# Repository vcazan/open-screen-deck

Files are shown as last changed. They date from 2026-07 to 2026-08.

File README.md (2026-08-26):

# Open Screen Deck

Six Waveshare ScreenKey modules (128×128 IPS + switch in each cap) on an
ESP32-S3 carrier you have fabricated, in a case you print. This repo is
the KiCad, Gerbers, OpenSCAD, STLs, firmware, and an optional desktop
companion.

[Build notes](https://vcazan.github.io/open-screen-deck/) ·
[Latest release](https://github.com/vcazan/open-screen-deck/releases/latest)
(macOS/Windows app + firmware `.bin`) ·
[Discord](https://discord.gg/PVCzBBeGQX)

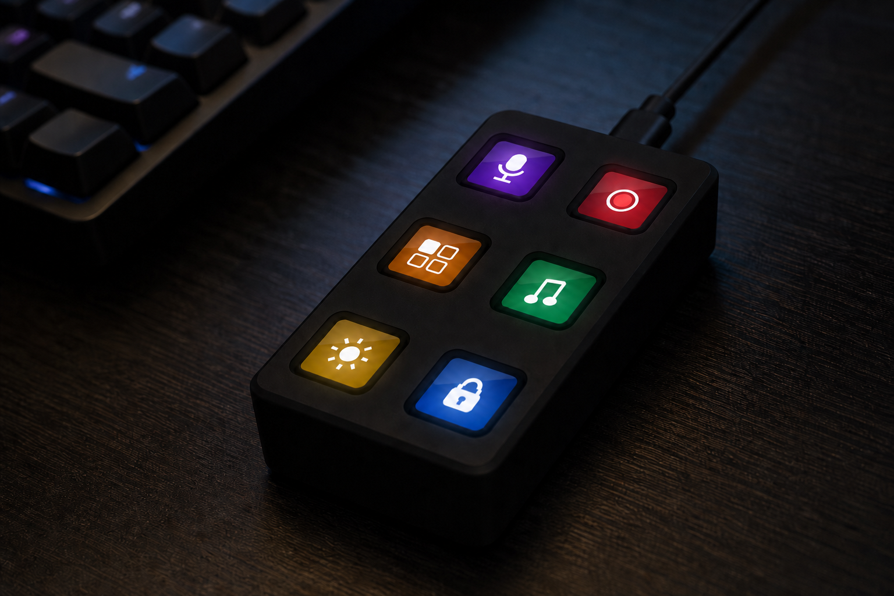
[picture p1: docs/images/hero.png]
Open Screen Deck


## Build one

1. **Order** — 6× [Waveshare 34168](https://www.waveshare.com/0.85inch-screenkey.htm?sku=34168)
   (about $66, longest lead time). Upload
   [`hardware/pcb/data_streamdeck_gerbers.zip`](hardware/pcb/data_streamdeck_gerbers.zip)
   to [JLCPCB](https://jlcpcb.com) (about $15 for five boards). Full list:
   [`hardware/bom_assembly.csv`](hardware/bom_assembly.csv)
2. **Print** while those ship — four STLs in [`hardware/enclosure/stl/`](hardware/enclosure/stl/),
   PETG or PLA+, no supports:
   `deck_bottom_v14.stl`, `deck_top_v14.stl`, `corner_spacers_x4_v14.stl`,
   optional `deck_stand_v14.stl`
3. **Assemble** — [guide](https://vcazan.github.io/open-screen-deck/build/assembly/),
   about 45 minutes
4. **Flash** over USB-C — [companion](https://github.com/vcazan/open-screen-deck/releases/latest)
   (Settings → Firmware) or Arduino /
   [esptool](https://vcazan.github.io/open-screen-deck/firmware/flashing/).
   Same release has `firmware-0.14.5.bin` plus bootloader and partitions.

Parts land around **$100**. The six modules are most of that. v14 STLs
match the **Rev E** board (59.5 × 108.5 mm); don’t mix with older v13 prints.

| | |
|--|--|
| **Keys** | 6× Waveshare 0.85″ ScreenKey (SKU 34168) |
| **Board** | ESP32-S3-WROOM-1-N16R8 on a **59.5 × 108.5 mm** Rev E carrier |
| **On board** | IMU, VEML7700 ALS, DRV2605L haptics, piezo, 8× SK6812, Qwiic |
| **Displays** | Dual SPI (J1–J3 + SD / J4–J6), 40 MHz + DMA |
| **Case** | 64.9 × 113.9 × 28.2 mm printed deck + optional 25° stand |
| **Firmware** | 0.14.5 (protocol 14) — HID keyboard F13–F24 by default |

Pinout lives in [`hardware/pinout.py`](hardware/pinout.py). Generators
refuse to run if `firmware/config.h` disagrees.

## Firmware

Sources in [`firmware/`](firmware/). Out of the box it types F13–F24.
Pages, labels, icons, microSD animations, auto-dim, glow LEDs, and haptics
are configured over USB serial
([protocol](https://vcazan.github.io/open-screen-deck/firmware/protocol/)).

Prebuilt images are on
[Releases](https://github.com/vcazan/open-screen-deck/releases/latest)
(`firmware-0.14.5.bin`, `.bootloader.bin`, `.partitions.bin`). The companion
bundles the same files. To compile locally:

```bash
./scripts/build_firmware.sh          # also copies bins into the app
./scripts/build_firmware.sh --flash  # then upload to a connected deck
```

Arduino: ESP32S3 Dev Module, USB CDC On Boot enabled, USB-OTG, OPI PSRAM,
16 MB flash (`app3M_fat9M_16MB`). Libraries: Adafruit GFX, ST7735, NeoPixel.

## Companion app

Optional. The deck is a USB keyboard without it. Use the app to draw key
faces, bind host actions, flash firmware, and (on Rev E) drive auto-dim /
glow / self-test.

- **Download:** [Releases](https://github.com/vcazan/open-screen-deck/releases/latest)
  — macOS `.dmg` (unsigned: right-click → Open), Windows `.msi`
- **From source:** `cd app && npm install && npx tauri dev`
- **Plugins:** folders in [`plugins/`](plugins/);
  [directory](https://vcazan.github.io/open-screen-deck/plugins/) ·
  [`plugins/registry.json`](plugins/registry.json)

A push to `main` updates this repo and the docs site. A **GitHub Release**
(installers + firmware bins) is created only when a tag `app-v*` is pushed,
e.g. `app-v0.2.0`.

## Repo map

```
hardware/
  pinout.py          Canonical GPIO + Rev E geometry
  pcb/               KiCad, Gerbers, board BOM
  enclosure/         OpenSCAD v14 + printable STLs
  3d/                Fastener / assembly STEP
firmware/            ESP32-S3 Arduino (0.14.5)
app/                 Tauri companion (Rust + React)
plugins/             Bundled plugins + registry.json
profiles/            Shared layouts (.osdprofile.json)
docs/                MkDocs site
scripts/             PCB / schematic / firmware helpers
```

## Contributing

- **Plugins** — folder in `plugins/` + a registry line
  ([how](https://vcazan.github.io/open-screen-deck/plugins/develop/))
- **Profiles** — export from the app, PR into `profiles/`
- **Hardware** — OpenSCAD is parametric; keep the
  [mechanical contract](docs/mechanical_contract.md) if the PCB should still fit
- **App / firmware** — `cd app && npm test && npm run test:e2e`

## Related projects

Same neighbourhood: [FreeTouchDeck](https://github.com/DustinWatts/FreeTouchDeck)
(one touchscreen), [open-deck](https://github.com/joshr120/open-deck) (one TFT
behind keys), [MacroPad](https://github.com/yuvasaro/MacroPad) (per-key OLED).
This one is six discrete ScreenKey modules on a carrier you can order.

## License

- **Firmware, app, scripts, docs:** [MIT](LICENSE)
- **Hardware (PCB + enclosure):** [CERN-OHL-P v2](hardware/LICENSE)

ScreenKey modules are a [Waveshare](https://www.waveshare.com) product; this
project is not affiliated with or endorsed by Waveshare or Elgato.

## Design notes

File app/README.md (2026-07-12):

# Open Screen Deck Configurator

Browser-based companion app for configuring the [Open Screen Deck](https://github.com/vcazan/open-screen-deck) — a 6-key macro pad with per-key 128×128 IPS LCD displays, driven by an ESP32-S3 over USB.

Configure key labels, colors, HID bindings, icons, and SD animations. Test everything in the built-in device simulator before connecting real hardware via Web Serial.

## Quick start

```bash
cd app
npm install
npm run dev      # http://localhost:5173
npm run test     # protocol unit tests
npm run build    # production bundle
```

## Architecture

```
app/src/
├── protocol/       # Serial protocol v0.4 — types, codec, RGB565 helpers
├── transport/      # Transport abstraction (simulator loopback + Web Serial)
├── simulator/      # Virtual firmware mirroring firmware/ behavior
├── ui/             # React components (deck, inspector, console)
├── hooks/          # Device connection state management
└── utils/          # Profile import/export, animation decoding
```

### Protocol layer (`protocol/`)

Implements the newline-delimited JSON protocol defined in `docs/protocol.md` v0.4:

- **Commands**: `PING`, `INFO`, `GET_KEYS`, `DRAW`, `DRAW_ALL`, `SET_KEY`, `SET_IMAGE`, `ANIM`, `SD_INFO`
- **Events**: `info`, `key`, `key_state`, `pong`, `ok`, `error`, `send_data`, `anim`, `sd`
- **Binary framing**: `SET_IMAGE` sends a JSON header, device replies `send_data`, host streams 32 768 bytes RGB565

RGB565 conversion uses big-endian byte order matching Adafruit GFX / ST7735.

### Transport layer (`transport/`)

All device I/O goes through a `Transport` interface so the app can later be wrapped in Tauri without changing UI code:

| Implementation | Purpose |
|---|---|
| `SimulatorTransport` | In-process loopback to `SimulatedDevice` (default) |
| `WebSerialTransport` | Real hardware via `navigator.serial` at 115200 baud |

### Simulator (`simulator/`)

`SimulatedDevice` is a faithful virtual firmware:

- 6 keys with label view renderer matching `drawKey()` in `firmware/display.cpp`
- Handles every protocol command identically to the ESP32 firmware
- Key presses emit `{"event":"key",...}` and simulate HID keystrokes
- NVS persistence via `localStorage` (survives page reload)
- In-memory SD card for icons and animation frame sequences

### UI (`ui/`)

Dark-themed single-page layout:

- **Left**: CSS device rendering with live 128×128 key canvases
- **Right**: Progressive-disclosure inspector for the selected key
- **Bottom**: Collapsible protocol console (TX/RX log)

## Simulator vs real hardware

| Feature | Simulator | Real device |
|---|---|---|
| Key press events | Click on deck | Physical switch |
| HID output | Shown as floating chip | Sent over USB HID |
| NVS config | `localStorage` | ESP32 Preferences |
| SD storage | `localStorage` (base64 frames) | microSD card |
| SET_IMAGE | Draws to canvas + saves icon | ST7735 + SD write |
| ANIM | Plays from in-memory frames | Reads `/osd/keys/n/anim/*.rgb565` |

The same `encodeCommand()` / `Transport.sendLine()` code drives both paths.

## Profiles

Save/load the full 6-key configuration as JSON:

```json
{
  "version": 1,
  "keys": [
    { "label": "MUTE", "sublabel": "Toggle", "hid": 183, "bg": 19049, "fg": 65535 }
  ]
}
```

Use **Save profile** / **Load profile** in the header, or **Reset defaults** to restore firmware factory labels.

## Future: Tauri wrapper

The transport abstraction is designed for a future Tauri shell:

1. Replace `WebSerialTransport` with a Tauri IPC bridge calling `serialport` crate
2. Keep `SimulatorTransport` for offline development
3. No changes needed to protocol, simulator, or UI layers

## License

Same as the parent Open Screen Deck project (MIT firmware, CERN-OHL-P hardware).

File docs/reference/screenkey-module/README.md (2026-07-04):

# Waveshare 0.85″ ScreenKey Module — Reference

Canonical mechanical + electrical reference for **Open Screen Deck**.  
Sources: [Waveshare product page (SKU 34168)](https://www.waveshare.com/0.85inch-screenkey.htm?sku=34168), [Waveshare docs](https://docs.waveshare.com/0.85inch-ScreenKey-Module-W), outline drawing (see `outline-dimensions.png`).

**Our build SKU:** 34168 — **0.85inch ScreenKey Module B** (black keycap + switch + PCB)

---

## Product variants

| SKU | Product |
|-----|---|
| 34086 | ScreenKey LCD W (display + cap only) |
| 34087 | ScreenKey LCD B |
| 34167 | ScreenKey Module W (cap + switch + PCB) |
| **34168** | **ScreenKey Module B** ← use this |

**In the box (34168):**

1. ScreenKey Module B host ×1  
2. **MX1.25 9-pin 200 mm** cable ×1  

Weight: ~0.017 kg per module

---

## Display & logic

| Parameter | Value |
|---|---|
| Panel | 0.85″ IPS |
| Resolution | 128 × 128 |
| Color | 65K (RGB565) |
| Driver IC | **ST7735** |
| Interface | 4-wire SPI |
| Operating voltage | **3.3 V** (5 V tolerant per docs — run at 3.3 V) |
| Visible display area | **15.21 × 15.21 mm** |
| Pixel pitch | 118.8 × 118.8 µm |

---

## Mechanical switch (Module W/B only)

| Parameter | Value |
|---|---|
| Actuation force | 50 ± 10 gf |
| Bottom-out force | 55 ± 10 gf |
| Actuation travel | 1.20 ± 0.30 mm |
| Total travel | 2.80 ± 0.25 mm |
| Spring length | 15.50 mm |
| Lifespan | 50 million cycles |

---

## Outline dimensions (from Waveshare drawing)

See **`outline-dimensions.png`** in this folder.

### Front (face toward user)

| Dimension | mm |
|---|-----|
| Mounting hole centres (horizontal) | **22.00** |
| Mounting hole centres (vertical) | **25.30** |
| Visible LCD (square) | **15.21 × 15.21** |

Four corner mounting holes on this 22.00 × 25.30 mm pattern.

### Back (PCB + connector)

| Dimension | mm |
|---|-----|
| PCB width | **25.94** |
| PCB height | **35.29** |

9-pin header on PCB edge ( mates with included cable ).

### Side (profile)

| Dimension | mm |
|---|-----|
| **Total stack height** (cap tip → standoff bottom) | **24.00** |
| Keycap depth (cap only) | **8.60** |

Module includes rear **brass standoffs** — total height is **not** just the 8.6 mm cap; plan enclosure depth for **~24 mm** or confirm standoffs are removed/shortened for our carrier design.

---

## 9-pin cable — SPI module interface

Connector on module: **9-pin 1.25 mm pitch** (product cable: MX1.25).  
Pin order per Waveshare docs (SPI control interface):

| Pin | Signal | Notes |
|-----|---|---|
| 1 | **KEY** | Button, active level per firmware |
| 2 | **DC** | Data/command (Lo = cmd, Hi = data) |
| 3 | **CS** | Chip select, active low |
| 4 | **SCLK** | SPI clock |
| 5 | **DIN** | SPI MOSI |
| 6 | **GND** | |
| 7 | **VCC** | 3.3 V |
| 8 | **PWM** | Backlight (BL) |
| 9 | **RST** | Reset, active low |

### Open Screen Deck GPIO map (carrier PCB)

| Module | CS | KEY |
|---|-----|-----|
| J1 | GPIO 10 | GPIO 38 |
| J2 | GPIO 1 | GPIO 39 |
| J3 | GPIO 2 | GPIO 40 |
| J4 | GPIO 3 | GPIO 41 |
| J5 | GPIO 4 | GPIO 42 |
| J6 | GPIO 5 | GPIO 47 |

Shared: MOSI=11, SCK=12, DC=14, RST=21, BL(PWM)=13

---

## ⚠️ CAD status

Enclosure v4 + PCB brief aligned to this reference (2026-07-03).

---

## Links

- Product: https://www.waveshare.com/0.85inch-screenkey.htm?sku=34168  
- Wiki: https://docs.waveshare.com/0.85inch-ScreenKey-Module-W  
- Resources: https://docs.waveshare.com/0.85inch-ScreenKey-Module-W/Resources-And-Documents  
- Demo code: Waveshare GitHub / example packages linked from wiki  

---

## Files in this folder

| File | Description |
|---|---|
| `README.md` | This document |
| `outline-dimensions.png` | Official-style outline (front / back / side) |
| `product-spec.json` | Machine-readable spec snapshot |

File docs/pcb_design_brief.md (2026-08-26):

# Open Screen Deck — Carrier PCB Design Brief (Rev E)

Reference: `docs/reference/screenkey-module/` (Waveshare **SKU 34168**)
**Canonical pinout: `hardware/pinout.py`** — both generators consume it and
cross-check `firmware/config.h` at generation time. Regenerate with
`python3 scripts/generate_kicad_pcb.py`, route with Freerouting, then run
`scripts/stitch_gnd.py` and DRC. Fab outputs live in `hardware/pcb/gerbers/`.

---

## Board specification

| Parameter | Value |
|---|---|
| PCB size | **59.5 × 108.5 mm** (Rev E — grew for uniform key spacing) |
| Shape | Rectangular (r=4 corners), 4× Ø2.2 corner case-screw holes on the corner-module standoff axes |
| Mounting | **Flat** in bottom shell (centred under key grid) |
| Layers | 2-layer |
| Min trace | 0.2 mm signal / 0.5 mm power |
| Min via | 0.3 mm drill / 0.6 mm pad |
| Finish | ENIG, matte black solder mask |

---

## Layout

### Key grid (the Rev E spacing fix)

Uniform **11 mm cap-to-cap gaps** both axes: column pitch **33.0 mm**, row
pitch **36.3 mm** (was 28.9 / 38.3 → 6.9 mm H / 13.0 mm V gaps).

| Ref | Col | Row | X | Y |
|-----|-----|-----|---|---|
| J1 | 0 | 0 | 13.25 | 17.95 |
| J2 | 1 | 0 | 46.25 | 17.95 |
| J3 | 0 | 1 | 13.25 | 54.25 |
| J4 | 1 | 1 | 46.25 | 54.25 |
| J5 | 0 | 2 | 13.25 | 90.55 |
| J6 | 1 | 2 | 46.25 | 90.55 |

### Major placements (board origin = back-left)

| Ref | Part | Position | Notes |
|-----|---|---|---|
| U1 | ESP32-S3-WROOM-1-N16R8 | (29.75, 36.1) rot 90 | Centre corridor between rows 0 and 1 |
| J7 | USB-C GCT USB4105 (horizontal) | (29.75, 3.1) rot 180 | Port exits rear edge Y=0 |
| J8 | microSD Hirose DM3D-SF | (52.0, 72.4) rot 90 | Card mouth faces x=59.5 edge (side-wall slot); gated by `check_sd_orientation.py` |
| U2 | AMS1117-3.3 1 A LDO | (11.4, 4.7) rear-left strip | VBUS→3V3; ≥3.0 mm clear of H1 screw hardware |
| U3 | USBLC6-2SC6 ESD | behind J7 | USB D+/D−/VBUS protection |
| U4 | LSM6DS3TR-C IMU | rear strip | I2C, INT1→GPIO9 (pickup/tap) |
| U5 | VEML7700 ambient light | rear strip | I2C, drives BL auto-dim |
| U6 | DRV2605L haptic driver | rear strip | I2C + EN=GPIO44, LRA on J10 |
| U7 | 74AHCT1G125 | near U1 | 3V3→5V level shift for LED data |
| J9 | Qwiic / StemmaQT (JST-SH 4P) | (49.0, 3.1) right rear edge | 3V3 I2C expansion; ≥3.0 mm clear of H2 screw hardware |
| J10 | LRA motor (JST-SH 2P) | rear strip | haptic actuator |
| BZ1 | Piezo buzzer | rear strip | GPIO43 LEDC |
| D1–D6 | SK6812MINI-E | beside each key, outer edge | per-key status color |
| D7–D8 | SK6812MINI-E | rear corners | link / SD status |
| SW1/SW2 | BOOT / RESET | front strip (42.5, 105.2) / (49.0, 105.2) | GPIO0 strap / EN; next to ALS, clear of rear-strip congestion |

---

## Connectors J1–J6

**Molex PicoBlade 53261-0971** — 9-pin 1.25 mm right-angle SMD.
The 200 mm cable included in every Waveshare module box plugs straight in
(pin 1 → pin 1; verify straight-through before buying spares).

### Pin order (Waveshare SPI module — pin 1 = KEY)

| Pin | Signal | Bus A modules (J1–J3) | Bus B modules (J4–J6) |
|-----|---|---|---|
| 1 | KEY | GPIO per table below | GPIO per table below |
| 2 | DC | GPIO 14 (DC_A) | GPIO 8 (DC_B) |
| 3 | CS | GPIO per table below | GPIO per table below |
| 4 | SCLK | GPIO 12 (SCK_A) | GPIO 18 (SCK_B) |
| 5 | DIN | GPIO 11 (MOSI_A) | GPIO 17 (MOSI_B) |
| 6 | GND | GND | GND |
| 7 | VCC | +3V3 | +3V3 |
| 8 | PWM | GPIO 13 (BL, LEDC) | GPIO 13 (BL, LEDC) |
| 9 | RST | GPIO 21 (shared) | GPIO 21 (shared) |

### Per-module GPIO

| Module | Bus | CS | KEY |
|---|-----|-----|-----|
| J1 | A | 10 | 38 |
| J2 | A | 1 | 39 |
| J3 | A | 2 | 40 |
| J4 | B | 3 | 41 |
| J5 | B | 4 | 42 |
| J6 | B | 5 | 47 |

**Dual SPI**: bus A (FSPI) also carries the microSD (CS=16, MISO=15) at
10 MHz; panels run 40 MHz with DMA on both buses simultaneously —
full-deck redraw drops ~60 ms → ~15-18 ms.

### Other subsystem GPIO

| Signal | GPIO | Notes |
|---|---|---|
| SDA / SCL | 6 / 7 | I2C: IMU + ALS + haptics + Qwiic |
| IMU_INT | 9 | LSM6DS3TR-C INT1, wake-on-pickup |
| LED_DATA | 48 | SK6812 chain, 5 V via 74AHCT1G125 |
| PIEZO | 43 | LEDC tone |
| HAPTIC_EN | 44 | DRV2605L EN |

All chosen pins avoid IO35–37 (octal PSRAM) and leave the strap pins clean.

---

## Decoupling

- **C1–C6:** 100 nF 0402 on each Jx pin 7 (VCC), ≤2 mm from connector
- **C7/C8:** 10 µF 0805 bulk at LDO in/out
- **C9/C10:** 100 nF at U1; **C11** 1 µF on EN
- 100 nF at U4, U5, U6, U7 + 10 µF near the LED chain 5 V feed

---

## Mounting holes

All Ø2.2 (M2 free fit):

- **H1–H4 corner case screws** @ **(3.25, 3.32), (56.25, 3.32), (3.25, 105.17), (56.25, 105.17)** —
  on the corner modules' outermost soldered-nut axes (M2×25 case screws,
  see `docs/mechanical_contract.md`)
- **H5–H16 module standoffs** @ the usable positions of the **20.0 × 29.25**
  per-module pattern from the official vendor drawing (positions colliding
  with ESP32 / USB-C / microSD skipped)

**Hardware keepouts** (component courtyards, measured from hole centre):
≥ **3.0 mm** at H1–H4 (M2 spacer/nut seats on the board face) and
≥ **2.0 mm** at H5–H16 (Ø3.5 mm brass standoff foot; ≥2.5 mm preferred).
Violations at H1/H2/H14 (U2, J9, C14) were found and fixed in Rev E.

---

## Never-again gates (CS2/CS3 class defects)

1. `hardware/pinout.py` is the only pin source; generators fail if
   `firmware/config.h` diverges.
2. `check_dangling_nets` — every signal net must land on ≥2 pads
   (single-pad nets are invisible to DRC; this exact defect shipped Rev B–D).
3. Pre-Gerber connectivity gate: schematic netlist vs PCB pad diff for
   every connector pin.
4. Firmware `SELFTEST` draws each panel's index + cycles LEDs at bring-up.

---

## BOM (deltas vs Rev D marked ★)

| Qty | Ref | Part |
|-----|-----|---|
| 6 | J1–J6 | Molex PicoBlade 53261-0971 (MX1.25 9P) |
| 1 | U1 | ESP32-S3-WROOM-1-N16R8 |
| 1 | J7 | GCT USB4105-GF-A USB-C |
| 1 | J8 | Hirose DM3D-SF microSD |
| 1 | U2 | ★ AMS1117-3.3 (1 A) |
| 1 | U3 | USBLC6-2SC6 |
| 1 | U4 | ★ LSM6DS3TR-C IMU |
| 1 | U5 | ★ VEML7700 ambient light |
| 1 | U6 | ★ DRV2605L haptic driver |
| 1 | U7 | ★ 74AHCT1G125 level shifter |
| 8 | D1–D8 | ★ SK6812MINI-E RGB LED |
| 1 | BZ1 | ★ SMT piezo buzzer (CUI CPT-9019S) |
| 1 | J9 | ★ JST-SH 4P (Qwiic) |
| 1 | J10 | ★ JST-SH 2P (LRA motor) |
| 1 | — | ★ LRA coin motor (8 mm) |
| — | C/R | 0402/0805 passives per schematic |
| 4 | — | M2×25 case screws + RX-M2x4 inserts |

Added BOM cost ≈ **$4–6/board**.

---

## Fabrication

- **59.5 × 108.5 mm** 2-layer FR4 1.6 mm, ENIG
- JLCPCB / PCBWay: ~$15 / 5 pcs

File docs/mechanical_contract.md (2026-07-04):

# Mechanical Contract — Enclosure ↔ PCB (v11 / Tier B)

Single source of truth for physical interfaces.  
**Module reference:** `docs/reference/screenkey-module/` (Waveshare SKU **34168**)

---

## Outer envelope (v11 — flat deck + separate stand)

Architecture follows the Elgato Stream Deck Module reference: the deck body is
a **flat slab**; a **separate printed stand** provides the desk angle.

| Parameter | Value |
|---|---|
| Deck width (X) | **59.7 mm** |
| Deck depth (Y) | **116.7 mm** |
| Deck height | **28.2 mm** (+3.4 mm keycap protrusion) |
| Parting plane | **Z = 12 mm** (bottom tray / top shell) |
| Stand angle | **25°** (separate print, cradle style) |
| Stack | floor 3.0 → posts 3.0 → PCB 1.6 → standoff/spacer 9.7 → module body 5.7 → gap 0.2 → face plate 5.0 |

---

## Carrier PCB (Tier B — fab-ready)

| Parameter | Value |
|---|---|
| Board outline | **55 × 112 mm** |
| Orientation | Flat in bottom shell, centred under key grid |
| MCU | **ESP32-S3-WROOM-1-N16R8** soldered on board |
| USB | **USB-C receptacle** on PCB @ **X=27.5 mm, Y=0** (rear edge) |
| Storage | **microSD** @ **X=47.5 mm, Y=75 mm** (right-wall access slot, between J4/J6) |
| ScreenKey | 6× JST GH 9P @ J1–J6 (see below) |

### Corner case-screw holes H1–H4 (Ø2.2, board origin = back-left)

These sit on the **corner modules' outermost standoff axes** — the case
screws thread through the modules' soldered nuts (see Fasteners below).

| Hole | X | Y |
|---|---|---|
| H1 | 2.0 | 4.95 |
| H2 | 52.9 | 4.95 |
| H3 | 2.0 | 106.85 |
| H4 | 52.9 | 106.85 |

Plus 12× Ø2.2 module-standoff holes (H5–H16) at the remaining usable
standoff positions.

### J1–J6 connector centres

| Ref | X | Y |
|-----|---|---|
| J1 | 13.0 | 17.6 |
| J2 | 41.9 | 17.6 |
| J3 | 13.0 | 55.9 |
| J4 | 41.9 | 55.9 |
| J5 | 13.0 | 94.2 |
| J6 | 41.9 | 94.2 |

**Pin order (Waveshare):** 1=KEY, 2=DC, 3=CS, 4=SCLK, 5=DIN, 6=GND, 7=VCC, 8=PWM, 9=RST  
**Receptacle:** Molex **PicoBlade 53261-0971** (= "MX1.25") — the in-box Waveshare cable mates directly.

---

## USB-C (PCB-mounted)

| Parameter | Value |
|---|---|
| Connector | GCT USB4115-03-C class (rear-facing) |
| PCB position | Centre **X = 27.5 mm**, flush **Y = 0** rear edge |
| Enclosure slot | 10.5 × 4.8 mm @ rear wall (unchanged) |
| Power | USB 5 V → on-board 3.3 V LDO |

**No DevKit pocket.** One USB-C cable plugs directly into the deck.

---

## microSD (media storage)

| Parameter | Value |
|---|---|
| Connector | Hirose DM3D-SF class push-push |
| PCB position | **X = 47.5 mm, Y = 75 mm** (card ejects through right wall) |
| Enclosure | Right-wall slot in bottom shell @ PCB Y=75 |
| Filesystem | FAT32, `/osd/` tree (see `docs/product_architecture.md`) |

---

## Fasteners (v11 — one-screw corner stack)

The ScreenKey module is a **dual-PCB sandwich**: front PCB (switch/LCD) and
rear PCB (9P connector) joined by **soldered M2 nuts** at the 22.0 × 25.3
pattern. The factory brass standoffs **unscrew from those nuts** — the nuts
are the mounting threads, and they are **through-threads**: a long screw can
pass through and keep going. The module is off-the-shelf and is never
modified — only its removable standoffs are swapped where needed.

**The 4 case screws ARE the corner-module screws.** At each deck corner one
long M2 runs the entire stack:

```
M2×25 countersunk head (DIN 965, flush in the rubber-foot recess)
  → tray floor (3.0)
  → PCB perch post (3.0)
  → carrier corner hole H1–H4 (Ø2.2 @ kicad 2/52.9, 4.95/106.85)
  → printed spacer sleeve Ø4×9.7 (replaces the factory standoff,
    open Ø2.4 bore)
  → corner module's soldered M2 nut (threads through)
  → RX-M2x4 insert in the top-shell face plate (4 mm engagement)
```

One screw per corner marries **bottom tray + carrier + module + top shell**.

**Assembly order:**

```
1. Modules → carrier:  M2×5 from the carrier underside into the factory
                       standoff tips (12 non-corner positions). At the
                       4 deck corners swap the factory standoff for the
                       printed spacer sleeve.
2. Cables:             6× in-box PicoBlade cables, module → carrier.
3. Carrier → tray:     drop onto the 4 corner posts.
4. Close:              snap top shell on (tongue + snaps), then 4× M2×25
                       from below, straight through the corner modules'
                       nuts into the top-plate inserts.
```

| Joint | Hardware | Receives |
|---|---|---|
| Whole stack (tray + carrier + module + top) | 4× **M2×25 countersunk flat head** (DIN 965) from below, hidden under the rubber feet | Corner module's **soldered M2 nut** (pass-through), then **Ruthex RX-M2x4** insert in the top-shell plate |
| Module → carrier | 12× **M2×5 hex socket cap** (ISO 4762) from carrier underside | Module's **factory brass standoffs** (female M2 tips) |
| Corner spacing | 4× **printed spacer sleeve** Ø4 × 9.7, Ø2.4 bore (`stl/corner_spacers_x4_v11.stl`) | sits between carrier and corner-module nut |
| Feet | 8× Ø10 self-adhesive rubber (deck + stand); the 4 deck feet cover the corner screw heads | — |

The factory standoffs (and corner sleeves) are 9.7 mm — exactly clearing the
mated PicoBlade cable under each module. Standoffs at the 8 skipped positions
(over ESP32 / USB-C / microSD) are simply unscrewed.

Real CAD models (in the Fusion assembly + `hardware/3d/fasteners/`):
official **Ruthex** STEP files and **ISO-standard screws** from step.parts.

Install the 4 RX-M2x4 inserts in the top-plate holes with a soldering iron
@ ~220 °C before assembly.
Full parts list: `hardware/bom_assembly.csv` (PCB-only: `hardware/pcb/bom.csv`).

---

## Assembly stack

```
Top shell → 6× ScreenKey modules (24 mm bays)
         → MX1.25/JST cables
Bottom   → Carrier PCB (ESP32 + USB-C + SD + J1–J6)
         → M3 standoffs → enclosure bosses
```

---

## Verification

- [ ] Gerbers ordered from `hardware/pcb/gerbers/`
- [ ] USB-C aligns with rear slot when PCB on standoffs
- [ ] microSD accessible without opening top shell
- [x] **Corner nut is a through-thread** — confirmed from module photos
  (open corner holes on the front face); M2×25 passes through and exits
  toward the top-plate insert
- [ ] Real 34168 module fits top bays
- [ ] **Keycap aperture:** `CAP_W = 19.4` in the SCAD is an estimate — measure a
  real cap and adjust before final print
- [ ] Deck seats in stand cradle; USB cable clears stand rear

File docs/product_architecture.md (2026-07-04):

# Product Architecture — Fab-Ready Open Screen Deck

**Revision:** 2.0 (Tier B)  
**Status:** Target production design — no socketed dev kit, no “works on breadboard” shortcuts.

---

## What changed from Tier A

| Tier A (prototype) | Tier B (this design) |
|---|---|
| ESP32-S3 **DevKitC-1** in a side pocket | **ESP32-S3-WROOM-1-N16R8** soldered on carrier |
| USB via dev board pigtail | **USB-C receptacle on PCB** → rear enclosure slot |
| Static labels in firmware only | **microSD + USB streaming + NVS profiles** |
| Schematic-only carrier | **Routed 2-layer PCB**, Gerbers, JLCPCB BOM |
| “Companion app later” | **Storage model defined now** |

Tier A was for proving fit and HID. Tier B is what you fabricate.

---

## Where display content lives (your video question)

You asked where videos are saved and why we were cutting corners. Here is the honest answer.

### Three storage tiers (all supported in v2 firmware roadmap)

```
┌─────────────────────────────────────────────────────────────┐
│  Tier 1 — On-device flash (16 MB, inside ESP32 module)      │
│  • Factory bootloader, firmware, WiFi cal                   │
│  • NVS: key maps, brightness, last profile name           │
│  • Optional small built-in icon pack (~200 KB)              │
│  ✗ NOT for video — too small, wear-sensitive               │
└─────────────────────────────────────────────────────────────┘
┌─────────────────────────────────────────────────────────────┐
│  Tier 2 — microSD on carrier PCB (primary local media)      │
│  /osd/                                                      │
│    profiles/streaming.json                                  │
│    keys/0/icon.png                                          │
│    keys/0/anim/0001.rgb565   ← animation frames           │
│    keys/0/anim/meta.json     ← fps, loop, frame count      │
│  • FAT32, hot-swappable before power-on                     │
│  • Ship a 1–32 GB card with starter pack                    │
└─────────────────────────────────────────────────────────────┘
┌─────────────────────────────────────────────────────────────┐
│  Tier 3 — Host via USB CDC (live / heavy content)           │
│  • Companion app pushes RGB565 frames or GIF decode on PC   │
│  • No SD write needed for one-off icons                     │
│  • Best for long GIFs or frequent updates while plugged in  │
└─────────────────────────────────────────────────────────────┘
```

**Videos on 6× 128×128 keys:** there is no magic internal RAM for six simultaneous 30 fps streams.

| Fact | Number |
|---|---|
| One frame (RGB565) | 32 768 bytes |
| One key @ 15 fps | ~480 KB/s on SPI |
| Six keys @ 15 fps (parallel) | ~2.9 MB/s — **impossible** on one shared SPI bus |

**Product behavior (not a corner cut — physics):**

- **Static icons** — from SD or USB, all keys updated independently.
- **Short animations** — SD folder per key; firmware plays frames on **one key at a time** or low fps on **one active key**.
- **“Live video” look** — companion app streams frames over USB while plugged in (Tier 3).
- **Stream Deck parity** — Elgato also renders on the host; keys show bitmaps pushed over USB. We do the same, plus SD for standalone mode.

We were wrong to imply DevKit + hardcoded text was the end state. That was **Phase 1 bring-up only**.

---

## Hardware block diagram

```
USB-C (5 V) ──► Fuses/ESD ──► 3.3 V LDO ──► +3V3 rail
                    │              │
                    │              ├── ESP32-S3-WROOM-1 (16 MB flash, 8 MB PSRAM)
                    │              ├── 6× ScreenKey via JST GH / MX1.25
                    │              └── microSD (SPI, shared bus)
                    └── USB D+/D- ──► ESP32 native USB (HID + CDC)
```

### GPIO map (canonical)

| Function | GPIO | Notes |
|---|---|---|
| MOSI | 11 | Shared: displays + SD |
| MISO | 15 | SD read |
| SCK | 12 | Shared |
| DC | 14 | Displays |
| RST | 21 | Displays |
| BL (PWM) | 13 | All backlights tied |
| CS1–CS6 | 10,1,2,3,4,5 | Per ScreenKey |
| KEY1–KEY6 | 38,39,40,41,42,47 | Pull-ups on PCB |
| SD_CS | 16 | microSD |
| USB D- | 19 | Native USB |
| USB D+ | 20 | Native USB |
| BOOT | 0 | Boot strap button |

---

## PCB (fab package)

| Item | Value |
|---|---|
| Outline | **55 × 112 mm** |
| Layers | 2 (F.Cu / B.Cu) |
| Mounting | **4× M3** @ (4,4), (51,4), (4,108), (51,108) |
| Connectors | 6× JST GH 9P 1.25 mm horizontal |
| USB | **USB-C receptacle** @ board rear center (X=27.5, Y=0 edge) |
| SD | microSD push-push @ bottom edge (service slot in enclosure) |
| Finish | ENIG, **1.6 mm**, matte black mask |

Generate layout:

```bash
./scripts/build_hardware.sh
```

Outputs: `hardware/pcb/data_streamdeck.kicad_pcb`, `hardware/pcb/gerbers/`, `hardware/pcb/bom.csv`

---

## Enclosure alignment

- USB slot in bottom shell aligns with **PCB-mounted USB-C**, not a dev kit.
- DevKit pocket **removed** — single flat carrier + modules in top shell.
- Optional **microSD access cutout** in bottom shell (left-rear).

---

## Firmware roadmap (storage-aware)

| Version | Capability |
|---|---|
| v0.2 (now) | HID + CDC + static labels |
| v0.3 | `SET_KEY`, RGB565 `SET_IMAGE` over USB |
| v0.4 | SD mount, `/osd/` profile load, animation player |
| v0.5 | Companion sync: USB pushes profile → optional SD write |

See `docs/protocol.md` for wire format extensions.

---

## BOM class

Full line-item BOM: `hardware/pcb/bom.csv`  
Assembly notes: `docs/fab_checklist.md`

**Estimated board cost (JLCPCB, qty 5, ENIG):** ~$18–25 PCB + ~$12 SMT (ESP32 module + passives) if you use assembly.

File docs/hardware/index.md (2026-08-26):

# Hardware Overview

A 2×3 of Waveshare ScreenKey modules (128×128 LCD + switch each) on an
ESP32-S3 carrier, in a printed case. You fabricate the board, print the
shells, and screw the modules on — sources are in `hardware/`.

**Rev E** is the current layout: dual SPI to the panels, IMU, ambient
light, haptics, eight edge-glow LEDs, and a Qwiic port.

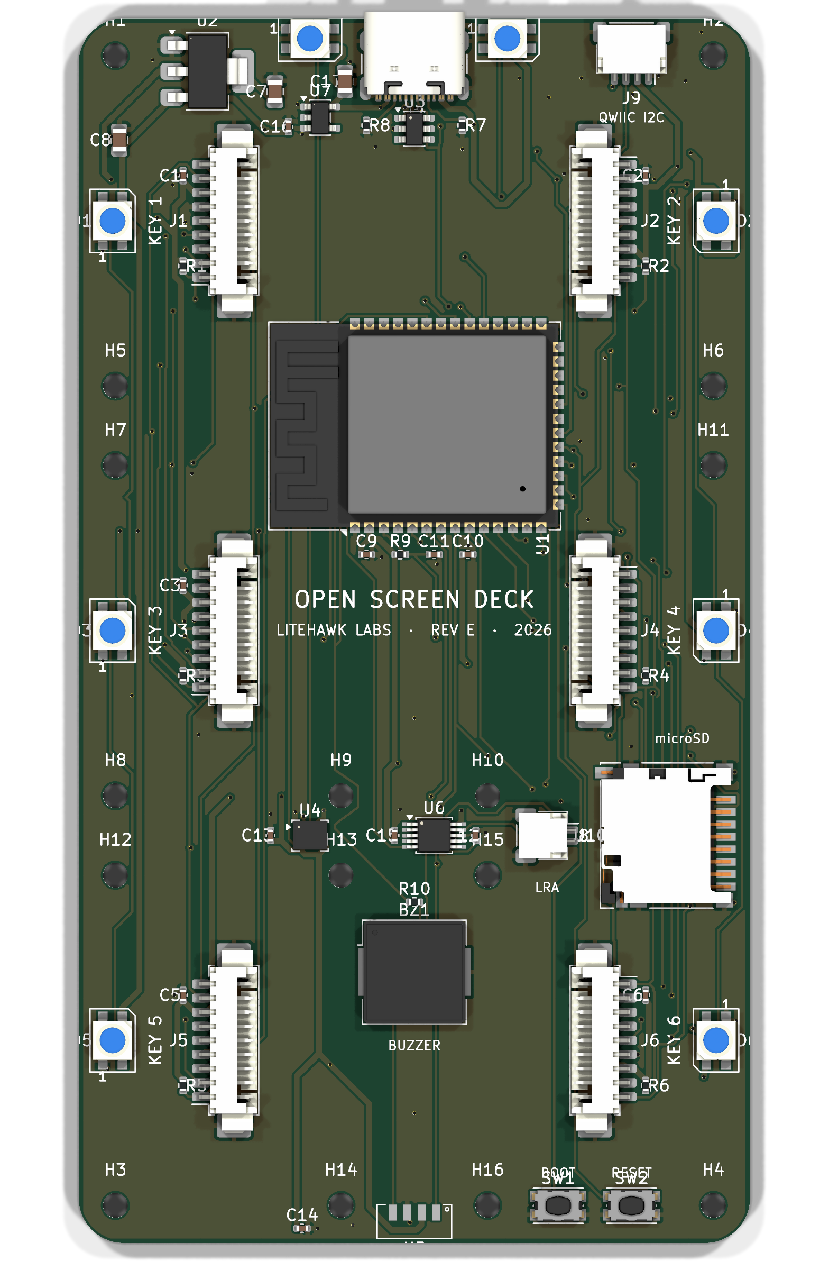
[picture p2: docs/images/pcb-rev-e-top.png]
Rev E carrier


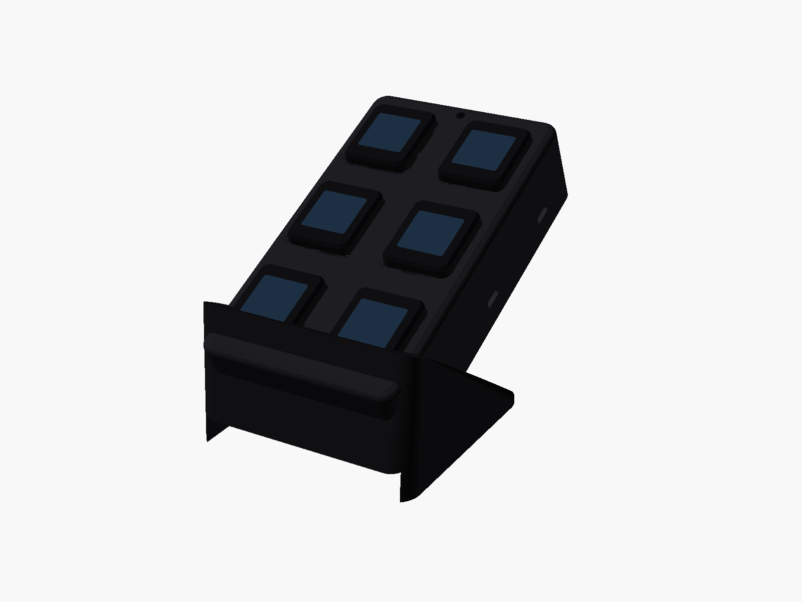
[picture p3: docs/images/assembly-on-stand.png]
Assembled deck on the 25° stand


## Specifications

| | |
|--|--|
| **Keys** | 6× Waveshare 0.85″ ScreenKey (SKU 34168) — LCD + mechanical switch in one module |
| **Screens** | 128×128 IPS per key, ST7735, **dual SPI** (J1–J3 + SD on bus A, J4–J6 on bus B) |
| **MCU** | ESP32-S3-WROOM-1-N16R8 (16 MB flash, 8 MB PSRAM) soldered on carrier |
| **Carrier PCB** | **59.5 × 108.5 mm**, 2-layer, ENIG, matte black |
| **Sensors** | LSM6DS3TR-C IMU (pickup/tap), VEML7700 ambient light (auto-dim) |
| **Feedback** | DRV2605L haptic driver + LRA jack, piezo, 8× SK6812MINI-E edge glow |
| **Expansion** | Qwiic / StemmaQT on the shared I2C bus |
| **Host link** | USB-C → HID keyboard (F13–F24) + CDC serial at 115200 baud |
| **Media** | microSD for on-device icons/animations, or stream frames over USB |
| **Enclosure** | v14: **64.9 × 113.9 × 28.2 mm** flat deck + optional 25° stand; LED wall windows + ALS light-pipe |
| **Fasteners** | 4× M2×25 corner screws through module nuts; 12× M2×5 module screws |

## Source files

All hardware sources live in the GitHub repo:

| Component | Location |
|---|---|
| Canonical pinout | [`hardware/pinout.py`](https://github.com/vcazan/open-screen-deck/blob/main/hardware/pinout.py) |
| KiCad schematic + PCB | [`hardware/pcb/`](https://github.com/vcazan/open-screen-deck/tree/main/hardware/pcb/) |
| OpenSCAD enclosure | [`hardware/enclosure/`](https://github.com/vcazan/open-screen-deck/tree/main/hardware/enclosure/) |
| Printable STLs | [`hardware/enclosure/stl/`](https://github.com/vcazan/open-screen-deck/tree/main/hardware/enclosure/stl/) |
| Fastener / assembly STEP | [`hardware/3d/`](https://github.com/vcazan/open-screen-deck/tree/main/hardware/3d/) |
| Assembly BOM | [`hardware/bom_assembly.csv`](https://github.com/vcazan/open-screen-deck/blob/main/hardware/bom_assembly.csv) |

## Order a PCB

1. Generate fab outputs: `./scripts/build_hardware.sh`
2. Upload `hardware/pcb/data_streamdeck_gerbers.zip` to
   [JLCPCB](https://jlcpcb.com) (~$15 for five boards)
3. SMT assembly is recommended on Rev E — IMU, ALS, haptic driver, and
   eight 3535 LEDs are fiddly by hand. Component list in `hardware/pcb/bom.csv`

See the [Fab Checklist](../build/fab-checklist.md) for pre-order verification
and bring-up tests.

## Deep dives

- [Mechanical contract](mechanical.md) — enclosure ↔ PCB interfaces, fasteners
- [PCB design brief](pcb.md) — layout, pinout, sensors, connectors
- [ScreenKey module reference](screenkey-module.md) — Waveshare SKU 34168 specs
- [Product architecture](architecture.md) — media storage, dual SPI, I2C

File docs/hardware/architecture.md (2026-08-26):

# System Architecture

How the electronics, storage, and data paths fit together. Canonical
pinout: [`hardware/pinout.py`](https://github.com/vcazan/open-screen-deck/blob/main/hardware/pinout.py).

## Block diagram

```
USB-C (5 V) ──► Fuses/ESD ──► 3.3 V LDO ──► +3V3 rail
                    │              │
                    │              ├── ESP32-S3-WROOM-1 (16 MB flash, 8 MB PSRAM)
                    │              ├── 6× ScreenKey via PicoBlade (MX1.25) 9-pin
                    │              ├── microSD (SPI bus A)
                    │              ├── I2C: IMU + VEML7700 + DRV2605L + Qwiic
                    │              ├── 8× SK6812MINI-E (5 V, level-shifted)
                    │              └── piezo + LRA jack
                    └── USB D+/D- ──► ESP32 native USB (HID keyboard + CDC serial)
```

One USB-C cable does everything: power, the HID keyboard the OS sees, and
the CDC serial channel the companion app configures the deck through.

## GPIO map (canonical)

Displays use **two SPI buses** so a full-deck redraw does not serialize
six panels on one clock.

| Function | GPIO | Notes |
|---|---|---|
| MOSI_A / SCK_A / DC_A | 11 / 12 / 14 | SPI bus A: J1–J3 + microSD |
| MISO | 15 | SD read (displays are write-only) |
| SD_CS | 16 | microSD |
| MOSI_B / SCK_B / DC_B | 17 / 18 / 8 | SPI bus B: J4–J6 |
| RST | 21 | All six panels, both buses |
| BL (PWM) | 13 | All backlights; ALS auto-dim |
| CS1–CS6 | 10, 1, 2, 3, 4, 5 | Per ScreenKey |
| KEY1–KEY6 | 38, 39, 40, 41, 42, 47 | Pull-ups on PCB |
| SDA / SCL | 6 / 7 | I2C: IMU + ALS + haptic + Qwiic |
| IMU_INT | 9 | LSM6DS3TR-C INT1 (pickup / tap) |
| LED_DATA | 48 | SK6812 chain via 74AHCT1G125 |
| PIEZO | 43 | LEDC tone |
| HAPTIC_EN | 44 | DRV2605L enable |
| USB D− / D+ | 19 / 20 | Native USB |
| BOOT | 0 | Boot strap button |

This table is the single pinout truth — firmware, schematic, and PCB all
match `hardware/pinout.py`. The generators refuse to run if they disagree.

## On-board sensors & feedback (Rev E)

| Device | Bus | Job |
|---|-----|-----|
| **LSM6DS3TR-C** | I2C + INT on GPIO9 | Pickup / tap — haptic tick when the deck is lifted |
| **VEML7700** | I2C | Lux → backlight PWM through a Ø3 light-pipe in the face plate |
| **DRV2605L** | I2C, EN=GPIO44 | LRA effect library; key-press click |
| **Piezo** | GPIO43 | Optional beep (`CLICKBEEP`) |
| **8× SK6812MINI-E** | GPIO48 @ 5 V | Logical 0–5 = keys J1–J6, 6 = USB link, 7 = SD |
| **Qwiic** | same I2C | Extra sensors out the rear wall next to USB-C |

The companion's **Settings → Deck hardware** card (protocol 14+) exposes
auto-dim, brightness, glow colour, click-beep, and a `SELFTEST` that
walks panels, LEDs, haptic, and piezo.

## Where key media lives

Icons and animations have three homes, each with a job:

| Tier | Holds | Why |
|---|---|-----|
| **ESP32 flash (NVS)** | key configs: labels, colors, HID codes, page count, orientation | tiny, survives reboot, no SD needed |
| **microSD** | icons (`/osd/keys/n/icon.rgb565`) and animation frames (`/osd/keys/n/anim/0001.rgb565` …) | big, persistent — the deck plays media standalone |
| **USB stream** | live frames (`SET_FACE`) | tiles, plugin faces, previews — draw-only, zero flash/SD wear |

The companion app writes persistent media to SD over USB (`SET_IMAGE` /
`SET_ANIM`) and streams everything live-only via `SET_FACE`. Full wire
format: [serial protocol](../firmware/protocol.md).

## Bandwidth budget

Two display buses plus DMA mean a full-deck static redraw is ~15–18 ms.
Animation and USB streaming still have to share those buses with the
microSD card on bus A:

| Fact | Number |
|---|---|
| One frame (128×128 RGB565) | 32 768 bytes |
| One key @ 15 fps | ~480 KB/s on SPI |
| USB CDC (ESP32-S3 full-speed) | ~1 MB/s real-world |

So the design rules are:

- **Static icons** — any number, updated independently
- **Animations** — one key animates at a time from SD, 1–30 fps
- **Live tiles / plugin faces** — streamed over USB at 0.3–2 fps per key,
  which fits comfortably alongside everything else

## PCB summary

| Item | Value |
|---|---|
| Outline | **59.5 × 108.5 mm**, 2-layer, ENIG, 1.6 mm, matte black |
| MCU | ESP32-S3-WROOM-1-N16R8, soldered |
| Connectors | 6× PicoBlade (MX1.25) 9-pin — the modules' in-box cables plug straight in |
| USB | USB-C receptacle at the rear edge (X=29.75, Y=0) |
| SD | microSD push-push, service slot in the enclosure side wall |
| Expansion | Qwiic on the rear wall; LRA on J10 |

Generate the fab package with `./scripts/build_hardware.sh` → Gerbers in
`hardware/pcb/gerbers/`, BOM in `hardware/pcb/bom.csv`. Details:
[PCB design](pcb.md) · [mechanical](mechanical.md) ·
[fab checklist](../build/fab-checklist.md).

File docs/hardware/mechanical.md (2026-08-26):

# Mechanical Contract — Enclosure ↔ PCB (v14 / Rev E)

Single source of truth for physical interfaces.  
**Module reference:** [ScreenKey Module](screenkey-module.md) (Waveshare SKU **34168**)  
**Pinout / grid:** [`hardware/pinout.py`](https://github.com/vcazan/open-screen-deck/blob/main/hardware/pinout.py)

---

## Outer envelope (v14 — Rev E pitch + glow)

The deck body is a flat slab; a separate printed stand provides the desk angle.
v14 follows the Rev E key pitch (uniform 11 mm cap-to-cap) and adds LED
wall windows, an ALS light-pipe, and a Qwiic opening next to USB-C.

| Parameter | Value |
|---|---|
| Deck width (X) | **64.9 mm** |
| Deck depth (Y) | **113.9 mm** |
| Deck height | **28.2 mm** body (+ keycap protrusion) |
| Parting plane | **Z = 12 mm** (bottom tray / top shell) |
| Stand angle | **25°** (separate print, cradle style) |
| Glow | 8 wall windows (3 left, 3 right, 2 rear) for SK6812MINI-E |
| ALS | Ø3 mm light-pipe through the face plate to the VEML7700 |
| Qwiic | JST-SH opening in the rear wall next to USB-C |
| Stack | floor 3.0 → posts 3.0 → PCB 1.6 → standoff/spacer 8.0 → module body 7.4 → gap 0.2 → face plate 5.0 |

---

## Carrier PCB (Rev E)

| Parameter | Value |
|---|---|
| Board outline | **59.5 × 108.5 mm** |
| Key grid | Col pitch **33.0 mm**, row pitch **36.3 mm** |
| Orientation | Flat in bottom shell, centred under key grid |
| MCU | **ESP32-S3-WROOM-1-N16R8** soldered on board |
| USB | **USB-C receptacle** on PCB @ **X=29.75 mm, Y=0** (rear edge) |
| Storage | **microSD** @ **X=52.0 mm, Y=72.4 mm** (side access slot) |
| ScreenKey | 6× PicoBlade 9P @ J1–J6 |

### Corner case-screw holes H1–H4 (Ø2.2, board origin = back-left)

These sit on the **corner modules' outermost standoff axes** — the case
screws thread through the modules' soldered nuts (see Fasteners below).

| Hole | X | Y |
|---|---|---|
| H1 | 3.25 | 3.32 |
| H2 | 56.25 | 3.32 |
| H3 | 3.25 | 105.17 |
| H4 | 56.25 | 105.17 |

Plus 12× Ø2.2 module-standoff holes (H5–H16) at the remaining usable
standoff positions.

### J1–J6 connector centres

| Ref | X | Y |
|-----|---|---|
| J1 | 13.25 | 17.95 |
| J2 | 46.25 | 17.95 |
| J3 | 13.25 | 54.25 |
| J4 | 46.25 | 54.25 |
| J5 | 13.25 | 90.55 |
| J6 | 46.25 | 90.55 |

**Pin order (Waveshare):** 1=KEY, 2=DC, 3=CS, 4=SCLK, 5=DIN, 6=GND, 7=VCC, 8=PWM, 9=RST  
**Receptacle:** Molex **PicoBlade 53261-0971** (= "MX1.25") — the in-box Waveshare cable mates directly.  
**SPI:** J1–J3 on bus A (shared with microSD), J4–J6 on bus B.

---

## USB-C (PCB-mounted)

| Parameter | Value |
|---|---|
| Connector | GCT USB4105 class (rear-facing) |
| PCB position | Centre **X = 29.75 mm**, flush **Y = 0** rear edge |
| Enclosure slot | Rear wall, next to the Qwiic opening |
| Power | USB 5 V → on-board 3.3 V LDO |

One USB-C cable plugs directly into the deck — power, HID, and config.

---

## microSD (media storage)

| Parameter | Value |
|---|---|
| Connector | Hirose DM3D-SF class push-push |
| PCB position | **X = 52.0 mm, Y = 72.4 mm**, card mouth toward the x=59.5 edge |
| Enclosure | Side-wall slot in the bottom shell |
| Filesystem | FAT32, `/osd/` tree (see [Architecture](architecture.md)) |

---

## Fasteners (one-screw corner stack)

The ScreenKey module is a **dual-PCB sandwich**: front PCB (switch/LCD) and
rear PCB (9P connector) joined by **soldered M2 nuts** at the 20.0 × 29.25
pattern. The factory brass standoffs **unscrew from those nuts** — the nuts
are the mounting threads, and they are **through-threads**: a long screw can
pass through and keep going. The module is off-the-shelf and is never
modified — only its removable standoffs are swapped where needed.

**The 4 case screws ARE the corner-module screws.** At each deck corner one
long M2 runs the entire stack:

```
M2×25 countersunk head (DIN 965, flush in the rubber-foot recess)
  → tray floor (3.0)
  → PCB perch post (3.0)
  → carrier corner hole H1–H4 (Ø2.2)
  → printed spacer sleeve Ø4×8.0 (replaces the factory standoff,
    open Ø2.4 bore)
  → corner module's soldered M2 nut (threads through)
  → RX-M2x4 insert in the top-shell face plate (4 mm engagement)
```

One screw per corner marries **bottom tray + carrier + module + top shell**.

**Assembly order:**

```
1. Modules → carrier:  M2×5 from the carrier underside into the factory
                       standoff tips (12 non-corner positions). At the
                       4 deck corners swap the factory standoff for the
                       printed spacer sleeve.
2. Cables:             6× in-box PicoBlade cables, module → carrier.
3. Carrier → tray:     drop onto the 4 corner posts.
4. Close:              snap top shell on (tongue + snaps), then 4× M2×25
                       from below, straight through the corner modules'
                       nuts into the top-plate inserts.
```

| Joint | Hardware | Receives |
|---|---|---|
| Whole stack (tray + carrier + module + top) | 4× **M2×25 countersunk flat head** (DIN 965) from below, hidden under the rubber feet | Corner module's **soldered M2 nut** (pass-through), then **Ruthex RX-M2x4** insert in the top-shell plate |
| Module → carrier | 12× **M2×5 hex socket cap** (ISO 4762) from carrier underside | Module's **factory brass standoffs** (female M2 tips) |
| Corner spacing | 4× **printed spacer sleeve** Ø4 × 8.0, Ø2.4 bore (`stl/corner_spacers_x4_v14.stl`) | sits between carrier and corner-module nut |
| Feet | 8× Ø10 self-adhesive rubber (deck + stand); the 4 deck feet cover the corner screw heads | — |

The factory standoffs (and corner sleeves) are 8.0 mm — exactly clearing the
mated PicoBlade cable under each module. Standoffs at the skipped positions
(over ESP32 / USB-C / microSD) are simply unscrewed.

Real CAD models (in the Fusion assembly + `hardware/3d/fasteners/`):
official **Ruthex** STEP files and **ISO-standard screws** from step.parts.

Install the 4 RX-M2x4 inserts in the top-plate holes with a soldering iron
@ ~220 °C before assembly.
Full parts list: `hardware/bom_assembly.csv` (PCB-only: `hardware/pcb/bom.csv`).

---

## Assembly stack

```
Top shell → 6× ScreenKey modules (24 mm bays)
         → MX1.25/JST cables
Bottom   → Carrier PCB (ESP32 + USB-C + SD + sensors + J1–J6)
         → enclosure posts
```

---

## Verification

- [ ] Gerbers ordered from `hardware/pcb/gerbers/` (Rev E, 59.5 × 108.5 mm)
- [ ] USB-C aligns with rear slot when PCB on posts
- [ ] Qwiic opening lines up with J9
- [ ] microSD accessible without opening top shell
- [ ] LED wall windows sit over D1–D8
- [ ] ALS light-pipe hole sits over the VEML7700
- [x] **Corner nut is a through-thread** — confirmed from module photos
- [x] **Keycap aperture:** official vendor drawing — cap is 21.89 × 25.13 mm, apertures at +0.6 mm clearance
- [ ] Deck seats in stand cradle; USB cable clears stand rear

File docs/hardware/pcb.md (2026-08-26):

# Carrier PCB Design Brief (Rev E)

Reference: [ScreenKey Module](screenkey-module.md) (Waveshare **SKU 34168**)  
**Canonical pinout: [`hardware/pinout.py`](https://github.com/vcazan/open-screen-deck/blob/main/hardware/pinout.py)** — schematic and PCB generators consume it and hard-fail if `firmware/config.h` disagrees.

**Status: routed + DRC-clean.** Fab outputs live in `hardware/pcb/gerbers/`.

Rev E carrier, top

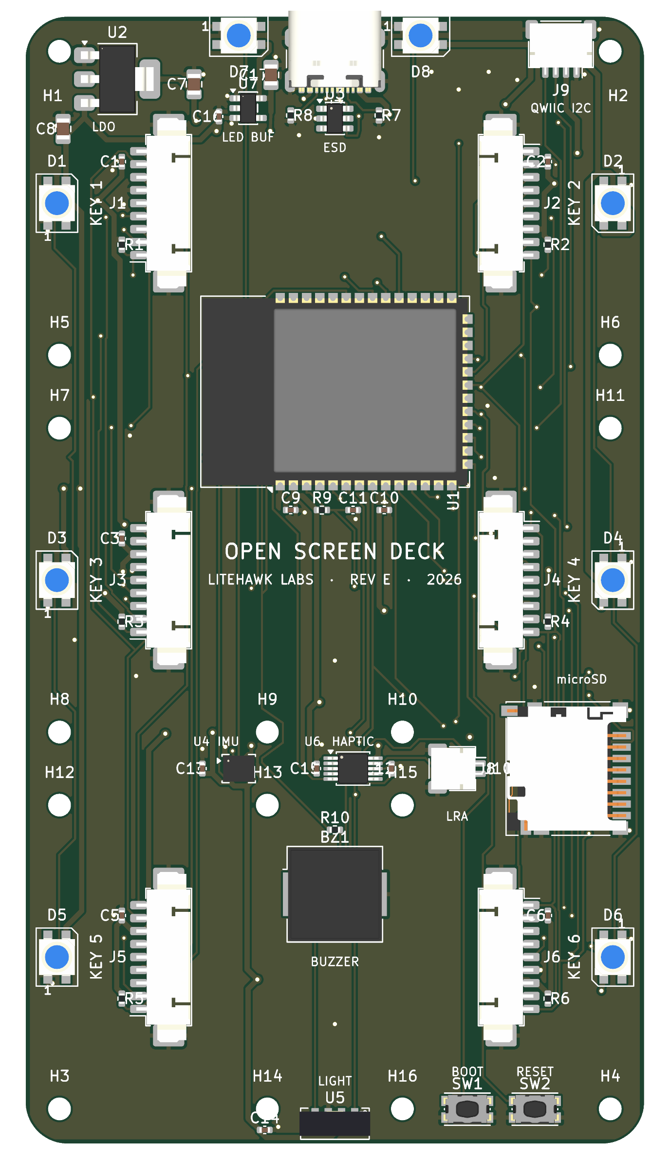
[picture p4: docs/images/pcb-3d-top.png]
Rev E 3D top


---

## What's new in Rev E

Rev D was a working 6-key carrier. Rev E keeps that layout and adds the
on-board sensing and feedback the enclosure was designed around:

| Subsystem | Part | What it does |
|---|---|---|
| **IMU** | LSM6DS3TR-C | Pickup / tap detect — the deck ticks when you lift it |
| **Ambient light** | VEML7700 | Auto-dims the six backlights through a face-plate light pipe |
| **Haptics** | DRV2605L + LRA jack | Click feedback on key press; optional coin motor on J10 |
| **Piezo** | CUI CPT-9019S | Optional beep alongside (or instead of) the LRA |
| **Edge glow** | 8× SK6812MINI-E | Per-key status (6) + rear link/SD indicators (2), 5 V via a level shifter |
| **Qwiic** | JST-SH 4P | Extra I2C sensors on the same bus, out the rear wall |

Also in this rev: **uniform 11 mm cap-to-cap gaps** (the board grew to
**59.5 × 108.5 mm**), **dual SPI** so a full-deck redraw is ~15 ms instead
of ~60 ms, and a single pinout source so firmware and copper cannot drift.

Added board cost is about **$4–6**.

---

## Board specification

| Parameter | Value |
|---|---|
| PCB size | **59.5 × 108.5 mm** |
| Shape | Rectangular (r=4 corners), 4× Ø2.2 corner case-screw holes on the corner-module standoff axes |
| Mounting | **Flat** in bottom shell (centred under key grid) |
| Layers | 2-layer |
| Min trace | 0.2 mm signal / 0.5 mm power |
| Min via | 0.3 mm drill / 0.6 mm pad |
| Finish | ENIG, matte black solder mask |

---

## Layout

Uniform **11 mm cap-to-cap gaps** both axes: column pitch **33.0 mm**, row
pitch **36.3 mm**.

### J1–J6 centres (board origin 0,0 = back-left)

| Ref | Col | Row | X | Y |
|-----|-----|-----|---|---|
| J1 | 0 | 0 | 13.25 | 17.95 |
| J2 | 1 | 0 | 46.25 | 17.95 |
| J3 | 0 | 1 | 13.25 | 54.25 |
| J4 | 1 | 1 | 46.25 | 54.25 |
| J5 | 0 | 2 | 13.25 | 90.55 |
| J6 | 1 | 2 | 46.25 | 90.55 |

### Major placements

| Ref | Part | Notes |
|-----|---|---|
| U1 | ESP32-S3-WROOM-1-N16R8 | Centre corridor between rows 0 and 1 |
| J7 | USB-C GCT USB4105 | Port exits rear edge, centred at X=29.75 |
| J8 | microSD Hirose DM3D-SF | Card mouth faces the x=59.5 edge (side-wall slot) |
| U2 | AMS1117-3.3 1 A LDO | Rear-left strip, VBUS → 3V3 |
| U3 | USBLC6-2SC6 ESD | USB D+/D−/VBUS |
| U4 | LSM6DS3TR-C IMU | I2C, INT1 → GPIO9 |
| U5 | VEML7700 ALS | I2C, drives backlight auto-dim |
| U6 | DRV2605L haptic | I2C + EN=GPIO44, LRA on J10 |
| U7 | 74AHCT1G125 | 3.3 V → 5 V LED data |
| J9 | Qwiic / StemmaQT | Rear edge next to USB |
| J10 | LRA motor (JST-SH 2P) | Optional haptic actuator |
| BZ1 | Piezo | GPIO43 LEDC |
| D1–D6 | SK6812MINI-E | Beside each key, outer edge |
| D7–D8 | SK6812MINI-E | Rear corners — link / SD |
| SW1 / SW2 | BOOT / RESET | Front strip, clear of the rear sensors |

---

## Connectors J1–J6

**Molex PicoBlade 53261-0971** — 9-pin 1.25 mm right-angle SMD.

The 200 mm cable included in every Waveshare module box plugs straight in
(pin 1 → pin 1; verify straight-through before buying spares).

### Pin order (Waveshare SPI module — pin 1 = KEY)

| Pin | Signal | Bus A (J1–J3) | Bus B (J4–J6) |
|-----|---|---|---|
| 1 | KEY | GPIO per table below | GPIO per table below |
| 2 | DC | GPIO 14 (DC_A) | GPIO 8 (DC_B) |
| 3 | CS | GPIO per table below | GPIO per table below |
| 4 | SCLK | GPIO 12 (SCK_A) | GPIO 18 (SCK_B) |
| 5 | DIN | GPIO 11 (MOSI_A) | GPIO 17 (MOSI_B) |
| 6 | GND | GND | GND |
| 7 | VCC | +3V3 | +3V3 |
| 8 | PWM | GPIO 13 (BL, LEDC) | GPIO 13 (shared) |
| 9 | RST | GPIO 21 (shared) | GPIO 21 (shared) |

### Per-module GPIO

| Module | Bus | CS | KEY |
|---|-----|-----|-----|
| J1 | A | 10 | 38 |
| J2 | A | 1 | 39 |
| J3 | A | 2 | 40 |
| J4 | B | 3 | 41 |
| J5 | B | 4 | 42 |
| J6 | B | 5 | 47 |

**Dual SPI:** bus A (FSPI) also carries the microSD (CS=16, MISO=15).
Panels run 40 MHz with DMA on both buses at once.

### Other subsystem GPIO

| Signal | GPIO | Notes |
|---|---|---|
| SDA / SCL | 6 / 7 | I2C: IMU + ALS + haptics + Qwiic |
| IMU_INT | 9 | LSM6DS3TR-C INT1, wake-on-pickup |
| LED_DATA | 48 | SK6812 chain, 5 V via 74AHCT1G125 |
| PIEZO | 43 | LEDC tone |
| HAPTIC_EN | 44 | DRV2605L EN |

Pins avoid IO35–37 (octal PSRAM) and leave the boot-strap pins clean.

---

## Decoupling

- **C1–C6:** 100 nF 0402 on each Jx pin 7 (VCC), ≤2 mm from connector
- **C7/C8:** 10 µF 0805 bulk at LDO in/out
- **C9/C10:** 100 nF at U1; **C11** 1 µF on EN
- 100 nF at U4, U5, U6, U7 + 10 µF near the LED chain 5 V feed

---

## Mounting holes

All Ø2.2 (M2 free fit):

- **H1–H4 corner case screws** @ **(3.25, 3.32), (56.25, 3.32), (3.25, 105.17), (56.25, 105.17)** —
  on the corner modules' outermost soldered-nut axes (M2×25 case screws,
  see [Mechanical](mechanical.md))
- **H5–H16 module standoffs** @ the usable positions of the **20.0 × 29.25**
  per-module pattern from the official vendor drawing

---

## BOM

| Qty | Ref | Part |
|-----|-----|---|
| 1 | U1 | ESP32-S3-WROOM-1-N16R8 (soldered) |
| 6 | J1–J6 | Molex PicoBlade 53261-0971 — 9-pin 1.25 mm right-angle |
| 1 | J7 | USB-C receptacle, GCT USB4105 |
| 1 | J8 | microSD, Hirose DM3D-SF push-push |
| 1 | U2 | AMS1117-3.3 1 A LDO |
| 1 | U3 | USBLC6-2SC6 USB ESD protection |
| 1 | U4 | LSM6DS3TR-C 6-axis IMU |
| 1 | U5 | VEML7700 ambient light |
| 1 | U6 | DRV2605L haptic driver |
| 1 | U7 | 74AHCT1G125 LED data level shifter |
| 8 | D1–D8 | SK6812MINI-E RGB LED |
| 1 | BZ1 | SMT piezo (CUI CPT-9019S) |
| 1 | J9 | JST-SH 4P Qwiic / StemmaQT |
| 1 | J10 | JST-SH 2P LRA motor |
| 2 | SW1, SW2 | BOOT / RESET tactile switches |
| 6 | — | Waveshare MX1.25 9P cable (included with each module) |

Full line-item board BOM: `hardware/pcb/bom.csv`. Case fasteners and feet
are in the [parts list](../getting-started/parts.md).

---

## Fabrication

- **59.5 × 108.5 mm** 2-layer FR4 1.6 mm, ENIG
- JLCPCB / PCBWay: ~$15 / 5 pcs

See the [Fab Checklist](../build/fab-checklist.md) for ordering and bring-up.

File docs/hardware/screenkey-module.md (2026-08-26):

# Waveshare 0.85″ ScreenKey Module — Reference

Canonical mechanical + electrical reference for **Open Screen Deck**.  
Sources: [Waveshare product page (SKU 34168)](https://www.waveshare.com/0.85inch-screenkey.htm?sku=34168), [Waveshare docs](https://docs.waveshare.com/0.85inch-ScreenKey-Module-W), outline drawing (see below).

**Our build SKU:** 34168 — **0.85inch ScreenKey Module B** (black keycap + switch + PCB)

---

## Product variants

| SKU | Product |
|-----|---|
| 34086 | ScreenKey LCD W (display + cap only) |
| 34087 | ScreenKey LCD B |
| 34167 | ScreenKey Module W (cap + switch + PCB) |
| **34168** | **ScreenKey Module B** ← use this |

**In the box (34168):**

1. ScreenKey Module B host ×1  
2. **MX1.25 9-pin 200 mm** cable ×1  

Weight: ~0.017 kg per module

---

## Display & logic

| Parameter | Value |
|---|---|
| Panel | 0.85″ IPS |
| Resolution | 128 × 128 |
| Color | 65K (RGB565) |
| Driver IC | **ST7735** |
| Interface | 4-wire SPI |
| Operating voltage | **3.3 V** (5 V tolerant per docs — run at 3.3 V) |
| Visible display area | **15.21 × 15.21 mm** |
| Pixel pitch | 118.8 × 118.8 µm |

---

## Mechanical switch (Module W/B only)

| Parameter | Value |
|---|---|
| Actuation force | 50 ± 10 gf |
| Bottom-out force | 55 ± 10 gf |
| Actuation travel | 1.20 ± 0.30 mm |
| Total travel | 2.80 ± 0.25 mm |
| Spring length | 15.50 mm |
| Lifespan | 50 million cycles |

---

## Outline dimensions (from Waveshare drawing)

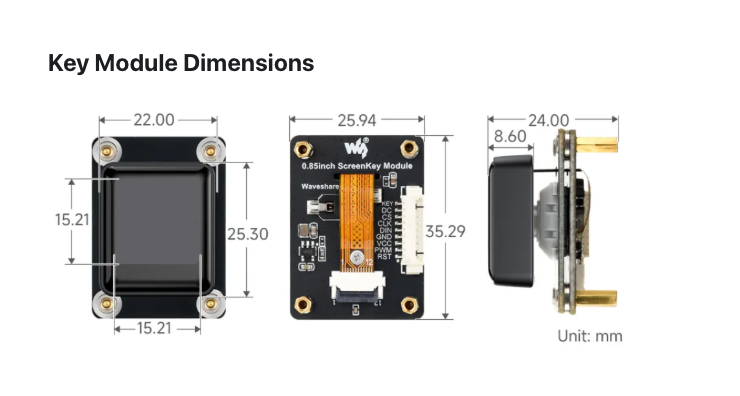
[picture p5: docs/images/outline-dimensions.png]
Outline dimensions


### Front (face toward user)

| Dimension | mm |
|---|-----|
| Mounting hole centres (horizontal) | **22.00** |
| Mounting hole centres (vertical) | **25.30** |
| Visible LCD (square) | **15.21 × 15.21** |

Four corner mounting holes on this 22.00 × 25.30 mm pattern.

### Back (PCB + connector)

| Dimension | mm |
|---|-----|
| PCB width | **25.94** |
| PCB height | **35.29** |

9-pin header on PCB edge ( mates with included cable ).

### Side (profile)

| Dimension | mm |
|---|-----|
| **Total stack height** (cap tip → standoff bottom) | **24.00** |
| Keycap depth (cap only) | **8.60** |

Module includes rear **brass standoffs** — total height is **not** just the 8.6 mm cap; plan enclosure depth for **~24 mm** or confirm standoffs are removed/shortened for our carrier design.

---

## 9-pin cable — SPI module interface

Connector on module: **9-pin 1.25 mm pitch** (product cable: MX1.25).  
Pin order per Waveshare docs (SPI control interface):

| Pin | Signal | Notes |
|-----|---|---|
| 1 | **KEY** | Button, active level per firmware |
| 2 | **DC** | Data/command (Lo = cmd, Hi = data) |
| 3 | **CS** | Chip select, active low |
| 4 | **SCLK** | SPI clock |
| 5 | **DIN** | SPI MOSI |
| 6 | **GND** | |
| 7 | **VCC** | 3.3 V |
| 8 | **PWM** | Backlight (BL) |
| 9 | **RST** | Reset, active low |

### Open Screen Deck GPIO map (carrier PCB)

| Module | CS | KEY |
|---|-----|-----|
| J1 | GPIO 10 | GPIO 38 |
| J2 | GPIO 1 | GPIO 39 |
| J3 | GPIO 2 | GPIO 40 |
| J4 | GPIO 3 | GPIO 41 |
| J5 | GPIO 4 | GPIO 42 |
| J6 | GPIO 5 | GPIO 47 |

Shared: dual SPI — J1–J3 use MOSI=11, SCK=12, DC=14; J4–J6 use MOSI=17, SCK=18, DC=8. Shared RST=21, BL(PWM)=13. microSD sits on bus A (CS=16, MISO=15). Canonical table: [`hardware/pinout.py`](https://github.com/vcazan/open-screen-deck/blob/main/hardware/pinout.py).

---

## CAD status

Rev E PCB + enclosure v14 aligned to the official vendor drawing
(20.0 × 29.25 standoff pattern; dual SPI on the carrier).

---

## Links

- Product: https://www.waveshare.com/0.85inch-screenkey.htm?sku=34168  
- Wiki: https://docs.waveshare.com/0.85inch-ScreenKey-Module-W  
- Resources: https://docs.waveshare.com/0.85inch-ScreenKey-Module-W/Resources-And-Documents  
- Demo code: Waveshare GitHub / example packages linked from wiki

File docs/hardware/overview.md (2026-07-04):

# Hardware Overview

Open Screen Deck is a 6-key macro pad where every key is a self-contained
128×128 LCD module on a custom ESP32-S3 carrier PCB, in a 3D-printed case.

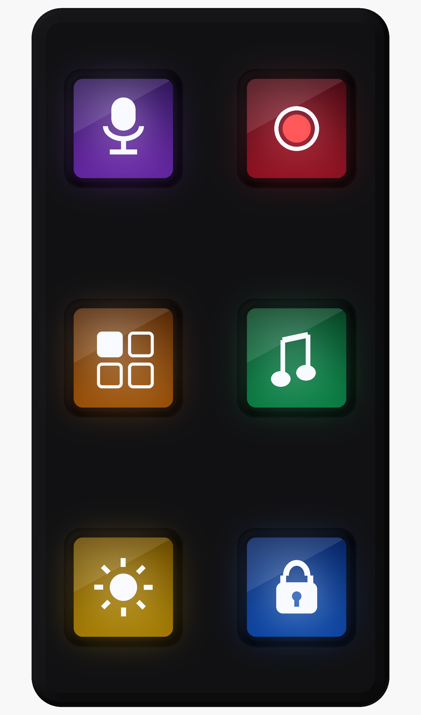
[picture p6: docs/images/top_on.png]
Top view render


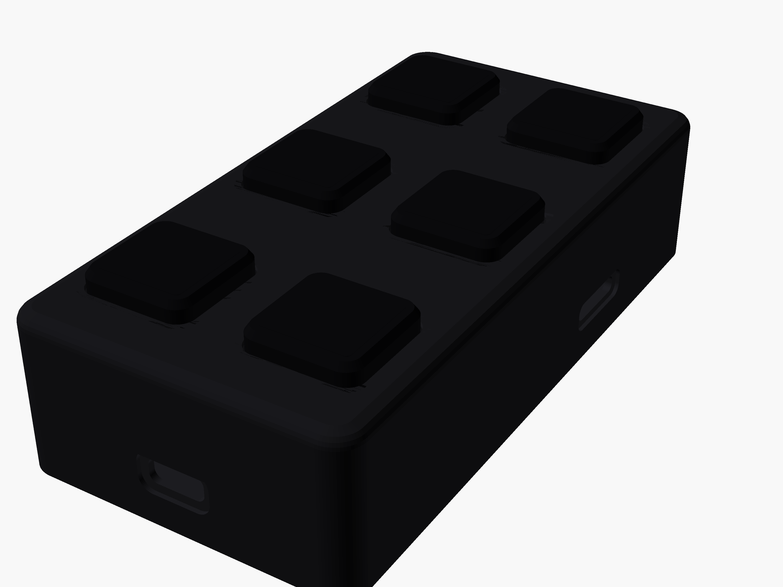
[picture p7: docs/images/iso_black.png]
Isometric render


## Specifications

| | |
|--|--|
| **Keys** | 6× Waveshare 0.85″ ScreenKey (SKU 34168) — LCD + mechanical switch in one module |
| **Screens** | 128×128 IPS per key, ST7735, shared SPI |
| **MCU** | ESP32-S3-WROOM-1-N16R8 (16 MB flash, 8 MB PSRAM) soldered on carrier |
| **Carrier PCB** | 55 × 112 mm, 2-layer, ENIG, matte black |
| **Host link** | USB-C → HID keyboard (F13–F18) + CDC serial at 115200 baud |
| **Media** | microSD for on-device icons/animations, or stream frames over USB |
| **Enclosure** | 59.7 × 116.7 × 28.2 mm flat deck + optional 25° stand |
| **Fasteners** | 4× M2×25 corner screws through module nuts; 12× M2×5 module screws |

## Source files

All hardware sources live in the GitHub repo:

| Component | Location |
|---|---|
| KiCad schematic + PCB | [`hardware/pcb/`](https://github.com/vcazan/open-screen-deck/tree/main/hardware/pcb/) |
| OpenSCAD enclosure | [`hardware/enclosure/`](https://github.com/vcazan/open-screen-deck/tree/main/hardware/enclosure/) |
| Printable STLs | [`hardware/enclosure/stl/`](https://github.com/vcazan/open-screen-deck/tree/main/hardware/enclosure/stl/) |
| Fastener STEP models | [`hardware/3d/`](https://github.com/vcazan/open-screen-deck/tree/main/hardware/3d/) |
| Assembly BOM | [`hardware/bom_assembly.csv`](https://github.com/vcazan/open-screen-deck/blob/main/hardware/bom_assembly.csv) |

## Order a PCB

1. Generate fab outputs: `./scripts/build_hardware.sh`
2. Upload `hardware/pcb/data_streamdeck_gerbers.zip` to
   [JLCPCB](https://jlcpcb.com) (~$15 for five boards)
3. SMT assembly is optional — component list in `hardware/pcb/bom.csv`

See the [Fab Checklist](../build/fab-checklist.md) for pre-order verification
and bring-up tests.

## Deep dives

- [Mechanical contract](mechanical.md) — enclosure ↔ PCB interfaces, fasteners
- [PCB design brief](pcb.md) — layout, pinout, connectors
- [ScreenKey module reference](screenkey-module.md) — Waveshare SKU 34168 specs
- [Product architecture](architecture.md) — media storage and SPI bandwidth

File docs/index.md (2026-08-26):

# Open Screen Deck

<p class="hero-tagline">
Six mechanical keys, each with its own 128×128 screen, on an ESP32-S3
carrier you order and a case you print. KiCad, Gerbers, OpenSCAD, STLs,
firmware, and a desktop companion all live in the
<a href="https://github.com/vcazan/open-screen-deck">GitHub repo</a>.
Nothing here is sold as a kit — you build it.
</p>

<p class="hero-actions">
  <a class="md-button md-button--primary" href="getting-started/parts/">
    Start a build
  </a>
  <a id="dl-mac" class="md-button"
     href="https://github.com/vcazan/open-screen-deck/releases/latest">
    macOS app
  </a>
  <a id="dl-win" class="md-button"
     href="https://github.com/vcazan/open-screen-deck/releases/latest">
    Windows app
  </a>
</p>

Open Screen Deck

## How a build goes

Order the six ScreenKey modules first — they take the longest. While they
ship, send the Gerbers to a board house and print the case. Assembly is
four corner screws and the in-box cables. Then flash over USB-C.

1. **[Order parts](getting-started/parts.md)** — six Waveshare 34168
   modules (about $66), a Rev E PCB from JLCPCB, M2 screws, inserts, feet.
   Whole bill is about $100.
2. **[Print the case](getting-started/printing.md)** — four STLs, PETG or
   PLA+, no supports. Do this while the PCB is in transit.
3. **[Assemble](build/assembly.md)** — heat-set four inserts, screw the
   modules to the carrier, plug the cables, close the shell. About 45
   minutes if you've soldered once.
4. **[Flash firmware](firmware/flashing.md)** — Arduino IDE or the
   companion app. After that it enumerates as a USB keyboard.

The [build overview](build/index.md) is the same four steps with links.

## What's in the repo

<div class="grid cards" markdown>

-   :material-chip:{ .lg .middle } __Hardware__

    ---

    KiCad project and Gerbers for the Rev E carrier (59.5 × 108.5 mm),
    OpenSCAD + printable STLs, pinout in `hardware/pinout.py`. Order five
    boards, keep one, remix the rest.

    [:octicons-arrow-right-24: Parts](getting-started/parts.md) ·
    [PCB](hardware/pcb.md) ·
    [Enclosure](hardware/mechanical.md)

-   :material-flash:{ .lg .middle } __Firmware__

    ---

    Arduino sketch for the ESP32-S3. Out of the box it types F13–F24.
    Pages, icons, animations, and the Rev E sensors (IMU, ambient light,
    haptics, glow LEDs) are configured over serial.

    [:octicons-arrow-right-24: Flashing](firmware/flashing.md) ·
    [Protocol](firmware/protocol.md)

-   :material-puzzle:{ .lg .middle } __Companion app__

    ---

    Optional. The deck works as a HID keyboard without it. Use the app
    when you want to draw key faces, assign host actions, or flash a
    newer firmware. Plugins are ordinary folders; scaffold one in-app.

    [:octicons-arrow-right-24: Using the app](app/index.md) ·
    [Write a plugin](plugins/develop.md)

</div>

## Once it's together

Plug it in — keys send F13–F24 until you change them. The companion (macOS
or Windows, or [build it from `app/`](app/development.md)) talks over the
same USB-C cable:

- Click a key to set label, colour, icon, GIF, or a host action (launch,
  hotkey, URL, shell, mic, OBS, …)
- Up to 8 pages on the device; layouts save as profiles you can share
- Plugins draw their own faces (clocks, tickers, progress) — list is in
  the [plugin directory](plugins/index.md)
- Settings can flash firmware and, on Rev E, drive auto-dim, glow, and a
  hardware self-test

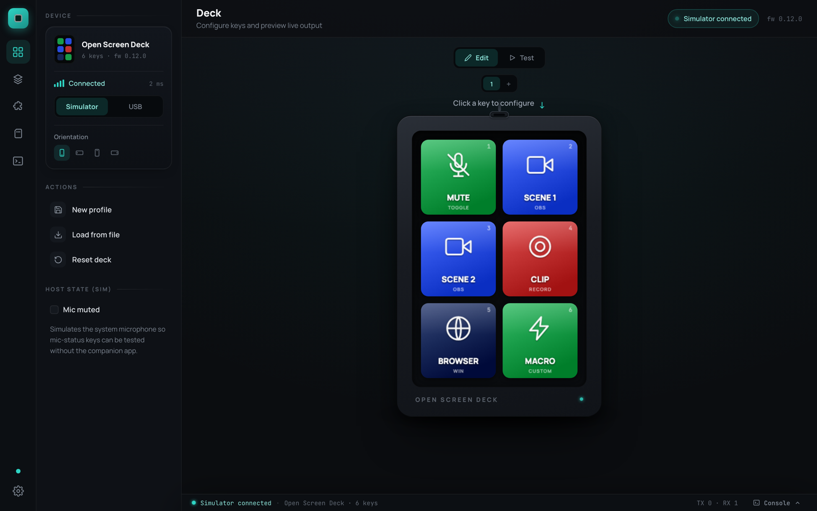
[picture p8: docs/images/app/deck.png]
Companion app


## Specs (Rev E)

| | |
|--|--|
| **Keys** | 6× Waveshare 0.85″ ScreenKey — 128×128 IPS + switch per key |
| **Pages** | up to 8 × 6 = 48 slots, switched on the device |
| **MCU** | ESP32-S3-WROOM-1 (16 MB flash, 8 MB PSRAM) |
| **Carrier** | 59.5 × 108.5 mm, 2-layer, dual SPI to the panels |
| **On board** | IMU, VEML7700 ALS, haptic driver, piezo, 8× SK6812, Qwiic |
| **Host** | USB-C → HID keyboard + CDC serial |
| **Case** | 64.9 × 113.9 × 28.2 mm printed deck + optional 25° stand |
| **Parts** | ~$100 ($66 is the six modules) |

!!! note "Photos"
    Hardware pictures are CAD or board renders until more assembled units
    are documented. App screenshots are from the real UI.

<script>
(function () {
  fetch('https://api.github.com/repos/vcazan/open-screen-deck/releases/latest')
    .then(function (r) { return r.ok ? r.json() : null; })
    .then(function (rel) {
      if (!rel || !rel.assets) return;
      function wire(id, test) {
        var asset = rel.assets.find(test);
        var a = document.getElementById(id);
        if (asset && a) a.href = asset.browser_download_url;
      }
      wire('dl-mac', function (a) { return /\.dmg$/i.test(a.name); });
      wire('dl-win', function (a) { return /\.(msi|exe)$/i.test(a.name); });
      var v = document.getElementById('dl-version');
      if (v && rel.tag_name) {
        v.textContent = 'Companion ' + rel.tag_name + ' — optional; the deck runs as a keyboard without it';
      }
    })
    .catch(function () {});
})();
</script>

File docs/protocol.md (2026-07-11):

# Serial Protocol (v0.9)

USB **CDC serial** at **115200 baud**, newline-terminated lines.  
No custom kernel driver — companion app opens the CDC port (Web Serial or Tauri).

## Device → Host (unsolicited)

Boot:

```json
{"event":"info","name":"Open Screen Deck","fw":"0.9.0","proto":9,"keys":6,"mode":"hid"}
```

Key press / release:

```json
{"event":"key","index":0,"action":"press"}
{"event":"key","index":0,"action":"release"}
```

## Host → Device

| Command | Response |
|---|---|
| `PING` | `{"event":"pong"}` (doubles as companion heartbeat) |
| `MODE COMPANION` | suppress on-device HID; companion routes key events (v0.7+) |
| `MODE HID` | restore on-device HID typing (v0.7+) |
| `INFO` | info object (includes `sd` + `psram`) |
| `GET_KEYS` | one `key_state` line per key |
| `DRAW 0` | redraw key 0 |
| `DRAW_ALL` | stop animation, redraw all keys |
| `SET_KEY {...}` | update label/sublabel/hid/bg/ov; persists to NVS. `ov:1` draws text over SD media at render time (v0.8+) |
| `SET_IMAGE {...}` + raw bytes | push 128×128 RGB565 frame to a key |
| `SET_ANIM {...}` + raw bytes | write one animation frame to SD (v0.5+) |
| `ANIM 0 10` | play SD animation on key 0 at 10 fps |
| `ANIM STOP` | stop animation, restore icon |
| `ANIM_CLEAR 0` | delete all animation frames for key 0 (v0.5+) |
| `SD_INFO` | SD card size/usage |
| `SET_ORIENT 0..3` | deck orientation: 0 portrait, 1 landscape CW, 2 flipped, 3 landscape CCW (v0.9+). Rotates all displays, remaps key positions row-major, persists to NVS |
| `SD_LS /osd/keys` | list a directory (v0.6+) |
| `SD_RM /osd/keys/0/icon.rgb565` | delete a file or empty dir (v0.6+) |

### Companion mode (v0.7+)

While the desktop companion app is connected it sends `MODE COMPANION`
followed by `PING` every 2 s. In this mode the firmware **does not type
HID keys** — it only emits `key` events, and the companion executes the
configured action (launch app, hotkey, mic mute, …). If no heartbeat
arrives for 6 s (app quit, cable pulled), the firmware falls back to
plain HID F13–F24 automatically. The deck always works standalone.

### `SET_KEY`

```json
SET_KEY {"index":0,"label":"MUTE","sublabel":"Mic","hid":104,"bg":19049}
```

`hid` = Arduino HID code (KEY_F13 = 240 on the ESP32 core; use value from `GET_KEYS`).
`bg` = RGB565 as decimal. Persisted to NVS — survives reboot.

String fields are optional: omit `label`/`sublabel` to keep the current value,
send an explicit empty string (`"label":""`) to clear it.

### `SET_IMAGE`

```json
SET_IMAGE {"index":0,"len":32768}
```

Device replies `{"event":"send_data"}`; host then sends exactly 32 768 raw
RGB565 bytes (big-endian per Adafruit GFX). Frame is drawn immediately and
saved to SD as `/osd/keys/0/icon.rgb565` when a card is mounted.

**Transparency (v0.9.1+):** icon pixels with the sentinel value `0x0821`
(bytes `08 21`) are replaced by the key's current `bg` color at draw time —
recoloring a key never requires re-uploading its image. The companion app
writes this sentinel for transparent regions of logos and PNGs.

### `SET_ANIM` (v0.5+)

```json
SET_ANIM {"index":0,"frame":1,"len":32768}
```

Same handshake as `SET_IMAGE`: device replies `{"event":"send_data"}`, host
sends 32 768 raw RGB565 bytes. The frame is written to
`/osd/keys/0/anim/0001.rgb565` (frame numbers are **1-based**, max 999).
Requires a mounted SD card — errors with `bad_anim_header` otherwise.

Typical upload sequence from the companion app:

```
ANIM_CLEAR 0                              → ok
SET_ANIM {"index":0,"frame":1,...} + data → ok
SET_ANIM {"index":0,"frame":2,...} + data → ok
…
ANIM 0 10                                 → anim event, playback starts
```

USB CDC on the ESP32-S3 is full-speed (~1 MB/s real-world), so a typical
20-frame clip (640 KB) uploads in about a second.

### `ANIM_CLEAR` (v0.5+)

```
ANIM_CLEAR 0
```

Stops playback if key 0 is animating and deletes
`/osd/keys/0/anim/*.rgb565`. Responds
`{"event":"ok","cmd":"ANIM_CLEAR","index":0,"removed":20}`.

### `SD_LS` (v0.6+)

```
SD_LS /osd/keys/0/anim
```

One `sd_entry` line per item, then a terminator:

```json
{"event":"sd_entry","name":"0001.rgb565","dir":false,"size":32768}
{"event":"sd_ls_done","path":"/osd/keys/0/anim","count":1}
```

`SD_LS` with no path lists the card root. Retries the SD mount if a card was
inserted after boot.

### `SD_RM` (v0.6+)

```
SD_RM /osd/keys/0/anim/0001.rgb565
```

Removes a file (or an empty directory). Responds
`{"event":"ok","cmd":"SD_RM","path":"..."}` or `rm_failed`.

### `GET_KEYS` response lines

```json
{"event":"key_state","index":0,"label":"MUTE","sublabel":"Toggle","hid":240}
```

(`hid` is Arduino `KEY_F13` etc.)

## Storage & media

On-board **microSD** holds offline icons and animation frames:

```
/osd/keys/0/icon.rgb565
/osd/keys/0/anim/0001.rgb565
/osd/profiles/streaming.json
```

Animations survive reboot — replay with `ANIM n fps` any time.

See `docs/product_architecture.md` for video limits on shared SPI.

## Animation rules (physics of a shared SPI bus)

- **One key animates at a time** (`ANIM n fps`); 1–30 fps
- Frames stream from SD: `/osd/keys/n/anim/0001.rgb565`, `0002` …
- All six keys **cannot** run video simultaneously — see
  `docs/product_architecture.md` for the bandwidth math

## Quick test (Chrome console via Web Serial)

1. Connect device with USB CDC enabled  
2. Open serial monitor or Web Serial  
3. Send `PING` → expect `pong`  
4. Press a key → expect `key` event JSON

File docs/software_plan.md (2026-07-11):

# Companion App — Project Plan

The desktop configurator for Open Screen Deck: a downloadable Windows/macOS
app to set up keys, push icons and animations, and manage the device — plus
a built-in simulator so all of it can be developed and demoed without
hardware.

**Repo home:** `app/` (web-first core, wrapped in Tauri for distribution)

---

## Architecture

One codebase, three run targets:

```
┌────────────────────────────────────────────────┐
│  UI (React + TypeScript)                       │
│  deck view · key inspector · media pipeline    │
├────────────────────────────────────────────────┤
│  Protocol layer (serial protocol v0.4+)        │
│  typed commands/events · RGB565 · framing      │
├────────────────────────────────────────────────┤
│  Transport interface                           │
│  ├─ SimulatorTransport  (virtual device)       │
│  ├─ WebSerialTransport  (browser dev)          │
│  └─ TauriSerialTransport (shipped app)         │
└────────────────────────────────────────────────┘
```

Rules that keep this sane:

1. **The protocol is the only contract.** The UI never talks to a device
   object directly — everything goes through protocol lines over a
   Transport. The simulator earns its keep by speaking the identical
   protocol; if it drifts from firmware, that is a bug.
2. **The simulator is a firmware twin, not a mock.** It implements the
   command set the way `firmware/main.cpp` does, including config
   persistence (localStorage standing in for NVS) and key-press events.
3. **Web-first, Tauri-wrapped.** Everything runs in a plain browser today
   (fast iteration, Web Serial for early hardware tests). Tauri packaging
   is a milestone, not a prerequisite.

---

## Feature list (full scope)

### Device setup
- Per-key label, sublabel, background color, HID keycode (F13–F24 or
  custom) with live preview
- Per-key static icons: drop any image → auto-resize → RGB565 → device
- Profiles: named sets of all six keys; export/import as JSON; later
  auto-switching hooks (active app detection — stretch)
- Device info panel: firmware version, SD card size/usage, connection state

### Media pipeline (the differentiator)
- Animations per key: drop a GIF or video → decoded in-app → downsampled
  to 128×128 at 5/10/15 fps → size estimate → streamed to the device SD
  card → loop playback via `ANIM`
- Frame budget guardrails (SD write speed and space) surfaced in UI
  before upload, not after failure
- Later: live streaming mode (host pushes frames continuously over USB
  for now-playing art, meters, timers)

### Development & debugging
- **Simulator**: pixel-accurate virtual deck; click keys to fire the same
  events hardware sends; shows which HID keystroke would fire; persists
  its "NVS" across reloads
- Protocol console: raw TX/RX lines, timestamped — doubles as the field
  debugging tool for user bug reports
- Fault injection (later): simulated disconnects, slow SD, full SD

### Distribution
- Tauri app for macOS (universal) and Windows x64; auto-update feed off
  GitHub Releases
- The same build deployed as a web app on the docs site (simulator-only
  mode) as a try-before-you-build demo

---

## Firmware alignment (v0.4 → v0.5)

The existing firmware + protocol already cover: `SET_KEY` with NVS
persistence (survives unplug — requirement met), `SET_IMAGE` full-frame
push, `ANIM` playback from SD, key events, `INFO`/`SD_INFO`.

v0.5 additions needed for the full app experience — to implement when
hardware is in hand:

| Gap | Addition |
|-----|---|
| No way to write SD files over USB | `SD_WRITE {name,len}` + chunked transfer with per-chunk ack + CRC |
| Image push is all-or-nothing 32 KB | chunked `SET_IMAGE` (4 KB chunks + ack) so slow hosts don't overrun |
| App can't read full config back | `GET_CONFIG` → one JSON blob (labels, colors, hid, icon/anim refs) |
| No protocol versioning | `INFO` gains `"proto":5`; app negotiates features |
| `GET_KEYS` omits `bg`/`fg` colors | include full key state in each `key_state` line |
| No key release events | emit `"action":"release"` so the app can show hold state |
| Icons lost on reboot (RAM only) | persist pushed icons to SD (`/osd/icons/keyN.raw`), reload at boot |

---

## Milestones

| # | Deliverable | Definition of done |
|---|---|---|
| **M0** | App shell + simulator | Virtual deck renders 6 live keys; click-to-press fires protocol events; config edits persist across reload. **Being built now.** |
| **M1** | Full key configuration UX | Labels, colors, HID picker, static icons, profiles import/export — all against the simulator |
| **M2** | Media pipeline | GIF/video → frames → simulated SD; playback in simulator; size guardrails |
| **M3** | Real device over Web Serial | Same UI drives hardware; bring-up tested against Rev B board; protocol console used for debugging |
| **M4** | Firmware v0.5 | Chunked transfers, GET_CONFIG, SD writes, icon persistence; app negotiates v4/v5 |
| **M5** | Tauri packaging | Signed .dmg + .msi, serial permissions, auto-update, CI release workflow |
| **M6** | Polish + docs | First-run experience, docs-site "web demo" deployment, user guide pages |

Sequencing notes:
- M0–M2 need zero hardware — that's the point of the simulator.
- M3 starts the day the Rev B boards arrive and work.
- M4 is the only firmware work; everything before it runs on v0.4.
- Tauri (M5) is deliberately late: packaging early buys nothing.

---

## Stack

| Piece | Choice | Why |
|---|---|-----|
| UI | React 18 + TypeScript + Vite | fast dev loop; huge ecosystem; team familiarity |
| Styling | hand-rolled CSS, product palette | no framework bloat; matches device aesthetic |
| Tests | Vitest | protocol codec + RGB565 conversions are unit-testable |
| Serial (dev) | Web Serial API | zero install; Chrome/Edge cover dev needs |
| Serial (ship) | tauri-plugin-serialplugin | native, cross-platform, no driver on modern OSes |
| Shell | Tauri v2 | ~5 MB installers vs Electron's ~100 MB |
| Video decode | HTMLVideoElement + canvas / WebCodecs | in-browser, no ffmpeg dependency for v1 |

---

## Risks

- **Web Serial is Chromium-only** — fine for dev; the shipped Tauri app
  does not depend on it.
- **SD write throughput** over CDC will limit animation length; guardrails
  in the UI + honest progress bars. Measure on real hardware in M3 and
  set the budget from data.
- **WebCodecs coverage** varies; canvas-sampling fallback is slower but
  universal.
- **Signing** (Apple notarization, Windows cert) costs money and setup
  time — schedule it inside M5, not at the end.

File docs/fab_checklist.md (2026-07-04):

# Fab Checklist — Open Screen Deck Carrier PCB

Use before ordering from JLCPCB / PCBWay.

## Generate outputs

```bash
chmod +x scripts/build_hardware.sh
./scripts/build_hardware.sh
```

## Pre-order (KiCad GUI)

1. Open `hardware/pcb/data_streamdeck.kicad_pro`
2. **Schematic** — run ERC; confirm ESP32 ↔ ScreenKey nets
3. **PCB** — finish routing from ESP32 module to global labels (generator places footprints + SPI trunk)
4. **DRC** — target zero errors (current generator may show courtyard/clearance warnings until routing complete)
5. **3D view** — USB-C aligns with enclosure rear slot; microSD reachable via bottom cutout
6. Assign **LCSC/JLC** parts in BOM tool if using SMT assembly

## Upload to fab

| File | Location |
|---|---|
| Gerbers | `hardware/pcb/gerbers/*.gbr` |
| Drill | `hardware/pcb/gerbers/*-NPTH.drl` and `*-PTH.drl` |
| BOM | `hardware/pcb/bom.csv` |

**Suggested spec:** 2-layer, 1.6 mm, FR4, **ENIG**, matte black mask, 1 oz copper.

## Assembly order

1. Solder **U1** (ESP32-S3 module) — reflow or hot plate  
2. Solder **J7** USB-C — verify orientation (rear-facing)  
3. Solder **J1–J6** — pin 1 toward KEY net (see schematic title block)  
4. Solder **J8** microSD  
5. Passives **0402/0805**  
6. Mount modules per `docs/assembly.md` (M2×5 into factory standoffs; corner
   spacers at H1–H4 for the M2×25 case screws)  
7. Plug **6× ScreenKey** cables (in-box 200 mm; fold slack flat)  
8. Flash firmware (`firmware/main.cpp`) — USB-C on board, not dev kit  

## Bring-up tests

- [ ] USB-C powers board; 3.3 V at module connectors  
- [ ] All six displays init (SPI)  
- [ ] All six keys debounce  
- [ ] HID F13–F18 on Mac/Win/Linux  
- [ ] CDC serial: `PING` → `pong`  
- [ ] microSD mounts (firmware v0.4+)  

## Enclosure fit

- [ ] M2×25 corner screws pass H1–H4 → module nuts → top-plate inserts  
- [ ] USB-C flush with rear slot  
- [ ] microSD access slot (optional cutout)  
- [ ] Top shell closes; keys travel OK

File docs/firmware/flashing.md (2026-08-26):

# Flash the Firmware

The carrier PCB does not come with firmware pre-loaded. Flash once after
assembly over the on-board USB-C port.

GitHub Releases include `firmware-<version>.bin` plus bootloader and
partition images — same files the companion bundles. The companion is
usually easier: Settings → Firmware.

!!! tip "Companion app"
    After the first flash, [the app](../app/index.md) can put the board in
    bootloader mode and write the bundled firmware (Settings → Firmware).
    Arduino / `esptool` below are for a blank board, a machine without
    the app, or if you're changing the sketch.

## Requirements

- **Arduino IDE** (or `arduino-cli`) with the [ESP32 board package](https://docs.espressif.com/projects/arduino-esp32/en/latest/)
- Libraries: **Adafruit ST7735 and ST7789**, **Adafruit GFX**, **Adafruit NeoPixel**
- USB-C data cable

## Board settings

In Arduino IDE, select:

| Setting | Value |
|---|---|
| Board | **ESP32S3 Dev Module** |
| USB CDC On Boot | **Enabled** |
| USB Mode | **USB-OTG (TinyUSB)** |
| PSRAM | **OPI PSRAM** (WROOM-1-N16R8) |
| Flash Size | **16MB** (partition `app3M_fat9M_16MB`) |

## Upload

1. Open `firmware/firmware.ino` in the Arduino IDE (the sketch pulls in
   the rest of the `firmware/` modules automatically) — or skip the IDE
   entirely with `./scripts/build_firmware.sh --flash`.
2. Hold **BOOT**, tap **RESET**, release **BOOT** — the board enters download mode.
3. Upload the sketch.

## Verify

After upload, the deck enumerates as:

- A **USB keyboard** — keys send F13–F24 by default (F13–F18 on page 1)
- A **CDC serial port** — for runtime config over the [Serial Protocol](protocol.md)

Key labels, colors, and HID codes are configurable at runtime over the
serial protocol — no reflash needed. On a Rev E board, `INFO` also reports
IMU / ALS / haptic presence, lux, and LED count. Settings → Deck hardware
in the companion drives auto-dim, glow, and a `SELFTEST`.

!!! tip "First test"
    Open a serial monitor at 115200 baud and send `PING`. You should receive
    `{"event":"pong"}`. Press a key and watch for `{"event":"key",...}` JSON.

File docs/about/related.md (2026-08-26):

# Related Projects

Other DIY macro pads and deck-like builds worth knowing about.

## FreeTouchDeck

**[github.com/DustinWatts/FreeTouchDeck](https://github.com/DustinWatts/FreeTouchDeck)**

ESP32 macro deck with web config and printable cases. Uses a single
touchscreen rather than per-key LCD modules.

## open-deck

**[github.com/joshr120/open-deck](https://github.com/joshr120/open-deck)**

Open macro keyboard with custom PCB and images per key. One TFT behind
mechanical keys on an ESP8266.

## MacroPad

**[github.com/yuvasaro/MacroPad](https://github.com/yuvasaro/MacroPad)**

Per-key 64×64 OLED macro pad with custom PCB and desktop profiles. Nine
keys, not ScreenKey modules.

## How this project differs

| | Open Screen Deck | Projects above |
|--|---|---|
| Display | 6× 128×128 IPS (one per key) | Single touchscreen, one TFT, or small OLED |
| Keys | Waveshare ScreenKey (LCD + switch module) | Separate switch + display, or touch-only |
| PCB / case | 59.5 × 108.5 mm carrier + OpenSCAD enclosure | Varies |
| Host link | USB HID + CDC serial | Varies (web UI, BLE, etc.) |

This repo is a 2×3 ScreenKey deck: carrier, case, and firmware in one
place. Waveshare's own apps target a single module and aren't used here.

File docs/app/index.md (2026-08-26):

# Companion App

Optional desktop tool for drawing key faces, assigning host actions, and
flashing firmware. Without it the deck is still a USB keyboard (F13–F24
by default, plus whatever you last saved on the device).

Deck view

Binaries are on [GitHub Releases](https://github.com/vcazan/open-screen-deck/releases).
To run from source: [app development](development.md) (`app/`, Tauri 2).

## How it works

```
key press ──USB CDC──▶ companion (Tauri/Rust) ──▶ action engine ──▶ macOS/Windows
key faces ◀──SET_KEY / SET_FACE / SET_IMAGE── state engine + plugins ◀── OS
```

On connect the companion sends `MODE COMPANION`; the firmware stops typing
F13–F24 itself and just reports key events. A `PING` every 2 s is the
heartbeat — if the app quits or the cable is pulled, the firmware falls
back to plain HID within 6 s.

## Configuring keys

Click any key and the inspector opens: label, color, icon, animation, and
what the key does.

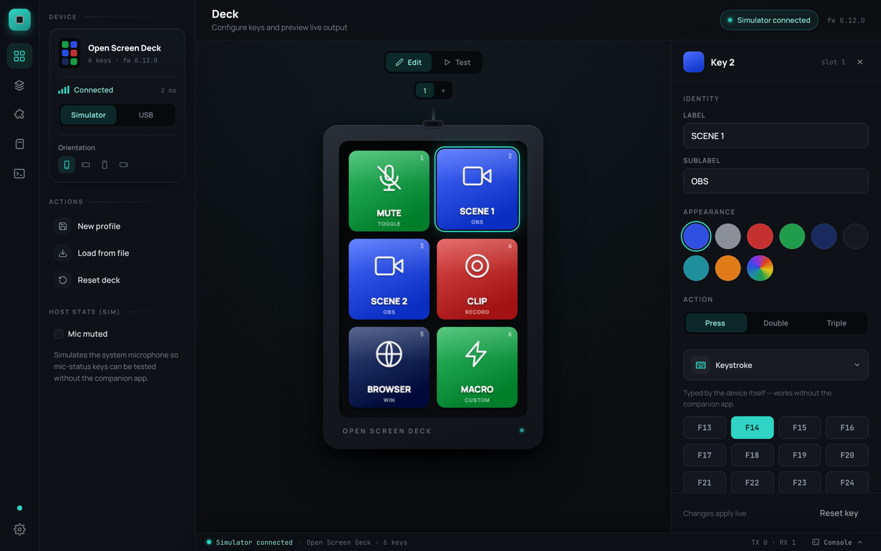
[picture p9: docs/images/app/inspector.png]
Key inspector


Choosing an action is a gallery of cards grouped by where they run
(device vs host). Type to filter.

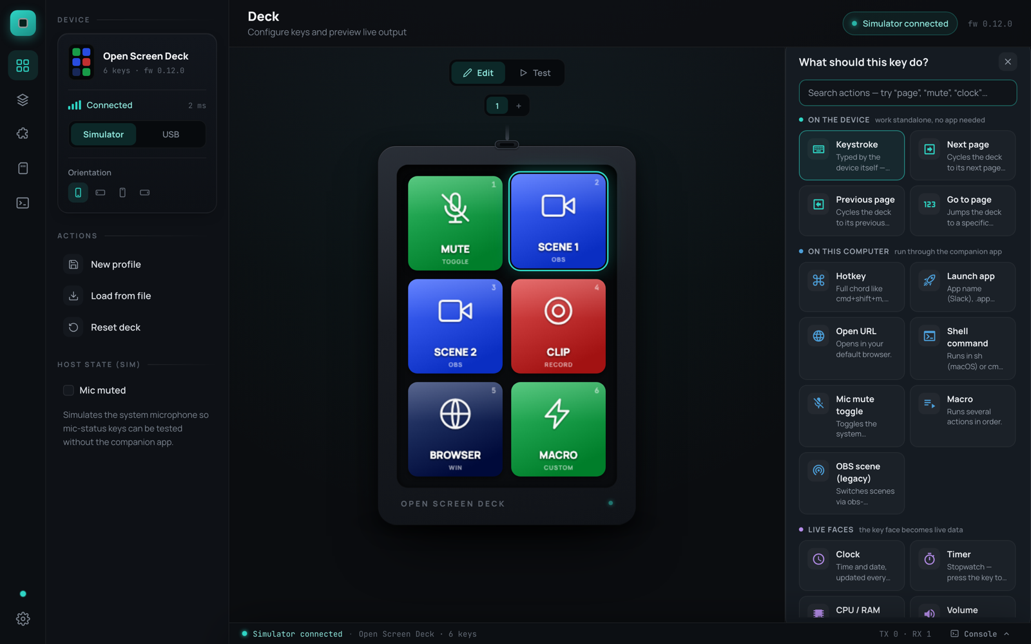
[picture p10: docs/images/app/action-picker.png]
Action picker


| Action | Runs on | Notes |
|---|---|---|
| Keystroke (F13–F24) | device | works without the companion |
| Next / Previous / Go to page | device | firmware-owned, works standalone |
| Hotkey (`cmd+shift+m`) | host | needs macOS Accessibility permission |
| Launch app | host | picking an app also puts its logo on the key |
| Open URL | host | default browser |
| Shell command | host | `sh -lc` / `cmd /C` |
| Mic mute toggle | host | live two-state face (configurable colors/labels) |
| Live tiles | host | clock, timer, CPU/RAM, volume, now playing, OBS scene |
| Macro | host | steps with per-step delay |
| Plugin actions | host | from [installed plugins](../plugins/index.md) |

### Multi-tap

Every key can hold **single, double, and triple press** actions. The
firmware is smart about latency: keys with only a single action fire
instantly; keys with multi-tap bindings use a short tap window. Works on
the device and on-screen.

### Pages

Decks start with one page and grow to **8 pages × 6 keys = 48 slots**.
The page count lives on the device (NVS-persisted) and inside each
profile, so applying a 3-page profile resizes the deck. Page-switch keys
ride reserved HID codes, so they work standalone.

## Key faces & media

- **Images** — drop a PNG/JPG on a key; crop interactively to 128×128.
  Transparent pixels adopt the key's background color and follow recolors.
- **Icons** — a searchable library of ~7,400 Material Design Icons.
- **Animations** — drop a GIF or video; frames upload to the deck's
  microSD and play on-device, even standalone.
- **Live tiles and plugin faces** stream as draw-only frames — no SD wear.

Plugins draw fully custom faces (tickers, clocks, progress rings) and own
their keys' look:

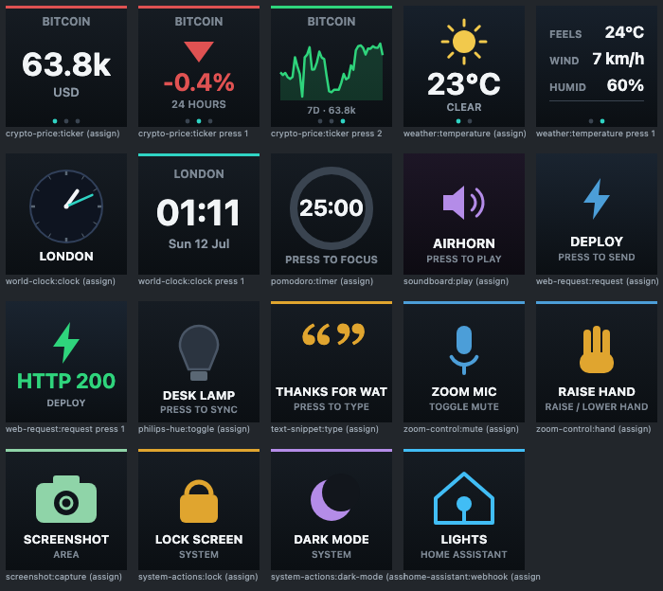
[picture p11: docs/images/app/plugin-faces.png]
Plugin faces


## Profiles

A profile is a saved deck layout — configs, actions, page count, and
media. The **active** profile auto-saves as you edit. Profiles export as
self-contained `.osdprofile.json` files (**Share** on any card); community
layouts live in the repo's
[`profiles/`](https://github.com/vcazan/open-screen-deck/tree/main/profiles)
folder. Starter templates (including a plugin showcase) are in the app:

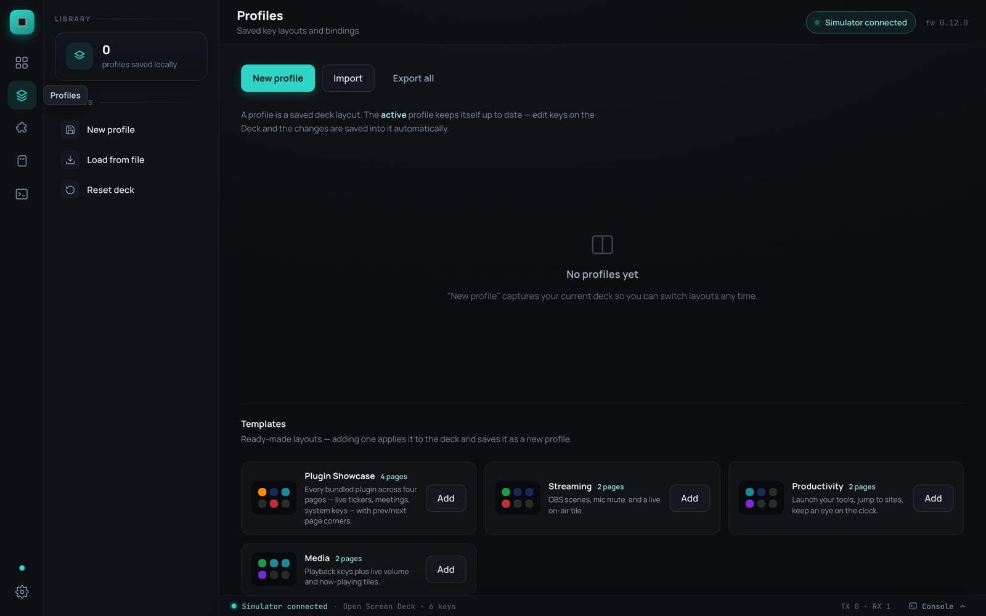
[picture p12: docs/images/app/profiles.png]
Profiles view


A profile can load when a given app comes to the front (e.g. OBS).

## Editing niceties

- **Drag & drop** — drag one key onto another to swap them
- **Copy/paste** — ++cmd+c++ / ++cmd+v++ on a selected key
- **Undo/redo** — ++cmd+z++ / ++shift+cmd+z++, up to 50 steps
- **Test mode** — click keys in the UI to fire the real actions

## Plugins

**Plugins** lists what's in `plugins/registry.json`. Install from there,
open a plugin for its settings and changelog, and you'll be asked before
an update applies.

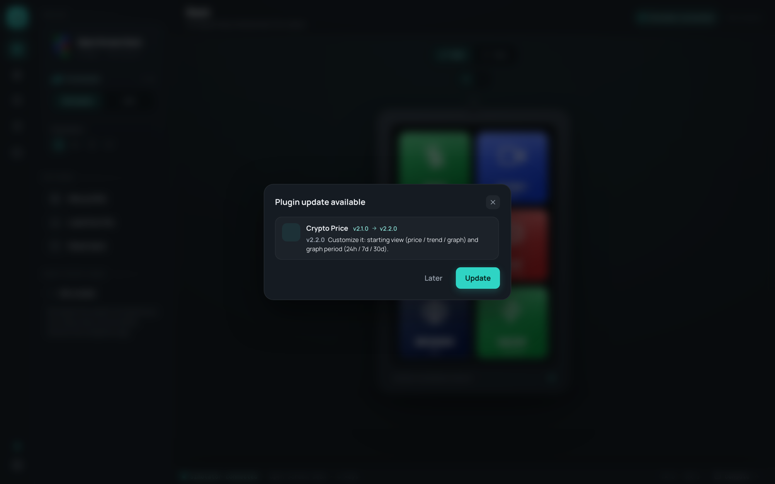
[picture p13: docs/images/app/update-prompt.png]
Update prompt


To write one, [developer center](../plugins/develop.md) — **Plugins →
Developer → Create** drops a working folder on disk.

## Firmware updates

Settings → Firmware compares the deck to the binary bundled with the app
and can reboot into the ROM bootloader, flash over USB (~30 s), and come
back. Recovery un-sticks a board left in download mode. You can still
flash from Arduino; this is just the same image from the app.

## Deck hardware (Rev E)

When a connected deck reports protocol 14+, Settings grows a **Deck
hardware** card: IMU / ALS / haptic presence, lux, auto-dim, backlight,
glow colour for the eight SK6812s, click-beep, and a `SELFTEST` that walks
the panels and sensors. Older boards hide the card.

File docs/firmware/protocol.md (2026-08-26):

# Serial Protocol (v14)

USB **CDC serial** at **115200 baud**, newline-terminated lines.  
No custom kernel driver — companion app opens the CDC port (Web Serial or Tauri).

Firmware **0.14.x** speaks protocol **14** (Rev E sensors, LEDs, haptics).
Older decks still speak the v0.12 command set below; unknown commands are
ignored.

## Pages (v0.10+, dynamic since v0.11)

A deck has **1–8 pages of 6 keys**, resized at runtime with `SET_PAGES`
(persisted in NVS; profiles carry their own page count). A slot index is
`page*6 + position`; every indexed command (`SET_KEY`, `SET_IMAGE`,
`SET_ANIM`, `ANIM`, `DRAW`, …) takes a slot (0–47). The six screens show
the current page; commands addressing slots on other pages update config
and SD media without drawing. Shrinking the page list resets the dropped
slots to defaults.

Reserved HID codes make keys switch pages **on-device** (standalone and
under the companion alike):

| HID code | Behavior |
|---|---|
| `230` | previous page (wraps) |
| `231` | next page (wraps) |
| `232`–`239` | go to page 1–8 (no-op past the current page count) |

## Device → Host (unsolicited)

Boot:

```json
{"event":"info","name":"Open Screen Deck","fw":"0.14.5","proto":14,"keys":6,"pages":2,"page":0,"orient":0,"mode":"hid","sd":true,"psram":8388608,"leds":8,"imu":true,"als":true,"haptic":true,"lux":120.0,"autodim":true,"bright":255,"clickbeep":false}
```

Key press / release (`index` is the global slot; `taps` from v0.12):

```json
{"event":"key","index":0,"action":"press","taps":1}
{"event":"key","index":0,"action":"release"}
```

## Multi-tap (v0.12+)

Each key has three HID bindings: `hid` (single), `h2` (double), `h3`
(triple) — set via `SET_KEY`, 0 = unbound. **Latency rule:** a key with no
`h2`/`h3` resolves on the first press instantly. A key with multi-tap
bindings waits up to **300 ms** between taps, and resolves early the moment
the highest bound level is reached. Press events report the resolved
`taps` count.

HID codes **224–229** are silent sentinels: the firmware never types them.
The companion sets `h2`/`h3` to 229 (`TAP_ARM`) when a double/triple slot
holds a host-only action (launch, hotkey, …) so the firmware still counts
taps for it. Page codes (230–239) work at any tap level, standalone.

Page changed (SET_PAGE or an on-device page key):

```json
{"event":"page","page":1}
```

## Host → Device

| Command | Response |
|---|---|
| `PING` | `{"event":"pong"}` (doubles as companion heartbeat) |
| `MODE COMPANION` | suppress on-device HID; companion routes key events (v0.7+) |
| `MODE HID` | restore on-device HID typing (v0.7+) |
| `INFO` | info object (includes `sd` + `psram`) |
| `GET_KEYS` | one `key_state` line per key |
| `DRAW 0` | redraw key 0 |
| `DRAW_ALL` | stop animation, redraw all keys |
| `SET_KEY {...}` | update label/sublabel/hid/h2/h3/bg/ov; persists to NVS. `ov:1` draws text over SD media at render time (v0.8+); `h2`/`h3` bind double/triple press (v0.12+) |
| `SET_IMAGE {...}` + raw bytes | push 128×128 RGB565 frame to a key (persists to SD) |
| `SET_FACE {...}` + raw bytes | draw-only frame — live tiles; never touches SD (v0.10+) |
| `SET_ANIM {...}` + raw bytes | write one animation frame to SD (v0.5+) |
| `ANIM 0 10` | play SD animation on key 0 at 10 fps |
| `ANIM STOP` | stop animation, restore icon |
| `ANIM_CLEAR 0` | delete all animation frames for key 0 (v0.5+) |
| `SD_INFO` | SD card size/usage |
| `SET_PAGE n` | show page n on the six screens; persists to NVS (v0.10+) |
| `SET_PAGES 1..8` | resize the page list; emits `{"event":"pages","pages":n}` (v0.11+) |
| `SET_ORIENT 0..3` | deck orientation: 0 portrait, 1 landscape CW, 2 flipped, 3 landscape CCW (v0.9+). Rotates all displays, remaps key positions row-major, persists to NVS |
| `SET_LED {"index":0,"r":255,"g":64,"b":0}` | host-own one logical LED (0–5 keys, 6 link, 7 SD; `-1` = all). Until `LED_CLEAR` (v14) |
| `LED_CLEAR` | drop host LED overrides; reactive status resumes (v14) |
| `AUTODIM 1\|0` | VEML7700 drives backlight PWM (v14) |
| `SET_BRIGHT 0..255` | manual backlight; implies auto-dim off (v14) |
| `CLICK_BEEP 1\|0` | piezo alongside haptic click (v14) |
| `HAPTIC` | play a click on the DRV2605L / piezo (v14) |
| `BEEP [freq] [ms]` | piezo tone (v14) |
| `SELFTEST` | walk panels, LEDs, haptic, piezo; reports sensor presence (v14) |
| `SD_LS /osd/keys` | list a directory (v0.6+) |
| `SD_RM /osd/keys/0/icon.rgb565` | delete a file or empty dir (v0.6+) |

### Companion mode (v0.7+)

While the desktop companion app is connected it sends `MODE COMPANION`
followed by `PING` every 2 s. In this mode the firmware **does not type
HID keys** — it only emits `key` events, and the companion executes the
configured action (launch app, hotkey, mic mute, …). If no heartbeat
arrives for 6 s (app quit, cable pulled), the firmware falls back to
plain HID F13–F24 automatically. The deck always works standalone.

### `SET_KEY`

```json
SET_KEY {"index":0,"label":"MUTE","sublabel":"Mic","hid":104,"bg":19049}
```

`hid` = Arduino HID code (KEY_F13 = 240 on the ESP32 core; use value from `GET_KEYS`).
`bg` = RGB565 as decimal. Persisted to NVS — survives reboot.

String fields are optional: omit `label`/`sublabel` to keep the current value,
send an explicit empty string (`"label":""`) to clear it.

### `SET_IMAGE`

```json
SET_IMAGE {"index":0,"len":32768}
```

Device replies `{"event":"send_data"}`; host then sends exactly 32 768 raw
RGB565 bytes (big-endian per Adafruit GFX). Frame is drawn immediately and
saved to SD as `/osd/keys/0/icon.rgb565` when a card is mounted.

**Transparency (v0.9.1+):** icon pixels with the sentinel value `0x0821`
(bytes `08 21`) are replaced by the key's current `bg` color at draw time —
recoloring a key never requires re-uploading its image. The companion app
writes this sentinel for transparent regions of logos and PNGs.

### `SET_FACE` (v0.10+)

```json
SET_FACE {"index":0,"len":32768}
```

Identical handshake to `SET_IMAGE`, but the frame is **only drawn** — nothing
is written to SD and the stored icon is untouched. The companion streams live
tiles (clock, timer, CPU meter, volume, now playing, OBS scene) through this
at 0.3–2 fps per tile. Slots on a hidden page ack without drawing.

### `SET_ANIM` (v0.5+)

```json
SET_ANIM {"index":0,"frame":1,"len":32768}
```

Same handshake as `SET_IMAGE`: device replies `{"event":"send_data"}`, host
sends 32 768 raw RGB565 bytes. The frame is written to
`/osd/keys/0/anim/0001.rgb565` (frame numbers are **1-based**, max 999).
Requires a mounted SD card — errors with `bad_anim_header` otherwise.

Typical upload sequence from the companion app:

```
ANIM_CLEAR 0                              → ok
SET_ANIM {"index":0,"frame":1,...} + data → ok
SET_ANIM {"index":0,"frame":2,...} + data → ok
…
ANIM 0 10                                 → anim event, playback starts
```

USB CDC on the ESP32-S3 is full-speed (~1 MB/s real-world), so a typical
20-frame clip (640 KB) uploads in about a second.

### `ANIM_CLEAR` (v0.5+)

```
ANIM_CLEAR 0
```

Stops playback if key 0 is animating and deletes
`/osd/keys/0/anim/*.rgb565`. Responds
`{"event":"ok","cmd":"ANIM_CLEAR","index":0,"removed":20}`.

### `SD_LS` (v0.6+)

```
SD_LS /osd/keys/0/anim
```

One `sd_entry` line per item, then a terminator:

```json
{"event":"sd_entry","name":"0001.rgb565","dir":false,"size":32768}
{"event":"sd_ls_done","path":"/osd/keys/0/anim","count":1}
```

`SD_LS` with no path lists the card root. Retries the SD mount if a card was
inserted after boot.

### `SD_RM` (v0.6+)

```
SD_RM /osd/keys/0/anim/0001.rgb565
```

Removes a file (or an empty directory). Responds
`{"event":"ok","cmd":"SD_RM","path":"..."}` or `rm_failed`.

### `GET_KEYS` response lines

One line per global slot (6 × current page count):

```json
{"event":"key_state","index":0,"page":0,"label":"MUTE","sublabel":"Toggle","hid":240,"bg":19049,"ov":0}
```

(`hid` is Arduino `KEY_F13` etc.)

## Storage & media

On-board **microSD** holds offline icons and animation frames:

```
/osd/keys/0/icon.rgb565
/osd/keys/0/anim/0001.rgb565
/osd/profiles/streaming.json
```

Animations survive reboot — replay with `ANIM n fps` any time.

See [Architecture](../hardware/architecture.md) for video limits on dual SPI.

## Animation rules

- **One key animates at a time** (`ANIM n fps`); 1–30 fps
- Frames stream from SD: `/osd/keys/n/anim/0001.rgb565`, `0002` …
- All six keys **cannot** run video simultaneously — see
  [Architecture](../hardware/architecture.md) for the bandwidth math

## Rev E hardware (protocol 14+)

`INFO` includes `leds`, `imu`, `als`, `haptic`, `lux`, `autodim`, `bright`,
and `clickbeep`. The companion's Settings → Deck hardware card uses these
commands. Logical LED index 0–5 follows keys J1–J6; 6 is the rear USB-link
indicator; 7 is SD status. Physical SK6812 wiring order is in
`hardware/pinout.py` (`LED_CHAIN_REFS`).

## Quick test (Chrome console via Web Serial)

1. Connect device with USB CDC enabled  
2. Open serial monitor or Web Serial  
3. Send `PING` → expect `pong`  
4. Press a key → expect `key` event JSON

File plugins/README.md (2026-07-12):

# Companion Plugins

Plugins add new **action types** to the companion app. Each plugin is a
folder with a `manifest.json` and an ES module:

```
plugins/
└── my-plugin/
    ├── manifest.json   {"id":"my-plugin","name":"My Plugin","version":"1.0.0","main":"main.js","icon":"icon.svg"}
    ├── icon.svg        shown in the store, installed list, and action editor
    └── main.js         export function activate(api) { … }
```

The icon should say what the plugin *does* at a glance — a bitcoin glyph
for a ticker, a bulb for lights. Any square SVG works; the bundled
plugins use [Material Design Icons](https://pictogrammers.com/library/mdi/)
paths on a rounded dark tile (see any `icon.svg` here for the template).

## Install — the store

**Settings → Plugins** in the companion app browses this repo's
[`registry.json`](registry.json) and installs plugins with one click.
Updates show up automatically when a registry entry's version is newer
than what's installed.

Manual install also works: copy a plugin folder into the plugin directory
(Settings → Plugins → Developer shows the path, with an *Open plugin
folder* button) and hit **Reload plugins**:

| OS | Path |
|----|---|
| macOS | `~/Library/Application Support/com.openscreendeck.companion/plugins/` |
| Windows | `%APPDATA%\com.openscreendeck.companion\plugins\` |

Installed actions appear in the key inspector's action picker under
**Plugins**.

## Develop

Settings → Plugins → **Developer → Create** scaffolds a working plugin
(manifest + a live Hello action) and opens its folder. Edit `main.js`,
hit **Reload plugins**, press your key — that's the whole loop.

## Publish

1. PR your plugin folder into `plugins/`
2. Add an entry to [`registry.json`](registry.json) (id, name, version,
   description, `base` raw URL, `files` list — include `icon.svg` in
   `files` and set `"icon": "icon.svg"` so the store shows your icon)
3. Once merged, every user's store lists it on refresh

### Shipping updates

Bump `version` in both `manifest.json` and the registry entry, and add a
line to the registry entry's `changelog`:

```json
"changelog": {
  "2.1.0": "New store icon so you can spot the plugin at a glance.",
  "2.0.0": "Fully drawn ticker faces: press to cycle Price, Trend, Graph."
}
```

Users with an older version get an in-app prompt showing your release
notes — nothing installs until they say yes. Write the note for the
person deciding whether to update: what changed, in one line per version.

Community registries are supported too — the registry URL is configurable
in the Developer section, so you can host your own index anywhere.

## API

```js
export function activate(api) {
  api.registerAction({
    type: 'my-action',            // unique within the plugin
    label: 'My action',           // shown in the picker
    hint: 'One-line description',
    fields: [                     // settings + customization UI, stored per key
      { key: 'url', label: 'URL', placeholder: 'https://…' },        // text (default)
      { key: 'view', label: 'Starting view', type: 'select',          // dropdown
        default: 'price',
        options: [
          { value: 'price', label: 'Price' },
          { value: 'graph', label: 'Graph' },
        ] },
      { key: 'accent', label: 'Accent color', type: 'color',          // swatch, "#rrggbb"
        default: '#2fd4c4' },
      { key: 'loud', label: 'Play loud', type: 'toggle', default: '' }, // "yes" / ""
    ],
    // Runs when the action is assigned to a key (and when its settings
    // change). Plugin keys OWN their look — paint a branded face here.
    async onAssign(settings, ctx) {
      const canvas = drawMyFace(settings);       // any 128×128 canvas
      await ctx.setKeyImage(canvas);             // persistent (survives reboot,
    },                                           //   shows standalone)
    async execute(settings, ctx) {
      ctx.log('pressed!');                       // protocol console
      await ctx.paintFace(drawLiveFace());       // stream a live frame
                                                 //   (fast, no SD wear)
      const res = await ctx.fetch(settings.url); // HTTP via Rust — reaches
                                                 //   plain-http/LAN targets
      await ctx.shell('say hello');              // run a shell command
      await ctx.hotkey('cmd+shift+4');           // press a hotkey chord
      ctx.setKeyFace(ctx.slot, {                 // simple text face (legacy)
        label: 'HI', sublabel: 'from plugin', bg: 0x1c73,
      });
    },
  });

  // Plugin-level settings (connections, API keys) — global, not per-key.
  // They appear on the plugin's detail page; `apply` runs with stored
  // values on load and whenever the user saves.
  api.registerSettings(
    [{ key: 'host', label: 'Server address', placeholder: '127.0.0.1' }],
    (values) => reconnect(values.host),
  );

  // Live plugins (clocks, tickers, audio) must clean up on hot reload:
  api.onDispose(() => clearInterval(myTimer));
}
```

OBS plugins get `ctx.obs(requestType, requestData?)` — a bridge to the
app's shared obs-websocket v5 connection (see `obs-control`, which also
manages that connection through its settings).

`ctx.slot` is the global key slot (page × 6 + position) that fired.
A plugin can call `registerAction` several times to contribute a family
of actions (see `zoom-control` and `system-actions`).

### Custom faces

Plugins draw their keys with regular canvas 2D, 128×128:

- **`ctx.setKeyImage(canvas)`** — persists the face to the device
  (`SET_IMAGE`). Use it in `onAssign` for your branded resting face; it
  survives reboots and shows even without the app running. When the key's
  action is later changed away from your plugin, the app removes it.
- **`ctx.paintFace(canvas)`** — streams a draw-only frame (`SET_FACE`).
  Use it for live data: prices, clocks, progress rings, status feedback.
  Never touches flash/SD, so it's safe at a few fps.
- Transparent pixels in either take on the key's background color.

While a plugin action is assigned, the inspector's appearance / icon /
animation editors step aside — the plugin owns the face. Press-cycled
views are a nice pattern: keep a per-slot view index and redraw on
`execute` (see `crypto-price` — price → trend → graph).

### Customization fields

Because your plugin owns the key's look, expose the choices users would
reach for: starting view, colors, units, capture modes. Declare them as
typed `fields` (`select` / `color` / `toggle` — see the API example) and
they render as native controls in the key inspector and on your plugin's
detail page. `onAssign` re-runs whenever settings change, so repaint from
`settings` and the face follows the user's choices live. Values are
always strings; `default` prefills new keys.

> **Trust model:** plugins run inside the app's webview with the same
> capabilities as the app itself — including shell access. Install only
> code you trust.

## Bundled plugins

| Plugin | Face | Press |
|---|---|---|
| [`obs-control/`](obs-control/) | OBS ring; scene keys track the live program scene | switch scene / toggle stream / record |
| [`crypto-price/`](crypto-price/) | drawn ticker: price / 24h trend / 7-day graph | cycles the three views |
| [`weather/`](weather/) | condition glyphs (sun/cloud/rain/snow/storm) + temp | flips Now ↔ Details |
| [`world-clock/`](world-clock/) | live analog dial or digital + date | flips analog ↔ digital |
| [`pomodoro/`](pomodoro/) | progress ring, teal focus → red break | start / cancel |
| [`soundboard/`](soundboard/) | speaker brand, animated equalizer while playing | play / stop |
| [`web-request/`](web-request/) | bolt brand → SENDING… → HTTP status (green/red) | fires the request |
| [`philips-hue/`](philips-hue/) | a bulb that glows when the light is on | toggles light/room |
| [`text-snippet/`](text-snippet/) | quote face with a snippet preview | types the text |
| [`zoom-control/`](zoom-control/) | mic / camera / raised-hand glyphs | Zoom global shortcuts |
| [`screenshot/`](screenshot/) | camera face, shutter flash on capture | takes the shot |
| [`system-actions/`](system-actions/) | lock / sleep / trash / moon glyphs | runs the action |
| [`home-assistant/`](home-assistant/) | HA house glyph, flashes with the result | fires the webhook |

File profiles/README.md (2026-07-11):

# Profile Gallery

Community-shared deck layouts. Every `.osdprofile.json` here can be
imported straight into the companion app: **Profiles → Import**.

Profiles are self-contained — key configs, host actions, and (optionally)
key images/animations travel in one file. Export your own with the
**Share** button on any profile card.

## Contribute

1. Design your deck, then **Profiles → Share** to export the file
2. Rename it something descriptive (`obs-podcast-setup.osdprofile.json`)
3. Open a PR adding it here with a one-line description below

| Profile | Author | Description |
|---|---|---|
| _your profile here_ | | |

> Keep exported files under ~5 MB (drop unused animations before sharing).
> The three built-in starter profiles (Streaming, Productivity, Media) ship
> inside the app itself.

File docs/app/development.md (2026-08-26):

# App Development

The companion is a Tauri 2 app: Rust backend (serial, actions, OS state,
flashing, plugin services), React front end (deck editor, simulator).
Source lives in [`app/`](https://github.com/vcazan/open-screen-deck/tree/main/app).

## Run it

```bash
cd app
npm install
npm run dev          # browser build — full simulator, Web Serial
npx tauri dev        # desktop shell against the dev server
npx tauri build      # release bundles (.app / .dmg / .msi)
```

The browser build runs the complete UI against an in-browser simulated
deck — most development never needs hardware. Native-only features
(hotkey synthesis, mic control, plugin execution) dry-run to the console.

## Tests

```bash
cd app
npm test             # unit (vitest)
npm run test:e2e     # UI + protocol against the simulator (Playwright)
```

## Architecture notes

- **Protocol** — one JSON-over-CDC serial protocol for everything
  (`SET_KEY`, `SET_IMAGE`, `SET_FACE`, `SET_ANIM`, pages, mode/heartbeat).
  Reference: [Serial protocol](../firmware/protocol.md).
- **Simulator mirror** — in USB mode a local simulated deck mirrors every
  command sent to hardware, so the UI always reflects device state.
- **Actions** — host-side actions execute in Rust (launch, hotkey via
  `enigo`, shell, mic via CoreAudio/WASAPI); device-side actions (HID
  keystrokes, page switching) run in firmware.
- **Plugins** — ES modules evaluated in the webview with a narrow API;
  installs/HTTP proxied through Rust. See the
  [developer center](../plugins/develop.md).

## Permissions (macOS)

- **Hotkey synthesis** requires Accessibility approval (System Settings →
  Privacy & Security → Accessibility). Launch/URL/shell/mic actions do not.
- The **screenshot plugin** needs Screen Recording permission.
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

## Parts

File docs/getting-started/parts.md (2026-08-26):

# Parts List

What to buy and print for one deck. Same data as
[`hardware/bom_assembly.csv`](https://github.com/vcazan/open-screen-deck/blob/main/hardware/bom_assembly.csv).
Order the six modules first; print and fab while they ship.

## Bill of materials

| Item | Qty | Exact spec | Where to buy | Est. cost (USD) | Notes |
|---|-----|---|---|---|---|
| ScreenKey module | 6 | Waveshare 0.85inch ScreenKey Module B (SKU 34168) | [waveshare.com](https://www.waveshare.com/0.85inch-screenkey.htm?sku=34168) | ~$66 ($11 ea) | Includes the cable and brass standoffs. Buy Module B (black cap + switch + PCB) |
| Carrier PCB | 1 | **59.5 × 108.5 mm** Rev E 2-layer; files in `hardware/pcb/gerbers` | [JLCPCB](https://jlcpcb.com) / PCBWay | ~$15 for 5 boards | Upload `data_streamdeck_gerbers.zip`. SMT assembly recommended (IMU, ALS, LEDs). Parts in `hardware/pcb/bom.csv` |
| Printed: bottom tray | 1 | `hardware/enclosure/stl/deck_bottom_v14.stl` | Your 3D printer | ~$1 filament | PETG or PLA+; flat on bed; no supports. LED wall windows + SD + USB + Qwiic |
| Printed: top shell | 1 | `hardware/enclosure/stl/deck_top_v14.stl` | Your 3D printer | ~$1 filament | Face-down; no supports. ALS light-pipe hole in the face plate |
| Printed: corner spacers | 4 | `hardware/enclosure/stl/corner_spacers_x4_v14.stl` | Your 3D printer | pennies | 100% infill; replaces the factory standoff at the 4 deck corners |
| Printed: desk stand | 1 | `hardware/enclosure/stl/deck_stand_v14.stl` | Your 3D printer | ~$1 filament | Optional 25° stand |
| LRA coin motor | 1 | 8 mm LRA (e.g. Vybronics VG0832013D) | Digi-Key / LCSC | ~$2 | Optional — plugs into J10 for haptic click. Piezo on the PCB still beeps without it |
| Heat-set insert M2 | 4 | Ruthex RX-M2x4 brass (3.2 mm install hole) | Amazon "ruthex M2" | ~$8 per 50-pack | Goes into the top shell face plate |
| Screw M2×25 countersunk | 4 | M2 × 25 mm flat head countersunk DIN 965 (Phillips) or ISO 14581 (Torx) A2 | Amazon / AliExpress "M2×25 DIN 965" | ~$6 assorted box | The 4 case screws. Heads sink into the foot recesses and are hidden by the rubber feet |
| Screw M2×5 | 12 | M2 × 5 mm hex socket cap ISO 4762 / DIN 912 A2 | Same assorted box as above | included | Fixes modules to the carrier from below |
| Rubber feet | 8 | 10 mm dia × 2 mm self-adhesive | Amazon | ~$5 per sheet | 4 on the deck + 4 on the stand |
| microSD card | 1 | 8–32 GB; FAT32 | Anywhere | ~$5 | Optional — on-device icons and animations |
| USB-C cable | 1 | USB 2.0 data cable | You own one | — | Deck to computer |

!!! info "Estimated total"
    About **$100 in parts** — $66 of which is the six key modules. PCB fab runs
    ~$15 for five boards; Rev E sensors and glow add about $4–6 on the SMT
    line. Fasteners and printed parts add the rest. You likely already own a
    USB-C cable.

## What to order first

- [ ] **6× Waveshare 34168** — longest lead time; order these first from
      [Waveshare](https://www.waveshare.com/0.85inch-screenkey.htm?sku=34168)
- [ ] **Carrier PCB** — upload `hardware/pcb/data_streamdeck_gerbers.zip` to
      [JLCPCB](https://jlcpcb.com) (~$15 for five boards). Prefer SMT
      assembly on Rev E (IMU, ALS, eight SK6812s, haptic driver)
- [ ] **M2 fasteners** — one assorted box covers M2×5 module screws and M2×25
      case screws
- [ ] **4× Ruthex RX-M2x4** heat-set inserts for the top shell
- [ ] **8× rubber feet** (10 mm dia × 2 mm)
- [ ] **Print the four STLs** while waiting on PCB and modules — see
      [3D Printing](printing.md) (`*_v14.stl`, sized for the Rev E carrier)
- [ ] **microSD card** (optional) — 8–32 GB FAT32 for on-device icons
- [ ] **LRA coin motor** (optional) — plugs into J10; the on-board piezo
      still beeps without it

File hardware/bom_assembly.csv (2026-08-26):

Item | Qty | Exact spec | Where to buy | Est. cost (USD) | Notes
ScreenKey module | 6 | Waveshare 0.85inch ScreenKey Module B (SKU 34168) | waveshare.com | ~$66 ($11 ea) | Includes the cable and brass standoffs. Buy Module B (black cap + switch + PCB)
Carrier PCB | 1 | 59.5 x 108.5 mm Rev E 2-layer; files in hardware/pcb/gerbers | JLCPCB / PCBWay | ~$15 for 5 boards | Upload data_streamdeck_gerbers.zip. SMT assembly recommended (IMU ALS LEDs haptic). Parts in hardware/pcb/bom.csv
Printed: bottom tray | 1 | hardware/enclosure/stl/deck_bottom_v14.stl | Your 3D printer | ~$1 filament | PETG or PLA+; flat on bed; no supports. LED windows + SD + USB + Qwiic
Printed: top shell | 1 | hardware/enclosure/stl/deck_top_v14.stl | Your 3D printer | ~$1 filament | Face-down; no supports. ALS light-pipe hole
Printed: corner spacers | 4 | hardware/enclosure/stl/corner_spacers_x4_v14.stl | Your 3D printer | pennies | 100% infill; replaces the factory standoff at the 4 deck corners
Printed: desk stand | 1 | hardware/enclosure/stl/deck_stand_v14.stl | Your 3D printer | ~$1 filament | Optional 25 degree stand
Heat-set insert M2 | 4 | Ruthex RX-M2x4 brass (3.2 mm install hole) | Amazon "ruthex M2" | ~$8 per 50-pack | Goes into the top shell face plate
Screw M2x25 countersunk | 4 | M2 x 25 mm flat head countersunk DIN 965 (Phillips) or ISO 14581 (Torx) A2 | Amazon / AliExpress "M2x25 DIN 965" | ~$6 assorted box | The 4 case screws. Heads sink into the foot recesses and are hidden by the rubber feet
Screw M2x5 | 12 | M2 x 5 mm hex socket cap ISO 4762 / DIN 912 A2 | Same assorted box as above | included | Fixes modules to the carrier from below
Rubber feet | 8 | 10 mm dia x 2 mm self-adhesive | Amazon | ~$5 per sheet | 4 on the deck + 4 on the stand
LRA coin motor | 1 | 8 mm LRA (e.g. Vybronics VG0832013D) | Digi-Key / LCSC | ~$2 | Optional — plugs into J10. On-board piezo still beeps without it
microSD card | 1 | 8-32 GB; FAT32 | Anywhere | ~$5 | Optional - on-device icons and animations
USB-C cable | 1 | USB 2.0 data cable | You own one | - | Deck to computer

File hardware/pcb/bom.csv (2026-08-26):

Reference | Value | Footprint | Qty | MPN | Supplier | Notes
H1-H4 | MountingHole 2.2mm | MountingHole:MountingHole_2.2mm_M2 | 4 |  |  | M2x25 corner case screws pass through into the corner-module nuts
H5-H16 | MountingHole 2.2mm | MountingHole:MountingHole_2.2mm_M2 | 12 |  |  | Module standoff clearance holes (M2x5 into ScreenKey factory standoffs)
J1-J6 | Molex PicoBlade 9P right-angle | Connector_Molex:Molex_PicoBlade_53261-0971_1x09-1MP_P1.25mm_Horizontal | 6 | 53261-0971 | Molex | Same MX1.25/PicoBlade family as the module connector; in-box cable plugs in; pin1=KEY. Verified alternate: HDGC HDGC1251WR-S-9P (SMT PicoBlade clone; JLC-stocked)
J7 | USB-C receptacle | Connector_USB:USB_C_Receptacle_GCT_USB4105-xx-A_16P_TopMnt_Horizontal | 1 | USB4105-GF-A | GCT | Horizontal top-mount; port exits rear board edge @ X=29.75mm
J8 | microSD push-push | Connector_Card:microSD_HC_Hirose_DM3D-SF | 1 | DM3D-SF | Hirose | Card ejects right board edge; SPI mode on bus A
J9 | Qwiic / StemmaQT 4P | Connector_JST:JST_SH_SM04B-SRSS-TB_1x04-1MP_P1.00mm_Horizontal | 1 | SM04B-SRSS-TB | JST | I2C expansion; exits rear wall next to USB
J10 | LRA motor 2P | Connector_JST:JST_SH_SM02B-SRSS-TB_1x02-1MP_P1.00mm_Horizontal | 1 | SM02B-SRSS-TB | JST | Haptic LRA (e.g. Vybronics VG0832013D) plugs in
U1 | ESP32-S3-WROOM-1-N16R8 | RF_Module:ESP32-S3-WROOM-1 | 1 | ESP32-S3-WROOM-1-N16R8 | Espressif | 16MB flash 8MB PSRAM native USB; dual SPI display driver
U2 | AMS1117-3.3 | Package_TO_SOT_SMD:SOT-223-3_TabPin2 | 1 | AMS1117-3.3 | AMS | 1A 3.3V LDO from USB 5V — headroom for 6 backlights + SD + sensors
U3 | USBLC6-2SC6 | Package_TO_SOT_SMD:SOT-23-6 | 1 | USBLC6-2SC6 | ST | USB ESD protection on D+/D-/VBUS
U4 | LSM6DS3TR-C IMU | Package_LGA:LGA-14_3x2.5mm_P0.5mm_LayoutBorder3x4y | 1 | LSM6DS3TR-C | ST | 6-axis accel+gyro; INT1 on IO9 for wake-on-pickup / tap
U5 | VEML7700 ambient light | OpenScreenDeck:VEML7700-TT | 1 | VEML7700-TT | Vishay | I2C ALS for auto backlight dimming; needs light window in enclosure front
U6 | DRV2605L haptic driver | Package_SO:MSOP-10_3x3mm_P0.5mm | 1 | DRV2605LDGSR | TI | LRA driver with effect library; EN on IO44
U7 | 74AHCT1G125 level shifter | Package_TO_SOT_SMD:SOT-23-5 | 1 | SN74AHCT1G125DBVR | TI | 3.3V -> 5V LED data buffer for SK6812 chain
D1-D8 | SK6812MINI-E RGB LED | LED_SK6812MINI:LED_SK6812MINI_PLCC4_3.5x3.5mm_P1.75mm | 8 | SK6812MINI-E | OPSCO | Edge-glow chain: 2 rear + 6 side; 5V VBUS powered; data from U7
BZ1 | Piezo buzzer | Buzzer_Beeper:Buzzer_CUI_CPT-9019S-SMT | 1 | CPT-9019S-SMT-TR | CUI | 4kHz passive piezo; LEDC tone on IO43 via R10
SW1 | BOOT tactile C&K KMR2 | Button_Switch_SMD:SW_Push_1P1T_NO_CK_KMR2 | 1 | KMR221GLFS | C&K | GPIO0 strap — hold for USB download mode
SW2 | RESET tactile C&K KMR2 | Button_Switch_SMD:SW_Push_1P1T_NO_CK_KMR2 | 1 | KMR221GLFS | C&K | EN to GND — tap while holding BOOT to enter bootloader
C1-C6 | 100nF 0402 | Capacitor_SMD:C_0402_1005Metric | 6 |  |  | Per ScreenKey VCC
C7 | 10uF 0805 | Capacitor_SMD:C_0805_2012Metric | 1 |  |  | LDO output bulk
C8 | 10uF 0805 | Capacitor_SMD:C_0805_2012Metric | 1 |  |  | LDO input
C9-C11 | 100nF/1uF 0402 | Capacitor_SMD:C_0402_1005Metric | 3 |  |  | ESP32 decoupling + EN RC
C12 | 1uF 0402 | Capacitor_SMD:C_0402_1005Metric | 1 |  |  | DRV2605L VREG
C13-C15 | 100nF 0402 | Capacitor_SMD:C_0402_1005Metric | 3 |  |  | IMU / ALS / haptic decoupling
C16 | 100nF 0402 | Capacitor_SMD:C_0402_1005Metric | 1 |  |  | Level shifter 5V decoupling
C17 | 10uF 0805 | Capacitor_SMD:C_0805_2012Metric | 1 |  |  | LED 5V rail bulk
R1-R6 | 10k 0402 | Resistor_SMD:R_0402_1005Metric | 6 |  |  | KEY line pull-ups
R7-R8 | 5.1k 0402 | Resistor_SMD:R_0402_1005Metric | 2 |  |  | USB-C CC1/CC2 pulldowns
R9 | 10k 0402 | Resistor_SMD:R_0402_1005Metric | 1 |  |  | EN pull-up
R10 | 100R 0402 | Resistor_SMD:R_0402_1005Metric | 1 |  |  | Piezo series resistor

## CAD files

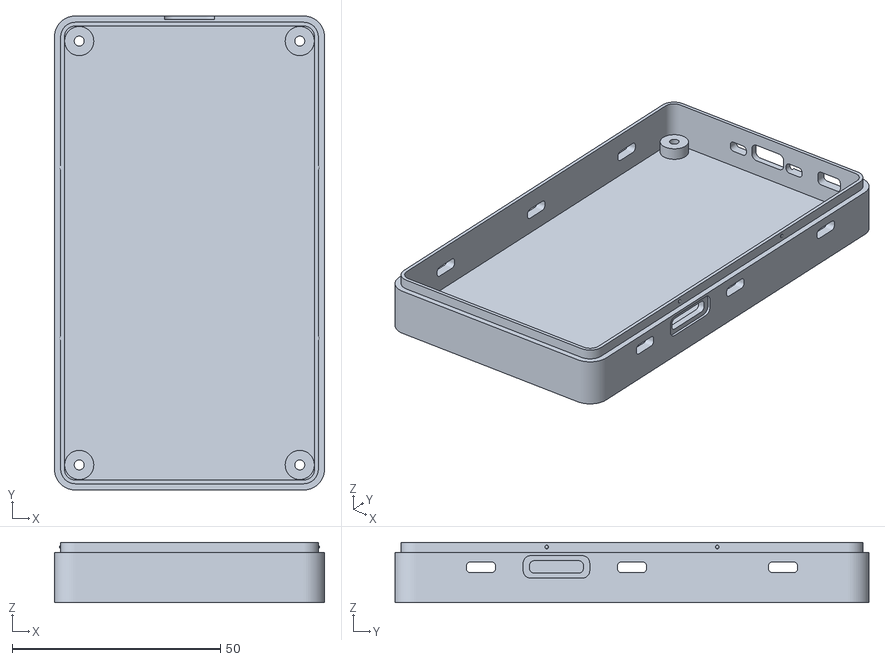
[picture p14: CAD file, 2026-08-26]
hardware/3d/assembly/enclosure_bottom_pcbframe.stl
64.9 x 113.9 x 14.5

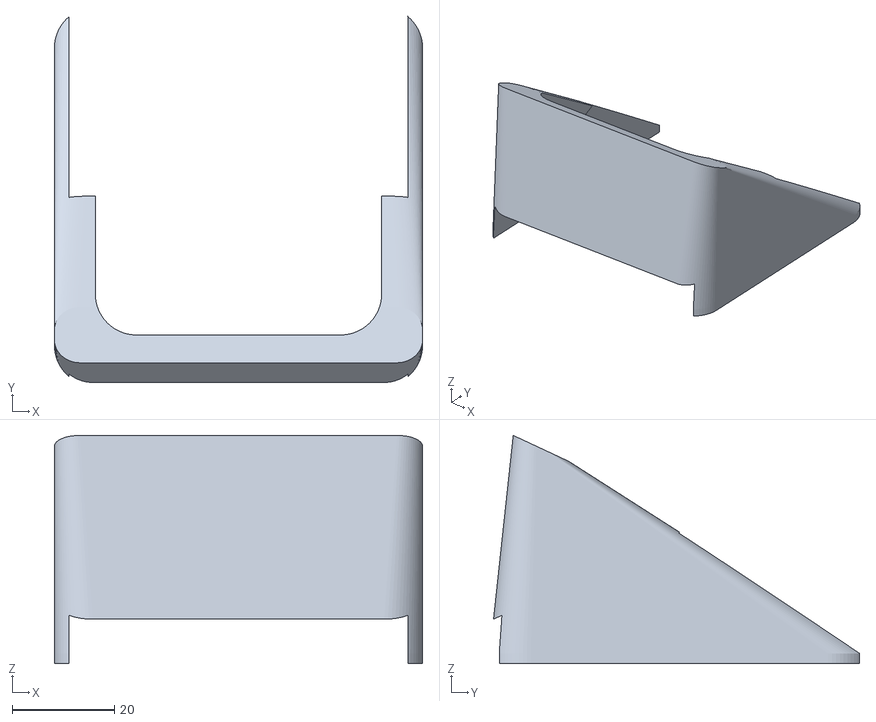
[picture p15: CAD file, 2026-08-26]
hardware/enclosure/stl/deck_stand_v14.stl
71.9 x 71.4 x 44.5

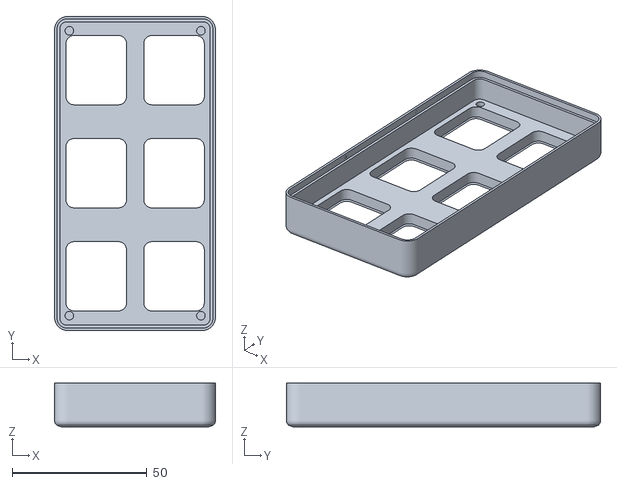
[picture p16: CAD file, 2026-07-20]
previews/enclosure-top-shell.stl
59.8 x 116.7 x 16.2

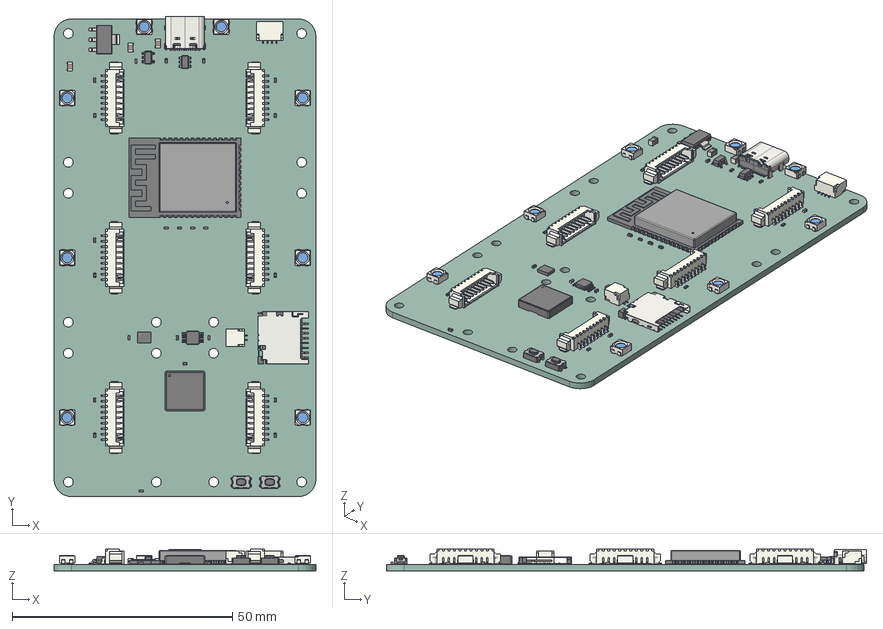
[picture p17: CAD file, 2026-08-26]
hardware/3d/assembly/rev_e_board.step
59.5 x 109.1 x 5.00 mm
SOT-23-5
R_0402_1005Metric x 10
C_0805_2012Metric x 3
C_0402_1005Metric x 14
Buzzer_Murata_PKMCS0909E4000_R1
SOT-223
LED_WS2812B-Mini_PLCC4_3.5x3.5mm_P1.8mm x 8
Molex_53261_0971 x 6
JST_SH_SM04B-SRSS-TB_1x04-1MP_P1.00mm_Horizontal
SW_Push_1P1T_NO_CK_KMR2 x 2
JST_SH_SM02B-SRSS-TB_1x02-1MP_P1.00mm_Horizontal
ESP32-S3-WROOM-1
microSD_HC_Hirose_DM3D-SF
MSOP-10_3x3mm_P0.5mm
USB_C_Receptacle_16P_TopMnt_Horizontal_GCT_USB4105-xx-A
LGA_14_3x25mm_P05mm_LayoutBorder3x4y
SOT-23-6
data_streamdeck_PCB

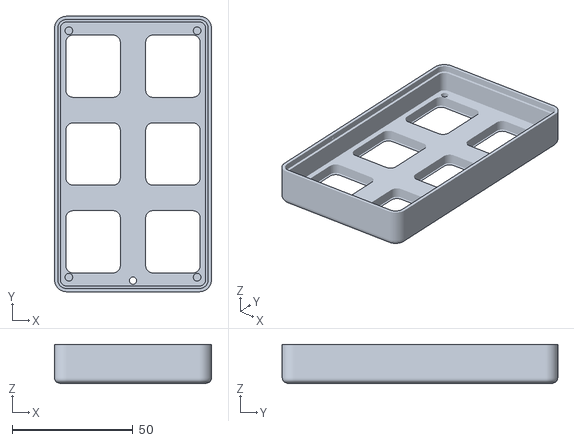
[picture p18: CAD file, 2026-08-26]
hardware/enclosure/stl/deck_top_v14.stl
64.9 x 113.9 x 16.2

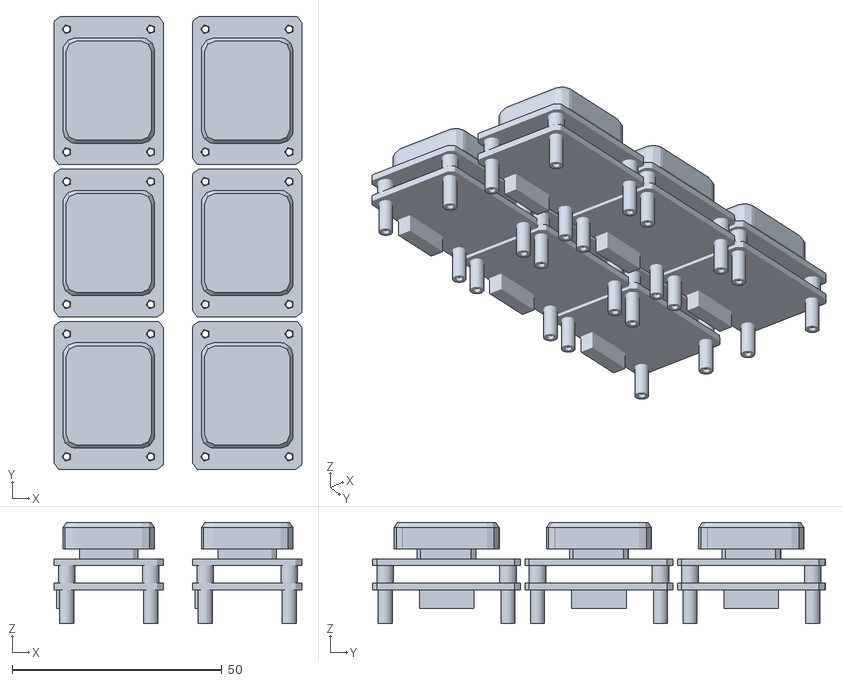
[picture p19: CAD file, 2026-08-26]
hardware/3d/assembly/modules_pcbframe.stl
59.0 x 107.9 x 24.1

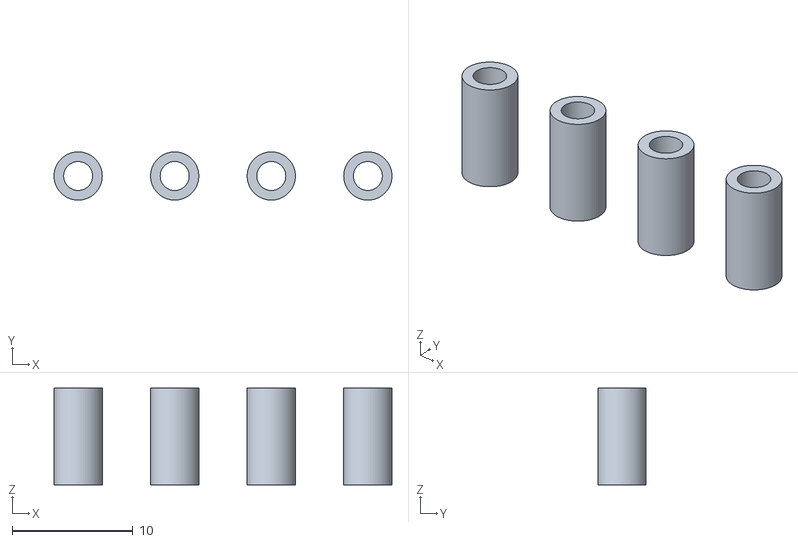
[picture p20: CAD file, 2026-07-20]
hardware/enclosure/stl/corner_spacers_x4_v14.stl
28.0 x 4.00 x 8.00

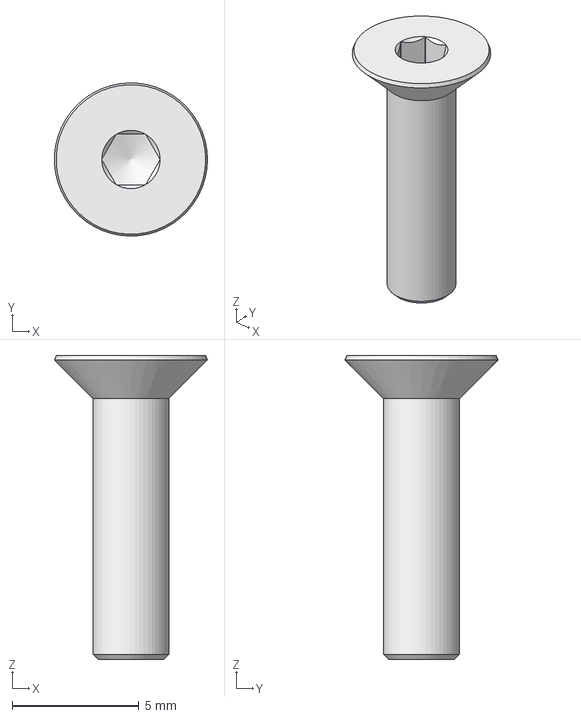
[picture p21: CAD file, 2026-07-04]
hardware/3d/fasteners/m3x12_countersunk_iso10642.step
6.04 x 6.04 x 12.0 mm

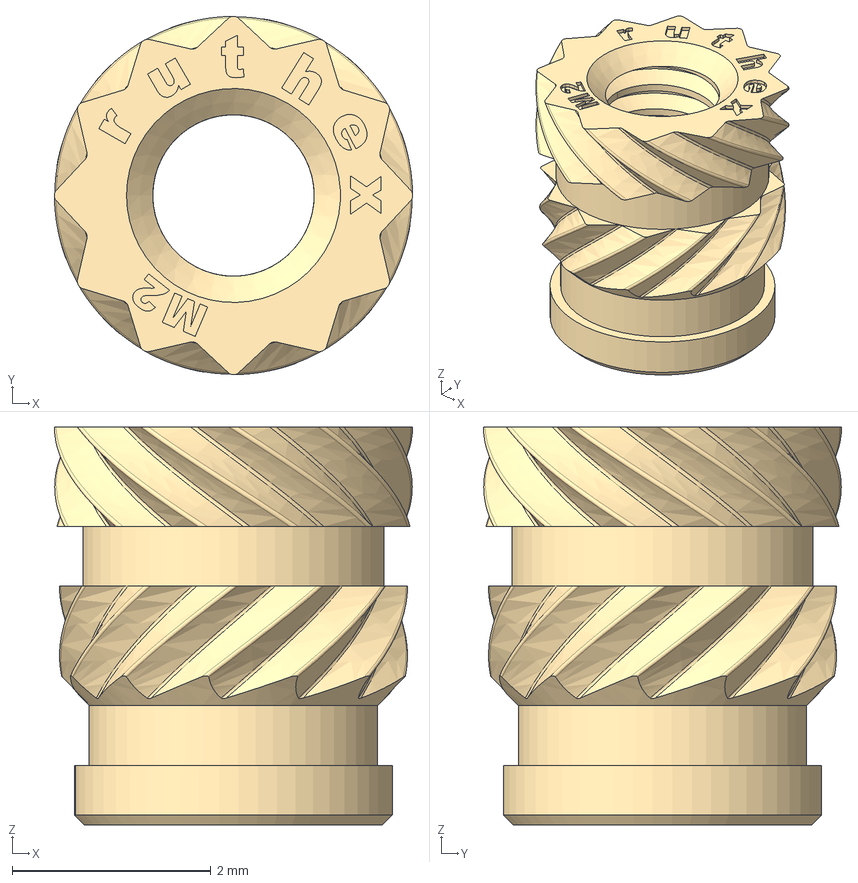
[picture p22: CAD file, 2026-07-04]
hardware/3d/fasteners/ruthex_RX-M2x4.step
3.60 x 3.60 x 4.00 mm

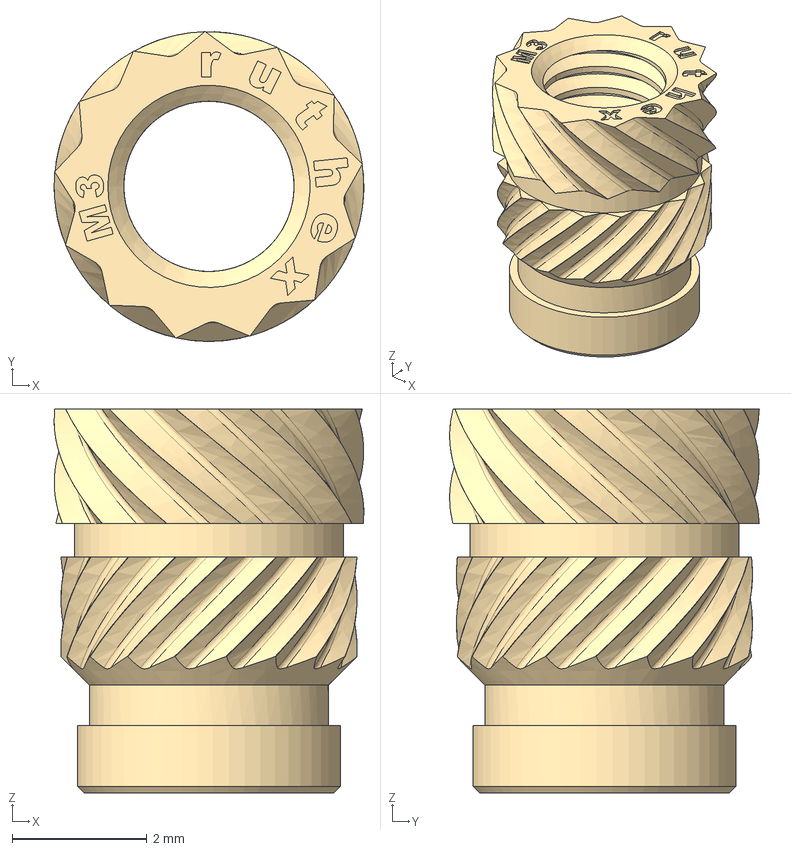
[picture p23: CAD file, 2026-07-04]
hardware/3d/fasteners/ruthex_RX-M3x5.7.stp
4.60 x 4.60 x 5.70 mm

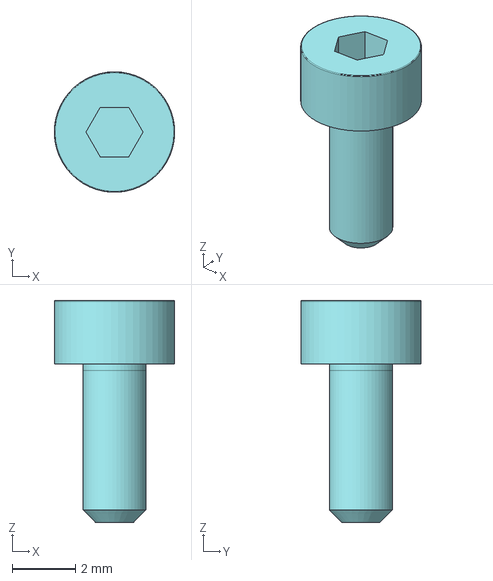
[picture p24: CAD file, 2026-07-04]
hardware/3d/fasteners/m2x5_socket_cap_iso4762.step
3.80 x 3.80 x 7.00 mm

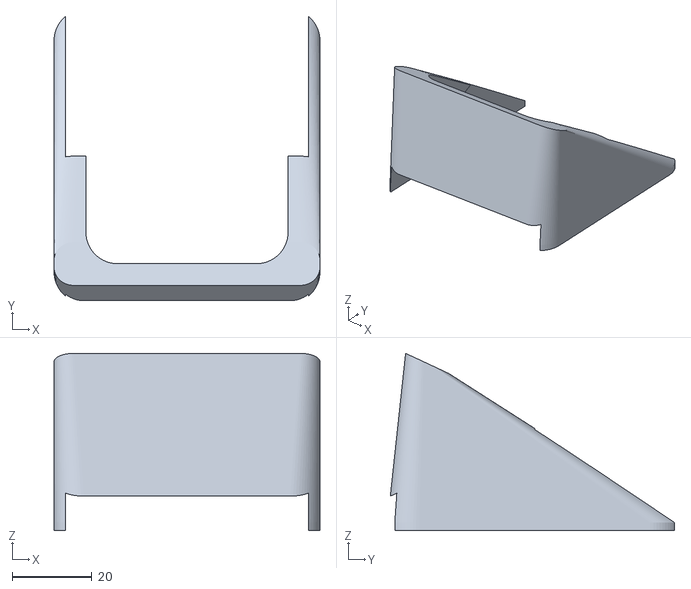
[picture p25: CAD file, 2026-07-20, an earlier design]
hardware/enclosure/stl/deck_stand_v13.stl
66.8 x 71.4 x 44.5

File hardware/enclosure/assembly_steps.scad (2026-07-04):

// ============================================================
//  Open Screen Deck — assembly step illustrations (v11)
//  Renders the docs/assembly.md step images with a consistent
//  product palette. Not a fit-check model — presentation only.
//
//  STEP = "inserts" | "prep" | "modules" | "cables" | "tray"
//         | "shell" | "screws"
// ============================================================

STEP = "modules";
NO_STANDALONE = true;
use <data_streamdeck_enclosure.scad>
use <screenkey_module.scad>

$fn = 64;

// palette
C_CASE   = "#26262b";
C_PLATE  = "#1e1e23";
C_PCB    = "#175235";
C_CONN   = "#e8e4da";
C_BRASS  = "#c9a24b";
C_STEEL  = "#8d9096";
C_ACCENT = "#d8d8dc";   // printed spacer sleeves (visually distinct from brass)
C_MODULE = "#111114";
C_CABLE  = "#d8d8dc";

// geometry constants (mirror the enclosure file)
PCB_OX = 2.34;  PCB_OY = 2.335;  PCB_W = 55;  PCB_D = 112;  PCB_T = 1.6;
FLOOR = 3.0;  LIFT = 3.0;  SPLIT = 12.0;  TOTAL_H = 28.2;  PLATE_T = 5.0;
STANDOFF = 9.7;
INNER_W = 59.68;  INNER_D = 116.67;

CORNERS = [[2.0, 4.95], [52.9, 4.95], [2.0, 106.85], [52.9, 106.85]];
function keyc(c, r) = [13.0 + c * 28.9, 17.6 + r * 38.3];

module rsq(w, h, r) { offset(r = r) square([w - 2*r, h - 2*r], center = true); }

// ── stylized carrier PCB (kicad coords local, origin board corner) ──
module carrier_pcb() {
    color(C_PCB) linear_extrude(PCB_T) difference() {
        translate([PCB_W/2, PCB_D/2]) rsq(PCB_W, PCB_D, 4);
        for (p = CORNERS) translate(p) circle(d = 2.2);
    }
    // ESP32-S3 module
    color("#3c3c40") translate([27.5 - 12.75, 36.7 - 9, PCB_T]) cube([25.5, 18, 3.1]);
    color("#2a2a2e") translate([27.5 - 12.75, 36.7 - 9, PCB_T + 3.1]) cube([25.5, 18, 0.01]);
    // USB-C at rear edge
    color(C_STEEL) translate([27.5 - 4.5, 0, PCB_T]) cube([9, 7.3, 3.2]);
    // microSD right edge
    color(C_STEEL) translate([55 - 14, 75 - 7.5, PCB_T]) cube([14, 15, 1.9]);
    // PicoBlade receptacles at J1-J6 (mouths face board centre)
    for (r = [0:2], c = [0:1]) {
        k = keyc(c, r);
        color(C_CONN)
            translate([k[0] + (c == 0 ? 1.0 : -1.0 - 4.4), k[1] - 6.5, PCB_T])
                cube([4.4, 13, 4.2]);
    }
    // BOOT/RESET
    color("#222226") translate([44, 2.2, PCB_T]) cube([4.2, 2.8, 1.4]);
    color("#222226") translate([49.5, 2.2, PCB_T]) cube([4.2, 2.8, 1.4]);
}

// ── module stack helpers (world = enclosure coords) ─────────
module module_at(c, r, spacer_corner = false, z = FLOOR + LIFT + PCB_T + STANDOFF + 5.7) {
    k = keyc(c, r);
    translate([PCB_OX + k[0], PCB_OY + k[1], z]) {
        color(C_MODULE) screenkey_module(with_cap = true, with_standoffs = false);
        // kept brass standoffs + corner spacer
        for (i = [0:3]) {
            mx = (i % 2 == 0 ? 11 : -11);
            my = (i < 2 ? 12.65 : -12.65);
            px = k[0] + mx;  py = k[1] + my;
            is_corner = (norm([px - 2, py - 4.95]) < 1 || norm([px - 52.9, py - 4.95]) < 1 ||
                         norm([px - 2, py - 106.85]) < 1 || norm([px - 52.9, py - 106.85]) < 1);
            skip = (px > 14 && px < 41 && py > 25 && py < 49) ||   // ESP32 zone
                   (px > 14 && px < 41 && py < 10) ||              // USB zone
                   (px > 50 && py > 60 && py < 90);                // SD zone
            if (is_corner)
                color(C_ACCENT) translate([mx, my, -5.7 - STANDOFF]) cylinder(d = 4, h = STANDOFF);
            else if (!skip)
                color(C_BRASS) translate([mx, my, -5.7 - STANDOFF]) cylinder(d = 3.4, h = STANDOFF);
        }
    }
}

module all_modules() { for (r = [0:2], c = [0:1]) module_at(c, r); }

module carrier_world() { translate([PCB_OX, PCB_OY, FLOOR + LIFT]) carrier_pcb(); }

module cables() {
    zb = FLOOR + LIFT + PCB_T;      // board top
    for (r = [0:2], c = [0:1]) {
        k = keyc(c, r);
        dir = (c == 0) ? 1 : -1;
        x0 = PCB_OX + k[0] + dir * 6.0;     // leaves receptacle
        xf = PCB_OX + k[0] + dir * 9.2;     // fold line
        y  = PCB_OY + k[1];
        color(C_CABLE) {
            translate([min(x0, xf), y - 5.75, zb + 0.6]) cube([abs(xf - x0), 11.5, 0.9]);
            translate([xf - 0.45, y - 5.75, zb + 0.6]) cube([0.9, 11.5, 5.4]);
            translate([min(xf - dir * 5.5, xf), y - 5.75, zb + 5.1]) cube([5.5, 11.5, 0.9]);
        }
    }
}

module corner_screw() {
    // DIN 965 countersunk flat head M2x25 (length includes head)
    color(C_STEEL) {
        cylinder(d1 = 3.8, d2 = 2.0, h = 1.2);
        translate([0, 0, 1.2]) cylinder(d = 2.0, h = 23.8);
    }
}

// ── steps ────────────────────────────────────────────────────
if (STEP == "inserts") {
    // top shell face-down + inserts above their holes
    rotate([180, 0, 0]) translate([0, -INNER_D, -TOTAL_H]) color(C_PLATE) top_shell();
    for (p = CORNERS)
        translate([PCB_OX + p[0], INNER_D - (PCB_OY + p[1]), TOTAL_H - SPLIT - PLATE_T + 8])
            color(C_BRASS) difference() {
                cylinder(d = 3.5, h = 4);
                translate([0, 0, -0.1]) cylinder(d = 2, h = 4.2);
            }
} else if (STEP == "prep") {
    // one module rear-up: 3 brass standoffs stay, amber spacer hovers
    // above the corner position it replaces
    translate([0, 0, 15.4]) rotate([180, 0, 0]) {
        color(C_MODULE) screenkey_module(with_cap = true, with_standoffs = false);
        for (i = [0:3]) {
            mx = (i % 2 == 0 ? 11 : -11);
            my = (i < 2 ? 12.65 : -12.65);
            if (i == 3)
                color(C_ACCENT) translate([mx, my, -5.7 - STANDOFF - 9])
                    cylinder(d = 4, h = STANDOFF);
            else
                color(C_BRASS) translate([mx, my, -5.7 - STANDOFF]) cylinder(d = 3.4, h = STANDOFF);
        }
    }
} else if (STEP == "modules") {
    carrier_world();
    all_modules();
} else if (STEP == "cables") {
    // exploded: modules lifted 14, cables stretched between board and modules
    LIFT_EXP = 14;
    carrier_world();
    for (r = [0:2], c = [0:1]) module_at(c, r, z = FLOOR + LIFT + PCB_T + STANDOFF + 5.7 + LIFT_EXP);
    zb = FLOOR + LIFT + PCB_T;
    for (r = [0:2], c = [0:1]) {
        k = keyc(c, r);
        dir = (c == 0) ? 1 : -1;
        cx = PCB_OX + k[0];
        y  = PCB_OY + k[1];
        xf = cx + dir * 9.2;                       // fold line
        xa = min(cx + dir * 6.0, xf);
        color(C_CABLE) {
            translate([xa, y - 5.75, zb + 0.6]) cube([3.2, 11.5, 0.9]);
            translate([xf - 0.45, y - 5.75, zb + 0.6]) cube([0.9, 11.5, 5.4 + LIFT_EXP]);
            translate([dir > 0 ? xf - 5.5 : xf, y - 5.75, zb + 5.1 + LIFT_EXP]) cube([5.5, 11.5, 0.9]);
        }
    }
} else if (STEP == "tray") {
    color(C_CASE) bottom_shell();
    translate([0, 0, 14]) { carrier_world(); all_modules(); cables(); }
} else if (STEP == "shell") {
    color(C_CASE) bottom_shell();
    carrier_world(); all_modules(); cables();
    translate([0, 0, 16]) color(C_PLATE) top_shell();
} else if (STEP == "screws") {
    // deck flipped bottom-up, screws hovering above corner holes
    translate([0, INNER_D, TOTAL_H]) rotate([180, 0, 0]) {
        color(C_CASE) bottom_shell();
        carrier_world(); all_modules();
        color(C_PLATE) top_shell();
    }
    for (p = CORNERS)
        translate([PCB_OX + p[0], INNER_D - (PCB_OY + p[1]), TOTAL_H + 30])
            rotate([180, 0, 0]) corner_screw();   // tip down, toward the hole
}

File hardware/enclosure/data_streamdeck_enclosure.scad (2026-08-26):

// ============================================================
//  Open Screen Deck — Enclosure v14  "Rev E wide-pitch + glow"
//
//  v14 (PCB Rev E): key pitch 33.0 x 36.3 (uniform 11 mm cap-to-cap),
//  carrier 59.5 x 108.5 mm, 8x SK6812 edge-glow windows (3 left,
//  3 right, 2 rear), VEML7700 light-pipe hole in the face plate,
//  Qwiic (JST-SH) opening in the rear wall next to USB.
//
//  ASSEMBLY-FIRST architecture — modules keep their FACTORY brass
//  standoffs; the 4 CASE screws run straight through the corner
//  modules' soldered M2 nuts (off-the-shelf part, untouched):
//
//    1. Screw 6 modules to the carrier: M2×5 from the carrier
//       underside into the factory standoff tips (non-corner spots).
//       At the 4 deck corners swap the factory standoff for the
//       printed 8.0 mm spacer sleeve (open bore for the case screw).
//    2. Plug the 6 in-box cables (module → carrier PicoBlade).
//    3. Drop the carrier onto the tray posts, snap the top shell on.
//    4. 4× M2×25 from below: tray → carrier → spacer → module
//       corner nut → RX-M2x4 insert in the top plate. One screw
//       per corner marries bottom case + PCB + module + top case.
//
//  Stack (bottom→top):
//    floor 3.0 (head recess 2.1) → PCB lift 3.0 → carrier 1.6
//    → standoff/spacer 8.0 (clears mated PicoBlade) → module 7.4
//    → module front @ 23.0 → gap 0.2 → face plate 5.0 (M2 inserts)
//  Deck body ≈ 58.9 × 115.9 × 28.2 mm; caps 3.4 mm proud.
//  M2×25 check: head seats z0.9–2.9, tip z27.9; insert spans
//  z23.2–27.4 → full 4 mm engagement, tip 0.3 mm shy of the face. ✓
//
//  RENDER: "body" | "bottom" | "top" | "stand" | "spacers" |
//          "ghost" | "all"
//  Print: bottom flat, top face-down, stand upright. PETG/PLA+.
// ============================================================

RENDER = "body";
NO_STANDALONE = true;
use <screenkey_module.scad>

// ── Module (SKU 34168, standoffs removed, dual-PCB body) ────
MOD_W      = 26.01;
MOD_H      = 35.31;
MOD_BODY   = 7.4;       // front PCB + nut gap + rear PCB (vendor: 16 − 8.6)
CAP_PROUD  = 8.60;      // cap top above module front face
CAP_WX     = 21.89;     // vendor drawing — cap is RECTANGULAR
CAP_WY     = 25.13;
CAP_R      = 3.0;
CAP_CLEAR  = 0.6;       // total, per axis (0.3 per side)
MOUNT_DX   = 20.0;      // module M2 pattern (official vendor drawing)
MOUNT_DY   = 29.25;
CONN_DROP  = 4.4;       // 9P receptacle below REAR PCB
STANDOFF_L = 8.0;       // factory brass standoffs (kept installed)

// ── Grid (matches PCB Rev E, hardware/pinout.py — do not change) ──
COLS = 2;  ROWS = 3;
COL_PITCH = 33.0;   // uniform 11 mm cap-to-cap gap
ROW_PITCH = 36.3;

// ── Body ────────────────────────────────────────────────────
WALL     = 2.4;     // thick enough for the split-line tongue joint
FLOOR    = 3.0;     // thick enough to swallow the M2 cap heads
PLATE_T  = 5.0;     // thick face plate: houses the corner M2 inserts
PCB_LIFT = 3.0;     // room for M2 screw heads under carrier
PCB_W = 59.5;  PCB_D = 108.5;  PCB_TH = 1.6;

// ── Split-line joint: tongue on tray + groove in top shell ──
LIP_H   = 2.5;      // tongue height above split
LIP_T   = 0.9;      // tongue thickness (from cavity face outward)
LIP_CLR = 0.15;     // fit clearance per side
SNAP_R  = 0.45;     // snap bump radius (bumps on tongue, grooves in skirt)

CORNER_R  = 5.0;    // max radius that clears the square module corners
TOP_RND   = 2.4;    // top edge roundover (approximated, print-safe)
BOT_RND   = 1.2;    // bottom edge lead-in
SPLIT_Z   = 12.0;

// ── Derived stack ───────────────────────────────────────────
GRID_W  = MOD_W + (COLS - 1) * COL_PITCH;     // 59.01
GRID_H  = MOD_H + (ROWS - 1) * ROW_PITCH;     // 107.91
// cavity must swallow whichever is wider: module grid or the carrier PCB
CAV_W   = max(GRID_W + 0.8, PCB_W + 0.6);     // 60.10
CAV_H   = max(GRID_H + 0.8, PCB_D + 0.6);     // 109.10
INNER_W = CAV_W + 2 * WALL;                   // 64.90
INNER_D = CAV_H + 2 * WALL;                   // 113.90
PCB_OX  = (INNER_W - PCB_W) / 2;
PCB_OY  = (INNER_D - PCB_D) / 2;
PCB_Z   = FLOOR + PCB_LIFT;                   // 6.0 (carrier bottom)
REAR_Z  = PCB_Z + PCB_TH + STANDOFF_L;        // 17.3 (module rear PCB back)
MODF_Z  = REAR_Z + MOD_BODY;                  // 23.0 (module front face)
TOTAL_H = MODF_Z + 0.2 + PLATE_T;             // 25.4
CAP_TOP = MODF_Z + CAP_PROUD;                 // 31.6 (proud 6.2)

// ── Ports ───────────────────────────────────────────────────
// KiCad views the board from the top with +y DOWN, so once the PCB drops
// component-up into the tray, kicad +x lands on the enclosure's -x side:
//   enclosure_x = PCB_OX + (PCB_W - kicad_x)
// USB (kicad x=29.75, centred) is mirror-invariant; J8 (kicad x=52.0,
// card ejects the kicad x=59.5 edge) is adjacent to the enclosure x=0 wall.
USB_W = 10.0;  USB_H = 4.4;  USB_R = 1.5;
USB_CX = PCB_OX + (PCB_W - 29.75);
USB_CZ = PCB_Z + PCB_TH + 1.7;
SD_W = 13.0;  SD_H = 3.0;
SD_CY = PCB_OY + 72.4;
SD_CZ = PCB_Z + PCB_TH + 1.0;
// Qwiic (JST-SH, kicad x=49.0 on the rear y=0 edge)
QW_W = 7.0;  QW_H = 3.6;
QW_CX = PCB_OX + (PCB_W - 49.0);
QW_CZ = PCB_Z + PCB_TH + 1.6;

// ── Rev E glow + sensor features ────────────────────────────
// 8x SK6812MINI-E edge LEDs shine out through wall slots (fill with
// translucent filament, a glued diffuser strip, or leave open).
// kicad: D1/D3/D5 @ x=3.0 (-> enclosure +x wall), D2/D4/D6 @ x=56.5
// (-> enclosure x=0 wall), D7 @ (20.5,1.8) + D8 @ (38.0,1.8) rear.
LED_SLOT_W = 7.0;  LED_SLOT_H = 2.6;
LED_CY  = [PCB_OY + 17.95, PCB_OY + 54.25, PCB_OY + 90.55];
LED_CZ  = PCB_Z + PCB_TH + 0.9;      // SK6812MINI-E optical centre
LED_REAR_CX = [PCB_OX + (PCB_W - 20.5), PCB_OX + (PCB_W - 38.0)];
// VEML7700 ambient light sensor between the key columns near the front
// edge — Ø3 light-pipe hole straight through the face plate.
ALS_CX = PCB_OX + (PCB_W - 29.75);
ALS_CY = PCB_OY + 106.6;
ALS_D  = 3.0;

// ── Fasteners (real parts, CAD in hardware/3d/fasteners/) ───
// Case:    4× M2×25 COUNTERSUNK flat head (DIN 965) from BELOW, one
//          per deck corner. Path: tray floor → carrier hole → printed
//          spacer sleeve → corner module's soldered M2 nut → RX-M2x4
//          insert in the top plate. One screw clamps the whole stack.
//          The countersink sits INSIDE the rubber-foot recess, so the
//          foot covers the screw completely — nothing visible outside.
//          Stack check: flat face flush at recess floor z1.2 → tip at
//          z26.2; insert spans z23.2–27.4 → 3.0 mm engagement. ✓
// Modules: 12× M2×5 ISO 4762 from the carrier underside into the
//          factory standoff tips (non-corner positions).
// Corner screw axes = the corner modules' outermost nut positions
// (PCB holes H1-H4 at kicad (2,4.95)/(52.9,4.95)/(2,106.85)/(52.9,106.85)).
SCREW_D  = 2.4;                  // M2 free-fit through-hole
CSK_OD   = 4.8;                  // countersink mouth (DIN 965 head Ø3.8 + relief)
CSK_H    = 1.3;                  // 90° cone depth above the recess floor
POST_OD  = 7.0;                  // PCB perch posts under the corners
INSERT_D = 3.2;  INSERT_L = 4.2; // Ruthex RX-M2x4
SPACER_OD = 4.0; SPACER_BORE = 2.4;  // printed corner sleeve, 8.0 long
FOOT_OFF  = 1.8;                 // foot centre offset (diagonal, inboard) from screw axis
// (kicad x mirrors into the enclosure: x_e = PCB_OX + PCB_W − x_kicad)
// Rev E corner screws: module centres ± (10.0, 14.625) — kicad H1–H4 at
// (3.25, 3.32) / (56.25, 3.32) / (3.25, 105.17) / (56.25, 105.17)
CORNER_POS = [
    [PCB_OX + 56.25, PCB_OY + 3.325],
    [PCB_OX + 3.25,  PCB_OY + 3.325],
    [PCB_OX + 56.25, PCB_OY + 105.175],
    [PCB_OX + 3.25,  PCB_OY + 105.175]
];

// ── Stand ───────────────────────────────────────────────────
STAND_ANGLE = 25;
FOOT_D = 10;  FOOT_REC = 1.2;

COL_BODY  = "#232327";
COL_PLATE = "#1a1a1e";
COL_STAND = "#141417";
COL_PCB   = "#14442c";

$fn = 64;

// Module centres follow the PCB key grid (hardware/pinout.py truth:
// cols kicad x 13.25/46.25, rows y 17.95 + r*36.3), NOT a symmetric
// wall inset — keeps apertures + corner screws aligned with the modules.
function cx(c) = PCB_OX + 46.25 - c * COL_PITCH;   // mirrored kicad truth
function cy(r) = PCB_OY + 17.95 + r * ROW_PITCH;
function mounts() = [[MOUNT_DX/2, MOUNT_DY/2], [-MOUNT_DX/2, MOUNT_DY/2],
                     [MOUNT_DX/2, -MOUNT_DY/2], [-MOUNT_DX/2, -MOUNT_DY/2]];

module rsq2d(w, h, r) { offset(r = r) square([w - 2*r, h - 2*r], center = true); }

// ── Sculpted outer form: quarter-round edges top & bottom ───
// Roundover approximated with hull slices on a circular profile —
// every overhang stays ≥45°, so both shells print without supports
// (bottom flat on bed; top printed face-down).
function _round_in(rr, dz) = rr - sqrt(max(rr*rr - dz*dz, 0));

module deck_slice(inset) {
    translate([INNER_W/2, INNER_D/2])
        rsq2d(INNER_W - 2*inset, INNER_D - 2*inset, max(CORNER_R - inset, 1.5));
}
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

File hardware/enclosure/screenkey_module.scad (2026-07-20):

// ============================================================
//  Waveshare 0.85" ScreenKey Module B (SKU 34168) — replica v3
//
//  Construction per the OFFICIAL vendor drawing (2026-07-10,
//  docs/reference/screenkey-module/vendor-dimensions.pdf):
//    keycap 21.89 × 25.13, 8.60 proud
//    FRONT PCB 26.01 × 35.31 × 1.6  (switch + LCD FPC side)
//    4× SOLDERED THREADED NUTS (M2) between the boards @ 20.0 × 29.25
//    REAR PCB 26.01 × 35.31 × 1.6   (9P connector underneath)
//    4× removable 8 mm brass standoffs threaded into the nuts
//    cap front → rear PCB back: 16.0; with standoffs: 24.0
//
//  Mounting WITHOUT standoffs: M2 screws from behind, through the
//  rear-PCB corner holes, into the internal soldered nuts.
//
//  Origin: centre of FRONT PCB front face. Cap +Z, boards −Z.
// ============================================================

MOD_W       = 26.01;
MOD_H       = 35.31;
PCB_T       = 1.60;
NUT_GAP     = 4.20;    // soldered nut spacer between the two boards (16 − 8.6 − 2×1.6)
CAP_PROUD   = 8.60;    // cap top above front PCB front face
MOD_TOTAL   = 24.00;   // with factory standoffs installed
// depth behind front face without standoffs:
BODY_DEPTH  = PCB_T + NUT_GAP + PCB_T;              // 5.7
STANDOFF_L  = MOD_TOTAL - CAP_PROUD - BODY_DEPTH;   // 9.7 (removable)
STANDOFF_D  = 3.4;
NUT_OD      = 4.0;     // soldered M2 nut/spacer
NUT_ID      = 1.6;     // M2 thread
MOUNT_DX    = 20.00;
MOUNT_DY    = 29.25;

CAP_WX      = 21.89;
CAP_WY      = 25.13;
CAP_R       = 3.0;
CAP_H       = 6.2;
GLASS_W     = 15.21;

SW_BODY_W   = 14.0;
SW_BODY_H   = 2.4;

CONN_W      = 3.6;     // 9P PicoBlade receptacle on rear PCB underside
CONN_L      = 13.0;
CONN_H      = 4.4;

function screenkey_mounts() = [
    [ MOUNT_DX/2,  MOUNT_DY/2],
    [-MOUNT_DX/2,  MOUNT_DY/2],
    [ MOUNT_DX/2, -MOUNT_DY/2],
    [-MOUNT_DX/2, -MOUNT_DY/2]
];

// z of the rear PCB back face relative to origin (mounting datum)
function screenkey_rear_z() = -BODY_DEPTH;

module _rsq(w, h, r) {
    offset(r = r) square([w - 2*r, h - 2*r], center = true);
}

module _pcb(z_top) {
    color("#161618")
        translate([0, 0, z_top - PCB_T])
            linear_extrude(PCB_T)
                difference() {
                    _rsq(MOD_W, MOD_H, 1.5);
                    for (p = screenkey_mounts())
                        translate(p) circle(d = 2.2);
                }
}

module screenkey_cap() {
    color("#141416")
        translate([0, 0, SW_BODY_H])
            linear_extrude(CAP_H - 1.2)
                _rsq(CAP_WX, CAP_WY, CAP_R);
    color("#0d0d10")
        translate([0, 0, SW_BODY_H + CAP_H - 1.2])
            hull() {
                linear_extrude(0.01) _rsq(CAP_WX, CAP_WY, CAP_R);
                translate([0, 0, 1.2])
                    linear_extrude(0.01) _rsq(CAP_WX - 1.6, CAP_WY - 1.6, CAP_R - 0.6);
            }
    color("#1a2b3c")
        translate([0, 0, SW_BODY_H + CAP_H + 0.011])
            linear_extrude(0.05)
                _rsq(GLASS_W, GLASS_W, 0.8);
}

module screenkey_module(with_cap = true, with_standoffs = false) {
    // FRONT PCB (switch carrier)
    _pcb(0);

    // soldered threaded nut spacers between the boards
    for (p = screenkey_mounts())
        color("#c9a24b")
            translate([p[0], p[1], -PCB_T - NUT_GAP])
                difference() {
                    cylinder(d = NUT_OD, h = NUT_GAP, $fn = 24);
                    translate([0, 0, -0.1]) cylinder(d = NUT_ID, h = NUT_GAP + 0.2, $fn = 16);
                }

    // REAR PCB (connector board)
    _pcb(-PCB_T - NUT_GAP);

    // 9P receptacle on rear PCB underside
    color("#e8e4da")
        translate([MOD_W/2 - CONN_W - 0.6, -CONN_L/2, -BODY_DEPTH - CONN_H])
            cube([CONN_W, CONN_L, CONN_H]);

    // switch body on front
    color("#3a3a3e")
        linear_extrude(SW_BODY_H)
            _rsq(SW_BODY_W, SW_BODY_W, 1.2);

    // factory standoffs (removable — unscrew from the nuts)
    if (with_standoffs)
        for (p = screenkey_mounts())
            color("#b28a3e")
                translate([p[0], p[1], -BODY_DEPTH - STANDOFF_L])
                    difference() {
                        cylinder(d = STANDOFF_D, h = STANDOFF_L, $fn = 24);
                        translate([0, 0, -0.1]) cylinder(d = NUT_ID, h = STANDOFF_L + 0.2, $fn = 16);
                    }

    if (with_cap) screenkey_cap();
}

if (is_undef(NO_STANDALONE)) screenkey_module(with_standoffs = true);

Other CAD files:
hardware/enclosure/stl/deck_bottom_v14.stl
hardware/3d/assembly/enclosure_top_pcbframe.stl
hardware/3d/open_screen_deck_assembly.f3d

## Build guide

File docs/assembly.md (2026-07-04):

# Assembly Guide

Build time: **~45 minutes** once all parts are printed and on hand.
Difficulty: you've soldered once and can drive a 1.5 mm hex key — you're fine.

## What you need

All purchased parts are listed in [`hardware/bom_assembly.csv`](../hardware/bom_assembly.csv).
Print the four parts from [`hardware/enclosure/stl/`](../hardware/enclosure/stl/) first:

| Part | File | Print notes |
|---|---|---|
| Bottom tray | `deck_bottom_v11.stl` | Flat on bed, no supports |
| Top shell | `deck_top_v11.stl` | Face-down, no supports |
| Corner spacers ×4 | `corner_spacers_x4_v11.stl` | 100% infill recommended |
| Desk stand (optional) | `deck_stand_v11.stl` | Upright, 15–20% infill |

PETG or PLA+, 0.2 mm layers, 3 walls.

**Tools:** soldering iron (for the heat-set inserts), 1.5 mm hex driver, small
hex driver for M2×5, tweezers.

---

## Step 1 — Heat-set inserts into the top shell

Install the **4× Ruthex RX-M2x4** inserts into the four holes on the
**underside of the top shell's face plate** (one near each corner, directly
above where the corner keys sit). Soldering iron at ~220 °C, press gently
until flush. Let it cool before assembly.

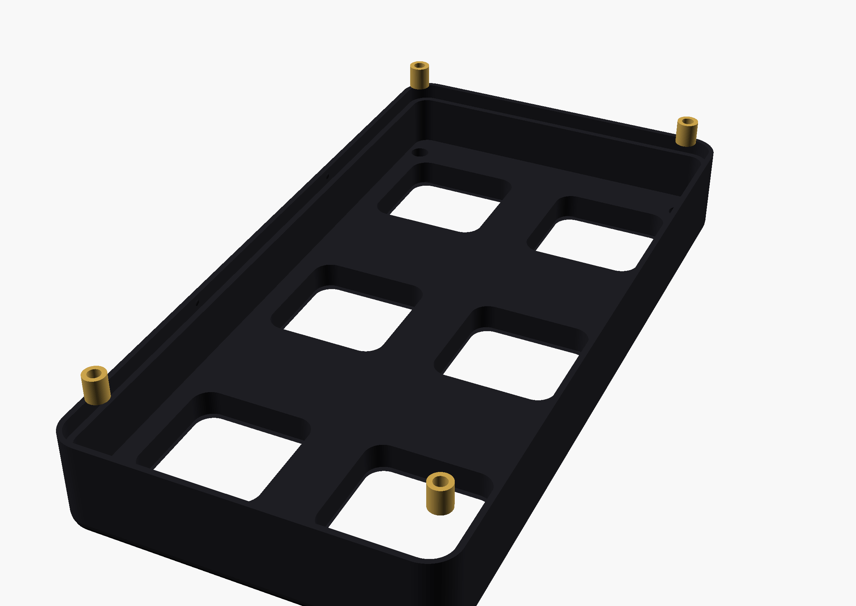
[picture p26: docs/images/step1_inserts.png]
Inserts go into the top shell face plate


## Step 2 — Prepare the ScreenKey modules

Each Waveshare module ships with 4 brass standoffs installed. They unscrew
by hand.

- **The 4 deck-corner positions:** on each corner module, remove the one
  standoff that faces the deck corner and set the **printed spacer sleeve**
  in its place. The case screw passes through it in the final step.
- **The 8 skipped positions:** remove the standoffs that would land on the
  ESP32, USB-C, or microSD (the carrier has no holes there — hold the module
  over the board and it's obvious which ones).
- Leave every other standoff installed.

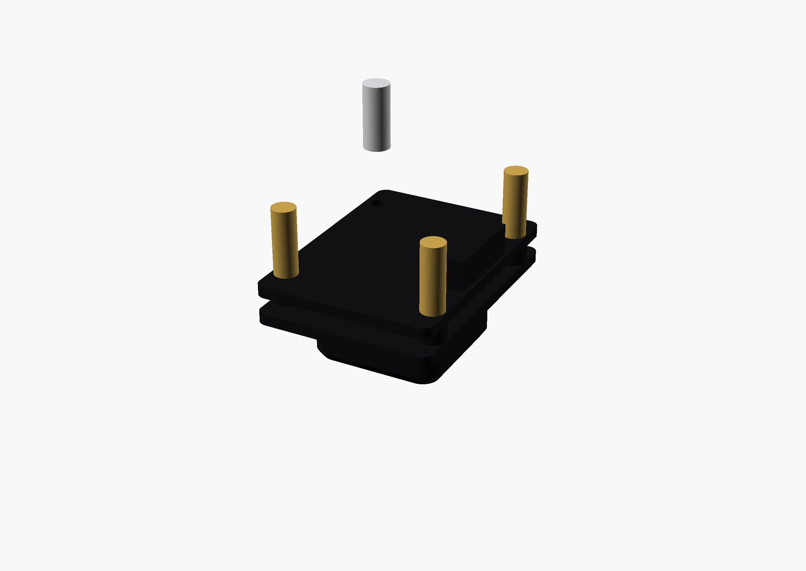
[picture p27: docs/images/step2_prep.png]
Printed spacer replaces the corner standoff


## Step 3 — Screw the modules to the carrier

Sit each module on the carrier (connector footprints show the orientation)
and drive **M2×5 screws from the underside** of the carrier into the factory
standoff tips — **12 screws total; the 4 corner positions get no screw yet.**
Snug, not gorilla-tight — the threads are brass.

The corner spacers just sit in place for now; they're captured when the
corner screws go in at the end.

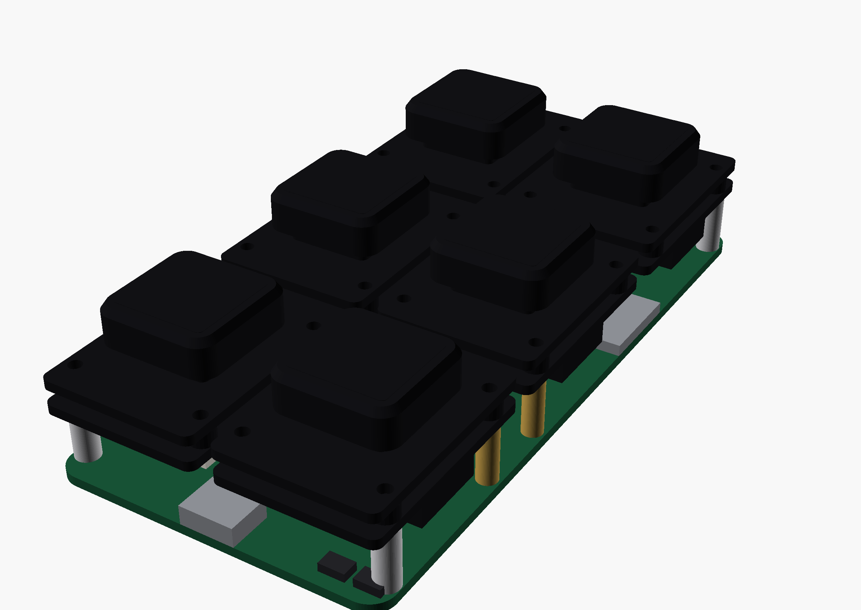
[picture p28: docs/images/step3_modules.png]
Modules mounted on carrier


## Step 4 — Connect the cables

Connect each module to its carrier connector (J1–J6) with the **200 mm
MX1.25 cable included in every module box**. Both ends are identical —
plug one into the module's 9-pin connector, one into the carrier, and fold
the slack flat under the module. The 9.7 mm standoff height is exactly the
room the folded cable needs.

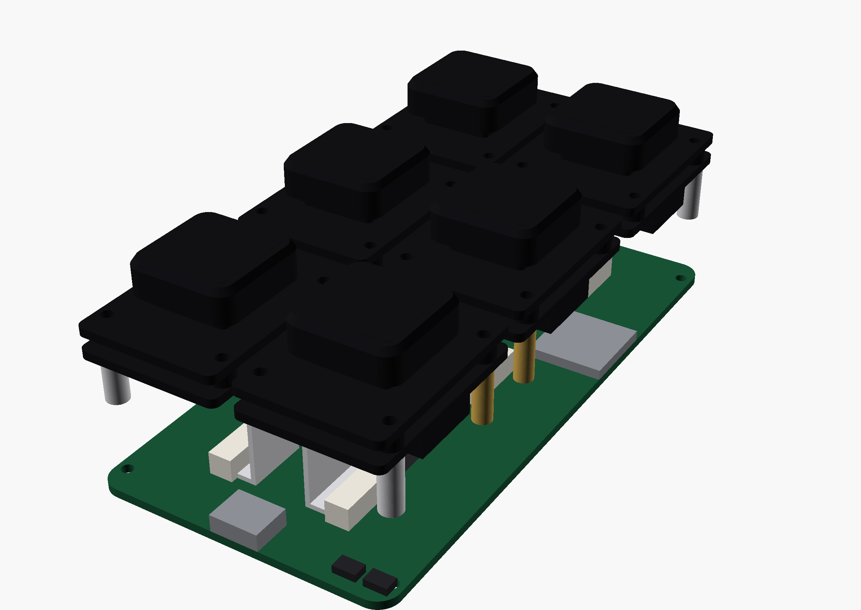
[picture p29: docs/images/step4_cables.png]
Cables connect each module to the carrier


## Step 5 — Into the tray

Drop the loaded carrier into the bottom tray — it lands on the four corner
posts, and the USB-C connector lines up with the rear slot.

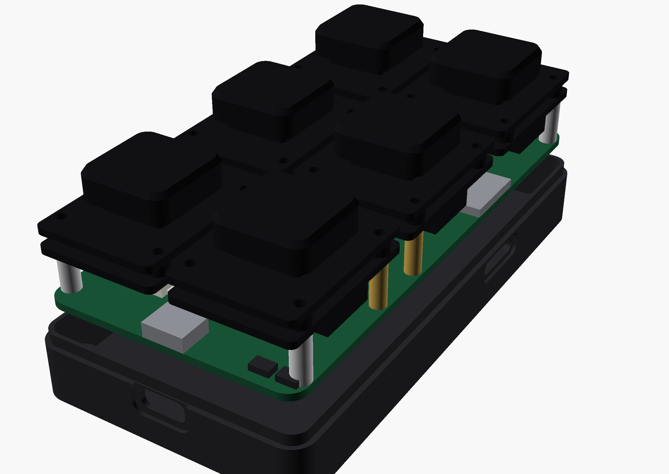
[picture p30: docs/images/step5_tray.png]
Carrier drops into the bottom tray


## Step 6 — Top shell

Snap the top shell onto the tray. The tongue-and-groove rim registers it;
the side snaps click when seated. Keys should protrude through the apertures
and press freely.

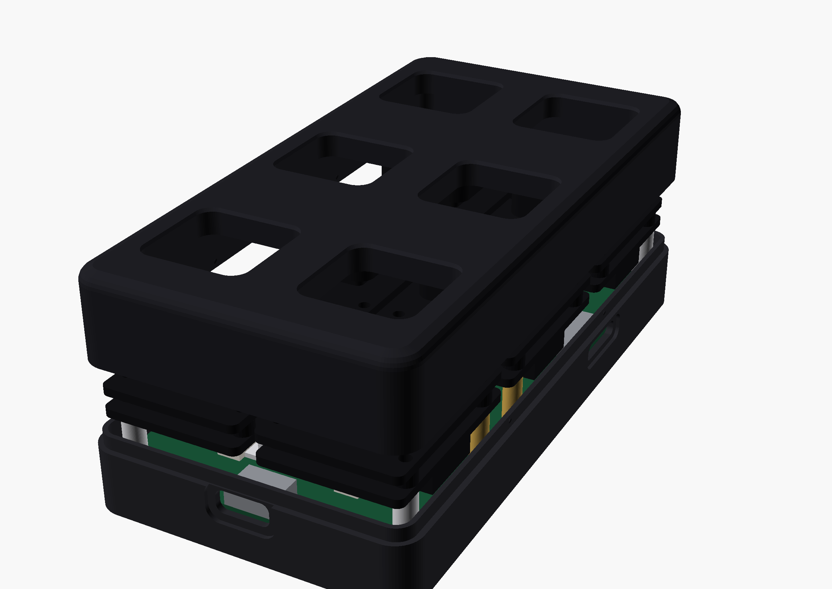
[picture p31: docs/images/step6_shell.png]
Top shell snaps on


## Step 7 — Corner screws

Flip the deck. Drive the **4× M2×25 countersunk screws** into the corner holes (they sit inside the rubber-foot recesses). Each one
passes through the tray, the carrier, the printed spacer, threads through
the corner module's soldered nut, and lands in the top-plate insert —
one screw per corner clamps the entire stack together.

Stop when the flat head seats flush in its countersink. Do not overtighten.

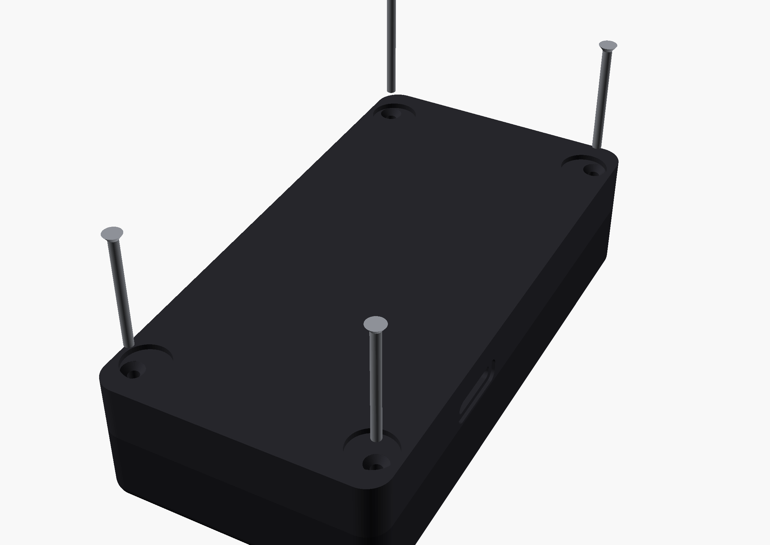
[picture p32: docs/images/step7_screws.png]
Four corner screws from below


## Step 8 — Finish

- Stick the 4 rubber feet in the corner recesses — they cover the screw heads, so no fasteners are visible anywhere on the deck.
- (Optional) insert a FAT32 microSD through the right-side slot for
  on-device icons/animations.
- Plug in USB-C and [flash the firmware](../firmware/) — see the README
  for flashing steps.
- (Optional) set the deck in the printed stand for a 25° desk angle.

Done — plug in USB-C and verify each key in the serial monitor or on the host.

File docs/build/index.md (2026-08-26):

# Build It

This is the path from an empty desk to a working deck. Order the
modules first. Print and fab while they ship. Hands-on assembly is about
an hour once the parts are in.

<div class="grid cards" markdown>

-   :material-cart:{ .lg .middle } __1 · Order__

    ---

    Six ScreenKey modules (longest lead time), a Rev E PCB from the
    Gerbers, M2 screws, inserts, rubber feet.

    [:octicons-arrow-right-24: Parts list](../getting-started/parts.md)

-   :material-printer-3d:{ .lg .middle } __2 · Print__

    ---

    Four STLs, no supports, PETG or PLA+. Start these as soon as you
    place the PCB order.

    [:octicons-arrow-right-24: 3D printing](../getting-started/printing.md)

-   :material-hammer-wrench:{ .lg .middle } __3 · Assemble__

    ---

    Heat-set inserts, screw modules to the carrier, plug the in-box
    cables, four corner screws.

    [:octicons-arrow-right-24: Assembly guide](assembly.md)

-   :material-flash:{ .lg .middle } __4 · Flash__

    ---

    USB-C into the board. Arduino IDE or the companion app. After this
    it shows up as a keyboard.

    [:octicons-arrow-right-24: Flashing](../firmware/flashing.md)

</div>

Sending your own Gerbers to JLCPCB? Walk through the
[fab checklist](fab-checklist.md) before you upload, then again at
bring-up.

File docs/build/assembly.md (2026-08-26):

# Assembly Guide

Build time: **~45 minutes** once all parts are printed and on hand.
Difficulty: you've soldered once and can drive a 1.5 mm hex key — you're fine.

## What you need

All purchased parts are listed in the [Parts List](../getting-started/parts.md).
Print the four parts from
[`hardware/enclosure/stl/`](https://github.com/vcazan/open-screen-deck/tree/main/hardware/enclosure/stl/)
first — see [3D Printing](../getting-started/printing.md) for settings.

| Part | File | Print notes |
|---|---|---|
| Bottom tray | `deck_bottom_v14.stl` | Flat on bed, no supports |
| Top shell | `deck_top_v14.stl` | Face-down, no supports |
| Corner spacers ×4 | `corner_spacers_x4_v14.stl` | 100% infill recommended |
| Desk stand (optional) | `deck_stand_v14.stl` | Upright, 15–20% infill |

PETG or PLA+, 0.2 mm layers, 3 walls.

**Tools:** soldering iron (for the heat-set inserts), 1.5 mm hex driver, small
hex driver for M2×5, tweezers.

---

## Step 1 — Heat-set inserts into the top shell

Install the **4× Ruthex RX-M2x4** inserts into the four holes on the
**underside of the top shell's face plate** (one near each corner, directly
above where the corner keys sit). Soldering iron at ~220 °C, press gently
until flush. Let it cool before assembly.

Inserts go into the top shell face plate

!!! warning "Hot inserts"
    Soldering iron at ~220 °C. Press gently until flush, then let the insert
    cool completely before handling the top shell.

## Step 2 — Prepare the ScreenKey modules

Each Waveshare module ships with 4 brass standoffs installed. They unscrew
by hand.

- **The 4 deck-corner positions:** on each corner module, remove the one
  standoff that faces the deck corner and set the **printed spacer sleeve**
  in its place. The case screw passes through it in the final step.
- **The 8 skipped positions:** remove the standoffs that would land on the
  ESP32, USB-C, or microSD (the carrier has no holes there — hold the module
  over the board and it's obvious which ones).
- Leave every other standoff installed.

Printed spacer replaces the corner standoff

## Step 3 — Screw the modules to the carrier

Sit each module on the carrier (connector footprints show the orientation)
and drive **M2×5 screws from the underside** of the carrier into the factory
standoff tips — **12 screws total; the 4 corner positions get no screw yet.**
Snug, not gorilla-tight — the threads are brass.

The corner spacers just sit in place for now; they're captured when the
corner screws go in at the end.

Modules mounted on carrier

!!! tip "Brass threads"
    Snug the M2×5 screws — do not overtighten. The factory standoff tips are
    brass.

## Step 4 — Connect the cables

Connect each module to its carrier connector (J1–J6) with the **200 mm
MX1.25 cable included in every module box**. Both ends are identical —
plug one into the module's 9-pin connector, one into the carrier, and fold
the slack flat under the module. The 8.0 mm standoff height is exactly the
room the folded cable needs.

Cables connect each module to the carrier

## Step 5 — Into the tray

Drop the loaded carrier into the bottom tray — it lands on the four corner
posts, and the USB-C connector lines up with the rear slot.

Carrier drops into the bottom tray

## Step 6 — Top shell

Snap the top shell onto the tray. The tongue-and-groove rim registers it;
the side snaps click when seated. Keys should protrude through the apertures
and press freely.

Top shell snaps on

## Step 7 — Corner screws

Flip the deck. Drive the **4× M2×25 countersunk screws** into the corner holes (they sit inside the rubber-foot recesses). Each one
passes through the tray, the carrier, the printed spacer, threads through
the corner module's soldered nut, and lands in the top-plate insert —
one screw per corner clamps the entire stack together.

Stop when the flat head seats flush in its countersink. Do not overtighten.

Four corner screws from below

!!! warning "Do not overtighten"
    Stop when the flat head seats flush in its countersink. The corner module
    nuts and brass standoffs will strip if forced.

## Step 8 — Finish

- Stick the 4 rubber feet in the corner recesses — they cover the screw heads, so no fasteners are visible anywhere on the deck.
- (Optional) insert a FAT32 microSD through the right-side slot for
  on-device icons/animations.
- Plug in USB-C and [flash the firmware](../firmware/flashing.md).
- (Optional) set the deck in the printed stand for a 25° desk angle.

Done — plug in USB-C and verify each key in the serial monitor or on the host.

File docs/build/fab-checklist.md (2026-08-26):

# Fab Checklist — Open Screen Deck Carrier PCB

Use before ordering from JLCPCB / PCBWay.

## Generate outputs

```bash
chmod +x scripts/build_hardware.sh
./scripts/build_hardware.sh
```

## Pre-order (KiCad GUI)

1. Open `hardware/pcb/data_streamdeck.kicad_pro`
2. **Schematic** — run ERC; confirm ESP32 ↔ ScreenKey nets
3. **PCB** — finish routing from ESP32 module to global labels (generator places footprints + SPI trunk)
4. **DRC** — target zero errors (current generator may show courtyard/clearance warnings until routing complete)
5. **3D view** — USB-C aligns with enclosure rear slot; microSD reachable via side slot; Qwiic on the rear wall; ALS under the face-plate hole
6. Assign **LCSC/JLC** parts in BOM tool if using SMT assembly (recommended on Rev E)

## Upload to fab

| File | Location |
|---|---|
| Gerbers | `hardware/pcb/gerbers/*.gbr` |
| Drill | `hardware/pcb/gerbers/*-NPTH.drl` and `*-PTH.drl` |
| BOM | `hardware/pcb/bom.csv` |

**Suggested spec:** 2-layer, 1.6 mm, FR4, **ENIG**, matte black mask, 1 oz copper. Board is **59.5 × 108.5 mm**.

## Assembly order

1. Solder **U1** (ESP32-S3 module) — reflow or hot plate  
2. Solder **J7** USB-C — verify orientation (rear-facing)  
3. Solder **J1–J6** — pin 1 toward KEY net (see schematic title block)  
4. Solder **J8** microSD  
5. Passives **0402/0805**  
6. Mount modules per [Assembly Guide](assembly.md) (M2×5 into factory standoffs; corner
   spacers at H1–H4 for the M2×25 case screws)  
7. Plug **6× ScreenKey** cables (in-box 200 mm; fold slack flat)  
8. Flash firmware over the on-board USB-C — see [Flashing](../firmware/flashing.md)  

## Bring-up tests

- [ ] USB-C powers board; 3.3 V at module connectors  
- [ ] All six displays init (dual SPI — J1–J3 bus A, J4–J6 bus B)  
- [ ] All six keys debounce  
- [ ] HID F13–F18 typed on Mac/Win/Linux (page 1 defaults)  
- [ ] CDC serial: `PING` → `pong`; `INFO` reports `fw`, `leds`, `imu`, `als`, `haptic`  
- [ ] Eight SK6812s light (`SET_LED` / `SELFTEST`)  
- [ ] ALS lux updates; backlight auto-dim reacts to covering the face-plate hole  
- [ ] IMU pickup haptic (lift the board)  
- [ ] microSD mounts (`SD_INFO` reports the card)  

## Enclosure fit

- [ ] M2×25 corner screws pass H1–H4 → module nuts → top-plate inserts  
- [ ] USB-C flush with rear slot  
- [ ] Qwiic opening lines up with J9  
- [ ] microSD access slot  
- [ ] LED wall windows over D1–D8  
- [ ] ALS light-pipe over the VEML7700  
- [ ] Top shell closes; keys travel OK

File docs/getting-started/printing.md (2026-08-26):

# 3D Printing

Print the four parts from
[`hardware/enclosure/stl/`](https://github.com/vcazan/open-screen-deck/tree/main/hardware/enclosure/stl/)
before assembly. No supports required on any part.

## Print settings

**Material:** PETG or PLA+  
**Layer height:** 0.2 mm  
**Walls:** 3

## Parts

| Part | File | Print notes |
|---|---|---|
| Bottom tray | `deck_bottom_v14.stl` | Flat on bed, no supports |
| Top shell | `deck_top_v14.stl` | Face-down, no supports |
| Corner spacers ×4 | `corner_spacers_x4_v14.stl` | 100% infill recommended |
| Desk stand (optional) | `deck_stand_v14.stl` | Upright, 15–20% infill |

!!! tip "Corner spacers"
    Print the corner spacers at **100% infill**. They replace the factory
    standoff at each deck corner and carry the M2×25 case screw through the
    stack.

!!! note "Rev E enclosure"
    v14 matches the Rev E carrier: wider key pitch, eight LED wall windows,
    a Ø3 ALS light-pipe in the face plate, and a Qwiic opening next to USB-C.
    Do not mix v13 prints with a Rev E board (or the other way around).

OpenSCAD sources live in
[`hardware/enclosure/`](https://github.com/vcazan/open-screen-deck/tree/main/hardware/enclosure/).
When you're ready to assemble, continue to the
[Assembly Guide](../build/assembly.md).

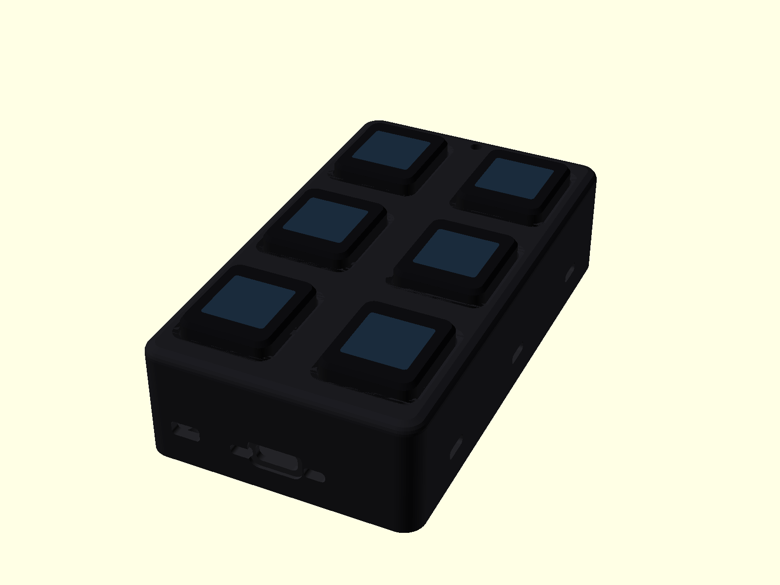
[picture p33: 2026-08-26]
docs/images/enclosure-assembled.png

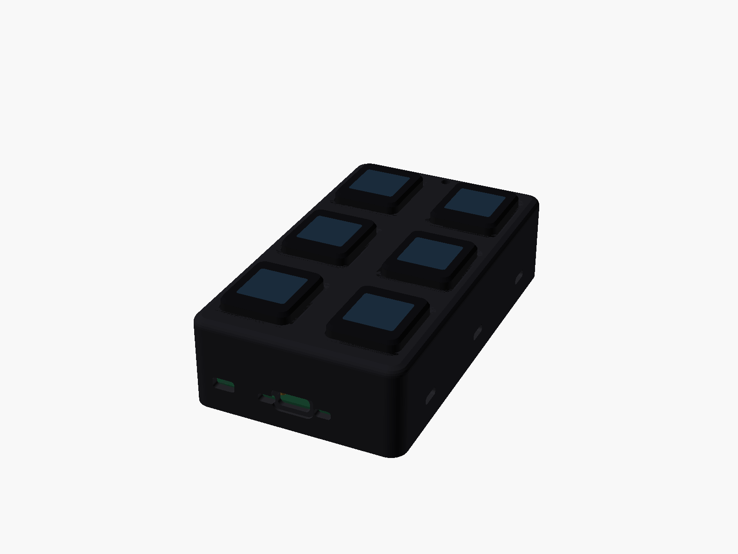
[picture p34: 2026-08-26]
previews/assembly-ghost.png

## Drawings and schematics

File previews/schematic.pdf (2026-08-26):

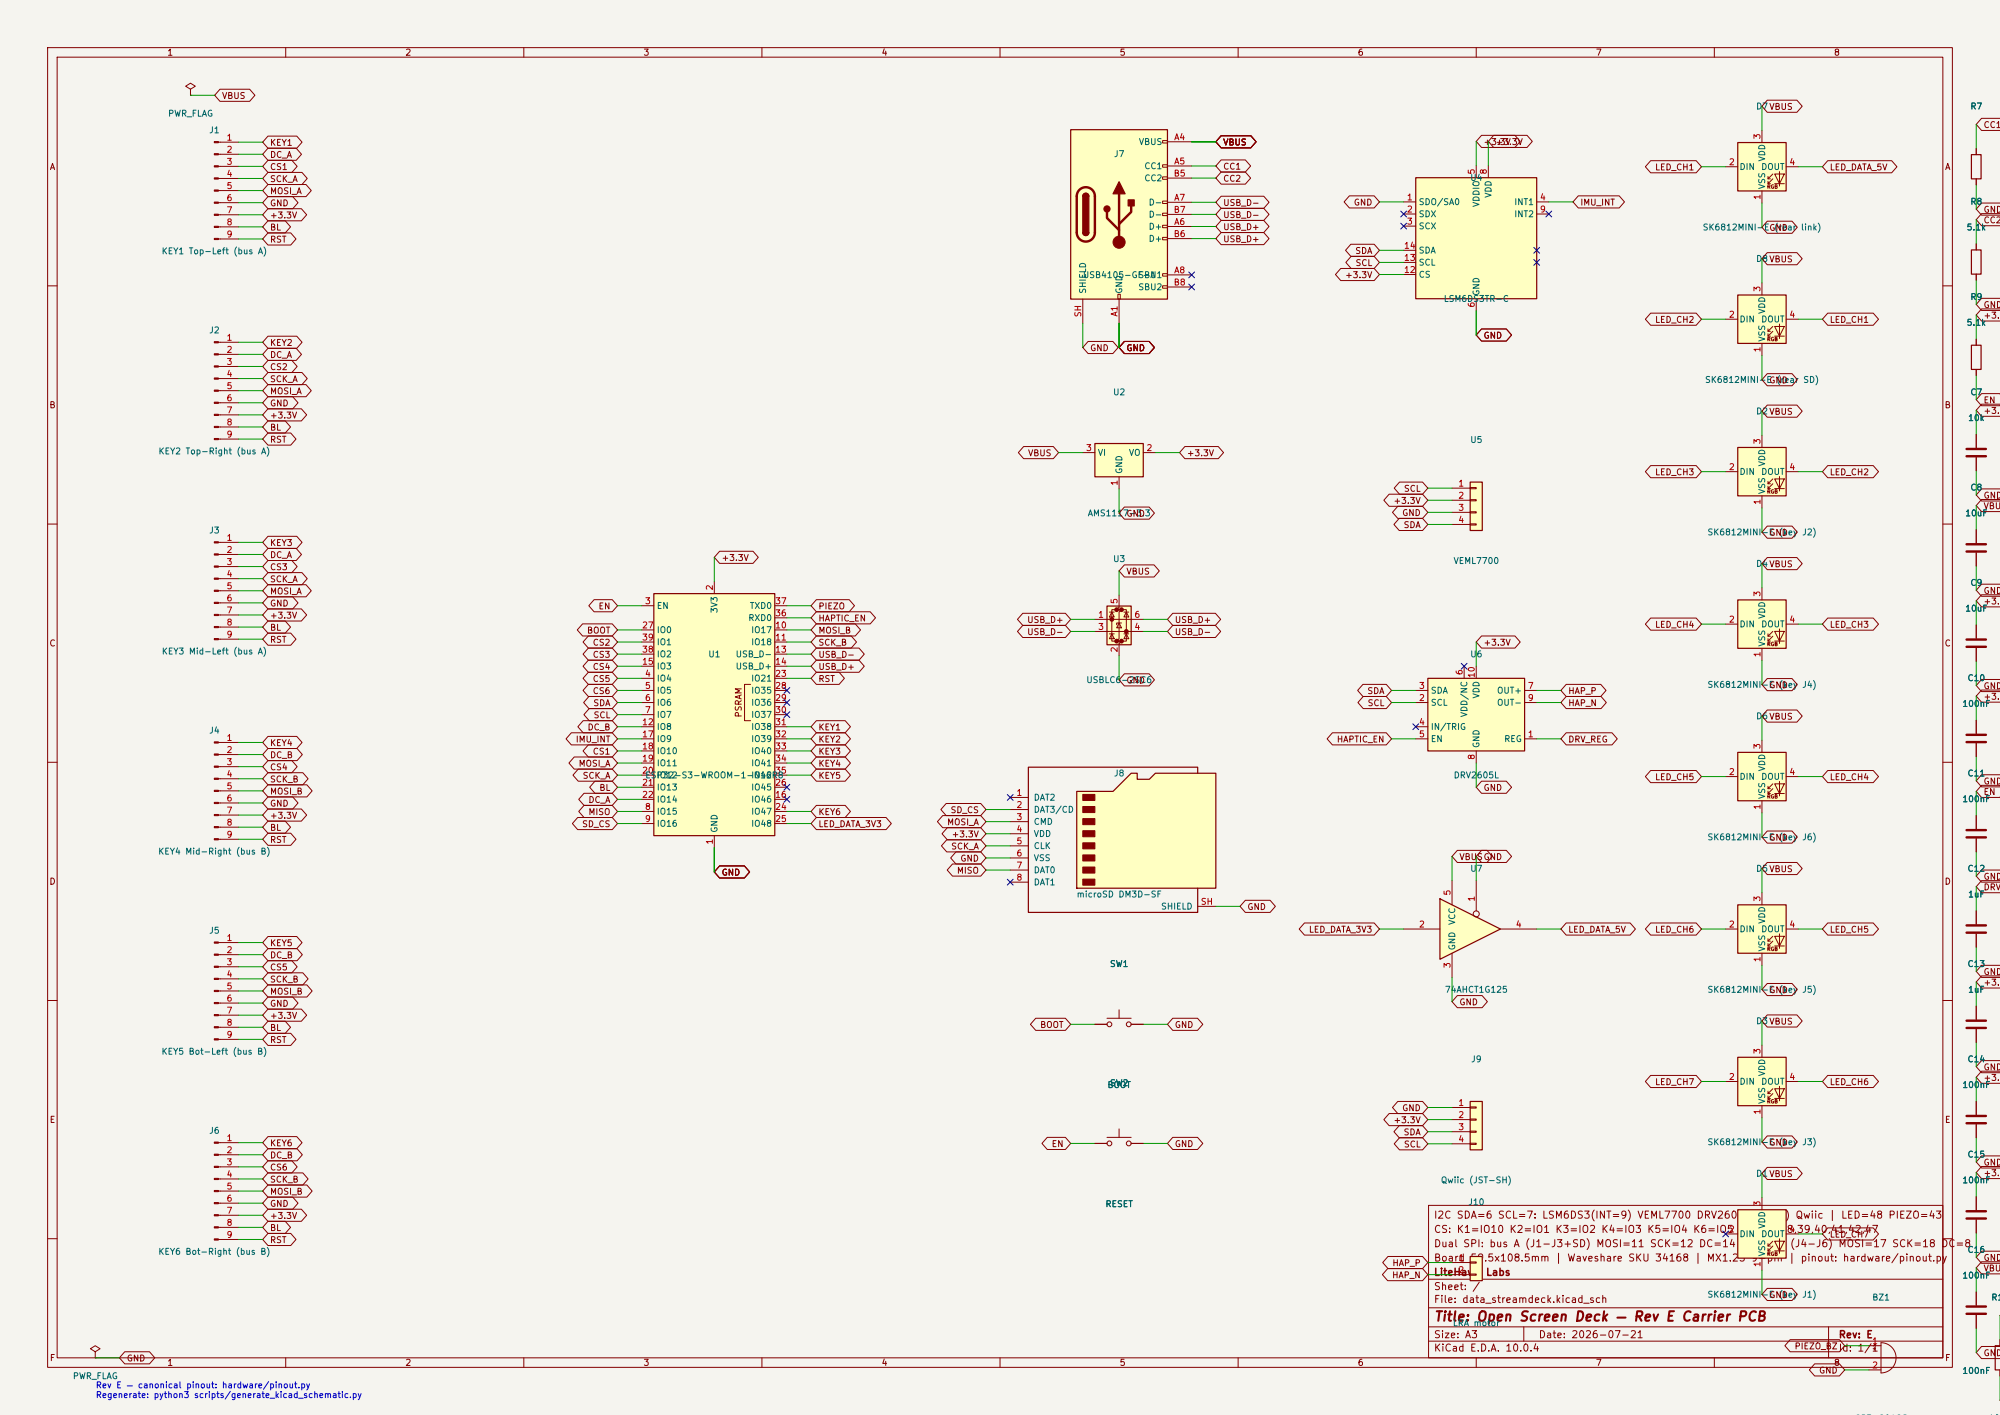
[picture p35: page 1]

I2C SDA=6 SCL=7: LSM6DS3(INT=9) VEML7700 DRV2605(EN=44) Qwiic | LED=48 PIEZO=43 123456789
MOSI_A GND +3.3V BL RST
GND +3.3V BL RST

LED_DATA_3V3 Rev E — canonical pinout: hardware/pinout.py

Sheet: /
File: data_streamdeck.kicad_sch
Title: Open Screen Deck — Rev E Carrier PCB

Size: A3 | | Rev: E
KiCad E.D.A. 10.0.4 PIEZO_BZ | Id: 1/1

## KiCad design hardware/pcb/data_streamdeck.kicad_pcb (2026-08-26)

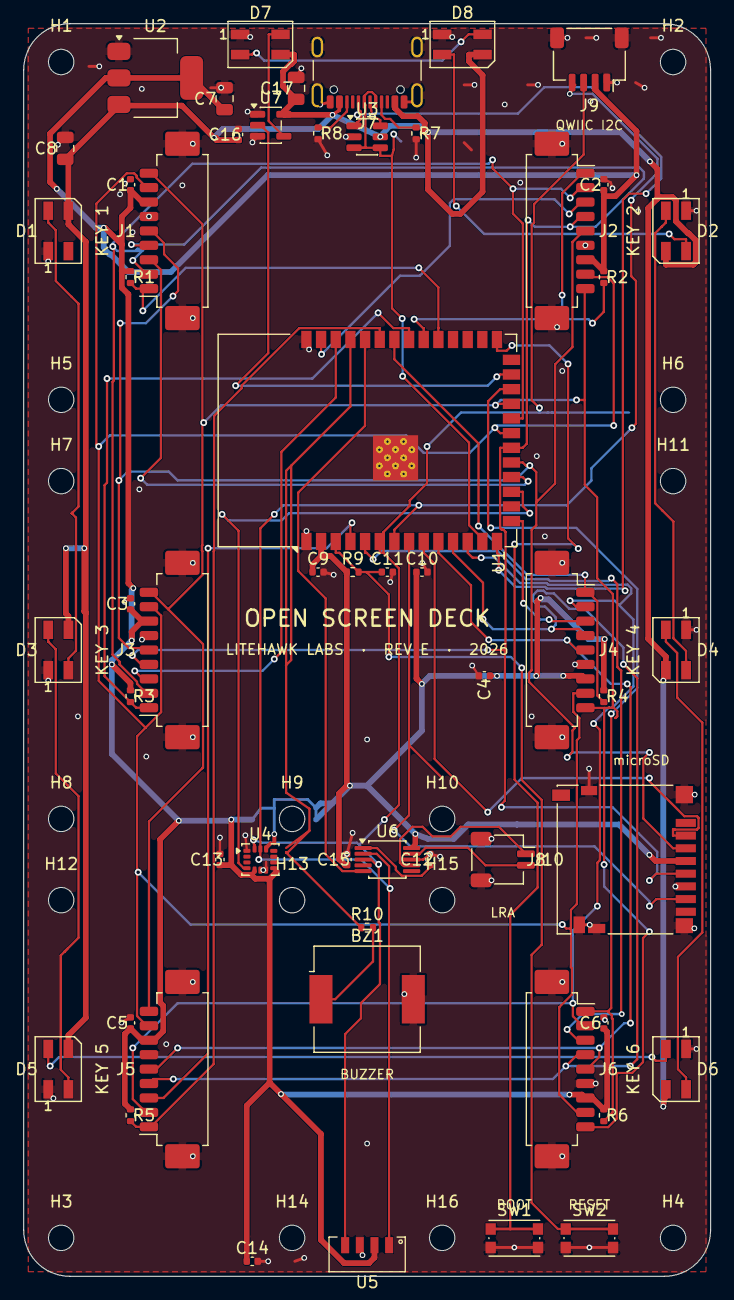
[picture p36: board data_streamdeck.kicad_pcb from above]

Board: 2 copper layers, 59.5 x 108.5 mm, 71 parts (0 on the bottom side), 49 nets.

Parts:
BZ1: CPT-9019S; Buzzer_CUI_CPT-9019S-SMT
C1, C2, C3, C4, C5, C6, C9, C10, C13, C14, C15, C16: 100nF; C_0402_1005Metric
C7, C8, C17: 10uF; C_0805_2012Metric
C11, C12: 1uF; C_0402_1005Metric
D1, D2, D3, D4, D5, D6, D7, D8: SK6812MINI-E; LED_SK6812MINI_PLCC4_3.5x3.5mm_P1.75mm
H1, H2, H3, H4: M2-corner-case-screw; MountingHole_2.2mm_M2
H5, H6, H7, H8, H9, H10, H11, H12, H13, H14, H15, H16: M2-module-standoff; MountingHole_2.2mm_M2
J1: ScreenKey 1; Molex_PicoBlade_53261-0971_1x09-1MP_P1.25mm_Horizontal
J2: ScreenKey 2; Molex_PicoBlade_53261-0971_1x09-1MP_P1.25mm_Horizontal
J3: ScreenKey 3; Molex_PicoBlade_53261-0971_1x09-1MP_P1.25mm_Horizontal
J4: ScreenKey 4; Molex_PicoBlade_53261-0971_1x09-1MP_P1.25mm_Horizontal
J5: ScreenKey 5; Molex_PicoBlade_53261-0971_1x09-1MP_P1.25mm_Horizontal
J6: ScreenKey 6; Molex_PicoBlade_53261-0971_1x09-1MP_P1.25mm_Horizontal
J7: USB4105-GF-A; USB_C_Receptacle_GCT_USB4105-xx-A_16P_TopMnt_Horizontal
J8: microSD; microSD_HC_Hirose_DM3D-SF
J9: Qwiic; JST_SH_SM04B-SRSS-TB_1x04-1MP_P1.00mm_Horizontal
J10: LRA motor; JST_SH_SM02B-SRSS-TB_1x02-1MP_P1.00mm_Horizontal
R1, R2, R3, R4, R5, R6, R9: 10k; R_0402_1005Metric
R7, R8: 5.1k; R_0402_1005Metric
R10: 100R; R_0402_1005Metric
SW1: BOOT; SW_Push_1P1T_NO_CK_KMR2
SW2: RESET; SW_Push_1P1T_NO_CK_KMR2
U1: ESP32-S3-WROOM-1-N16R8; ESP32-S3-WROOM-1
U2: AMS1117-3.3; SOT-223-3_TabPin2
U3: USBLC6-2SC6; SOT-23-6
U4: LSM6DS3TR-C; LGA-14_3x2.5mm_P0.5mm_LayoutBorder3x4y
U5: VEML7700; VEML7700-TT
U6: DRV2605L; MSOP-10_3x3mm_P0.5mm
U7: 74AHCT1G125; SOT-23-5

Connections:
+3V3: C1.1, C2.1, C3.1, C4.1, C5.1, C6.1, C7.1, C9.1, C10.1, C13.1, C14.1, C15.1, J1.7, J2.7, J3.7, J4.7, J5.7, J6.7, J8.4, J9.2, R1.1, R2.1, R3.1, R4.1, R5.1, R6.1, R9.1, U1.2, U2.2, U4.5, U4.8, U4.12, U5.2, U6.10
BL: J1.8, J2.8, J3.8, J4.8, J5.8, J6.8, U1.21
BOOT: SW1.1, U1.27
CC1: J7.A5, R7.1
CC2: J7.B5, R8.1
CS1: J1.3, U1.18
CS2: J2.3, U1.39
CS3: J3.3, U1.38
CS4: J4.3, U1.15
CS5: J5.3, U1.4
CS6: J6.3, U1.5
DC_A: J1.2, J2.2, J3.2, U1.22
DC_B: J4.2, J5.2, J6.2, U1.12
DRV_REG: C12.1, U6.1
EN: C11.1, R9.2, SW2.1, U1.3
GND: BZ1.2, C1.2, C2.2, C3.2, C4.2, C5.2, C6.2, C7.2, C8.2, C9.2, C10.2, C11.2, C12.2, C13.2, C14.2, C15.2, C16.2, C17.2, D1.1, D2.1, D3.1, D4.1, D5.1, D6.1, D7.1, D8.1, J1.6, J1.MP, J2.6, J2.MP, J3.6, J3.MP, J4.6, J4.MP, J5.6, J5.MP, J6.6, J6.MP, J7.A1, J7.A12, J7.B1, J7.B12, J7.SH, J8.6, J8.9, J8.SH, J9.1, J9.MP, J10.MP, R7.2, R8.2, SW1.2, SW2.2, U1.1, U1.40, U1.41, U2.1, U3.2, U4.1, U4.6, U4.7, U5.3, U6.8, U7.1, U7.3
HAPTIC_EN: U1.36, U6.5
HAP_N: J10.2, U6.9
HAP_P: J10.1, U6.7
IMU_INT: U1.17, U4.4
KEY1: J1.1, R1.2, U1.31
KEY2: J2.1, R2.2, U1.32
KEY3: J3.1, R3.2, U1.33
KEY4: J4.1, R4.2, U1.34
KEY5: J5.1, R5.2, U1.35
KEY6: J6.1, R6.2, U1.24
LED_CH1: D7.2, D8.4
LED_CH2: D2.4, D8.2
LED_CH3: D2.2, D4.4
LED_CH4: D4.2, D6.4
LED_CH5: D5.4, D6.2
LED_CH6: D3.4, D5.2
LED_CH7: D1.4, D3.2
LED_DATA_3V3: U1.25, U7.2
LED_DATA_5V: D7.4, U7.4
MISO: J8.7, U1.8
MOSI_A: J1.5, J2.5, J3.5, J8.3, U1.19
MOSI_B: J4.5, J5.5, J6.5, U1.10
PIEZO: R10.1, U1.37
PIEZO_BZ: BZ1.1, R10.2
RST: J1.9, J2.9, J3.9, J4.9, J5.9, J6.9, U1.23
SCK_A: J1.4, J2.4, J3.4, J8.5, U1.20
SCK_B: J4.4, J5.4, J6.4, U1.11
SCL: J9.4, U1.7, U4.13, U5.1, U6.2
SDA: J9.3, U1.6, U4.14, U5.4, U6.3
SD_CS: J8.2, U1.9
USB_D+: J7.A6, J7.B6, U1.14, U3.1, U3.6
USB_D-: J7.A7, J7.B7, U1.13, U3.3, U3.4
VBUS: C8.1, C16.1, C17.1, D1.3, D2.3, D3.3, D4.3, D5.3, D6.3, D7.3, D8.3, J7.A4, J7.A9, J7.B4, J7.B9, U2.3, U3.5, U7.5

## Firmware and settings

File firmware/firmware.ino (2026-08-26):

/**
 * Open Screen Deck — ESP32-S3 firmware
 * 6× Waveshare 0.85" ScreenKey (ST7735, 128×128) on the Tier B carrier PCB.
 * USB composite: HID keyboard + CDC serial (companion app protocol).
 *
 * Module map:
 *   config.h        pins, constants, reserved HID codes, timing
 *   state.*         per-key config + NVS persistence
 *   orientation.*   deck rotation, logical↔physical key mapping
 *   pages.*         multi-page deck state and slot arithmetic
 *   display.*       ST7735 panels, key-face rendering, overlays
 *   media.*         microSD icons + animation player
 *   input.*         switches, debouncing, multi-tap engine
 *   leds.*          8× SK6812 status/glow LEDs (Rev E)
 *   sensors.*       LSM6DS3TR-C pickup + VEML7700 auto-dim (Rev E)
 *   haptics.*       DRV2605L LRA + piezo feedback (Rev E)
 *   protocol.*      USB CDC serial protocol (docs/firmware/protocol.md)
 *
 * Arduino IDE board settings (or use scripts/build_firmware.sh):
 *   Board ............... ESP32S3 Dev Module
 *   USB Mode ............ USB-OTG (TinyUSB)
 *   USB CDC On Boot ..... Enabled
 *   PSRAM ............... OPI PSRAM  (WROOM-1-N16R8)
 *   Flash Size .......... 16MB, partition app3M_fat9M_16MB
 */

#include <Arduino.h>
#include <USB.h>
#include <USBHIDKeyboard.h>

#include "config.h"
#include "state.h"
#include "orientation.h"
#include "pages.h"
#include "display.h"
#include "boot_splash.h"
#include "media.h"
#include "input.h"
#include "leds.h"
#include "sensors.h"
#include "haptics.h"
#include "protocol.h"

USBHIDKeyboard Keyboard;

void setup() {
    // Screens first — USB, NVS and a missing SD card used to steal seconds
    // before a pixel appeared. Shared RST + batched SLPOUT means the logo
    // can paint as soon as the panels exist.
    displayInit();
    playBootSplash();

    // 48 SET_KEY lines arrive back-to-back during profile sync while NVS
    // writes block the loop — the default 256 B CDC RX buffer overflows
    // and corrupts commands. Must be set before begin().
    // Must hold a full 128x128 RGB565 frame (32768 B) plus headroom: the
    // host pushes frames at full USB speed and any blocking blit in loop()
    // would otherwise overflow the ring and drop the frame's tail.
    Serial.setRxBufferSize(40960);
    Serial.begin(115200);
    Keyboard.begin();
    USB.begin();

    // Slots beyond page 0 start as dark defaults; NVS then overlays
    // whatever the user has configured
    for (uint8_t s = KEY_COUNT; s < TOTAL_KEYS; s++) {
        defaultSlotConfig(s);
    }
    loadConfig();
    rebuildOrientationMaps();
    displayApplyOrientation();

    sensorsInit();        // owns Wire.begin — before hapticsInit()
    hapticsInit();
    ledsInit();
    scheduleBootReveal();

    for (int i = 0; i < KEY_COUNT; i++) {
        pinMode(KEY_PINS[i], INPUT_PULLUP);
    }

    delay(200);   // let the CDC port enumerate before announcing
    printDeviceInfo();
    ensureSdMounted();    // after the logo: a dead card blocks 1–2 s
}

void loop() {
    // Keys first — never let serial uploads or NVS block switch handling
    serviceKeys();
    serviceTapTimeouts();
    serviceHidRelease();
    servicePressFeedback();

    handleSerialInput();
    serviceFrameReceive();
    serviceConfigFlush();

    serviceAnimation();
    serviceDrawAll();
    serviceBacklightFade();
    serviceHostRevealFallback();

    serviceSensors();
    serviceLeds();
    serviceHaptics();

    if (companionMode && (millis() - lastCompanionMs) > COMPANION_TIMEOUT_MS) {
        companionMode = false;
        ledsSetLink(false);
    }
}

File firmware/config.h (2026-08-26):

/**
 * config.h — every pin, constant, and tunable in one place.
 *
 * The canonical pinout lives in hardware/pinout.py: the PCB/schematic
 * generators cross-check this file against it at generation time and
 * hard-fail on divergence. If you change a pin here, change pinout.py
 * and regenerate the hardware in the same commit.
 */

#pragma once

#include <Arduino.h>

// ── Identity ────────────────────────────────────────────────────────
#define FIRMWARE_VERSION "0.14.5"
#define PROTOCOL_VERSION 14

// ── Debug ───────────────────────────────────────────────────────────
// 1 → emit {"event":"dbg",...} lines for every draw/blit/batch change so
// the companion console shows exactly which slot hits which display.
#define DEBUG_DRAW 1

// ── Pins (ESP32-S3-WROOM-1 on the Rev E carrier PCB) ────────────────
// SPI bus A (FSPI): panels J1-J3 + microSD
#define PIN_MOSI_A 11
#define PIN_SCK_A  12
#define PIN_MISO   15   // SD read (displays are write-only)
#define PIN_DC_A   14
#define PIN_SD_CS  16   // microSD chip select
// SPI bus B (HSPI): panels J4-J6
#define PIN_MOSI_B 17
#define PIN_SCK_B  18
#define PIN_DC_B   8
// Shared display lines
#define PIN_RST 21      // reset, all panels on both buses
#define PIN_BL  13      // backlight (LEDC PWM — ALS auto-dim)
// I2C: IMU + ambient light + haptic driver + Qwiic port
#define PIN_SDA     6
#define PIN_SCL     7
#define PIN_IMU_INT 9   // LSM6DS3TR-C INT1 (pickup / tap)
// Outputs
#define PIN_LED_DATA  48  // SK6812 chain (via level shifter)
#define PIN_PIEZO     43  // LEDC tone
#define PIN_HAPTIC_EN 44  // DRV2605L enable

// Legacy aliases (pre-Rev E single-bus names)
#define PIN_MOSI PIN_MOSI_A
#define PIN_SCK  PIN_SCK_A
#define PIN_DC   PIN_DC_A

// ── LEDs ────────────────────────────────────────────────────────────
// Logical order: 0-5 = per-key status (J1..J6), 6 = rear-left (link),
// 7 = rear-right (SD). LED_CHAIN[] in leds.cpp maps chain position →
// logical index (physical routing order differs).
#define LED_COUNT 8
#define LED_REAR_LINK 6
#define LED_REAR_SD   7

// Per-module chip selects and key switch inputs, in wiring order J1..J6.
extern const uint8_t CS_PINS[];
extern const uint8_t KEY_PINS[];

// ── Geometry ────────────────────────────────────────────────────────
#define KEY_COUNT 6                          // physical screens/switches
#define MAX_PAGES 8                          // slot storage ceiling
#define TOTAL_KEYS (KEY_COUNT * MAX_PAGES)   // global key slots (48)
#define FRAME_BYTES (128 * 128 * 2)          // one RGB565 key frame

// ── Media ───────────────────────────────────────────────────────────
// Transparency sentinel (big-endian bytes 0x08,0x21): icon pixels with
// this value adopt the key's background color at draw time, so recoloring
// a key never requires re-uploading its image.
#define TRANSPARENT_HI 0x08
#define TRANSPARENT_LO 0x21

// ── Reserved HID codes ──────────────────────────────────────────────
// These sit in the 224–239 gap of the Arduino keymap — clear of F13–F24
// at 240+ and named keys below 0xDA. A key bound to a page code switches
// pages on-device, standalone AND under the companion, so the firmware
// and the app never fight over page state.
// 224..229 are silent sentinels: never typed; they exist so the companion
// can arm multi-tap detection for host-only actions.
#define HID_INTERNAL_MIN 224
#define HID_INTERNAL_MAX 239
#define HID_PAGE_PREV 230
#define HID_PAGE_NEXT 231
#define HID_PAGE_BASE 232   // 232..239 → go to page 0..7

// ── Timing ──────────────────────────────────────────────────────────
#define DEBOUNCE_MS 50
// Multi-tap: max ms between taps of one sequence. Only keys with a double
// or triple binding ever wait — single-only keys fire with zero latency.
#define TAP_WINDOW_MS 300
// Companion heartbeat: no PING for this long → fall back to plain HID.
#define COMPANION_TIMEOUT_MS 6000

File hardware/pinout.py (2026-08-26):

#!/usr/bin/env python3
"""
pinout.py — THE single canonical pinout + geometry source for Open Screen Deck.

Rev E. Every consumer derives from this file:

  - scripts/generate_kicad_schematic.py   (net labels, title-block tables)
  - scripts/generate_kicad_pcb.py         (pad->net map, placement grid)
  - firmware/config.h                     (cross-checked by check_firmware_config())
  - docs/pcb_design_brief.md + AGENTS.md  (hand-synced; check_firmware_config
                                           catches the firmware side)

If you change a pin here, regenerate the schematic AND the PCB and update the
docs tables in the same commit. The generators hard-fail if firmware/config.h
disagrees with this file, so divergence cannot ship silently.
"""

from __future__ import annotations

import re
from pathlib import Path

ROOT = Path(__file__).resolve().parents[1]

REV = "E"

# ── GPIO map (ESP32-S3-WROOM-1-N16R8) ───────────────────────────────
# Chosen to avoid IO35-37 (octal PSRAM on the R8 module) and to keep the
# strap pins (IO0, IO3, IO45, IO46) free of anything that could fight the
# boot voltage sampling. IO43/44 (UART0) are repurposed — debug goes over
# USB-CDC on this product.
GPIO = {
    # SPI bus A — displays J1-J3 + microSD (FSPI host, DMA)
    "MOSI_A": 11,
    "SCK_A": 12,
    "MISO": 15,      # SD read (displays are write-only)
    "DC_A": 14,
    "SD_CS": 16,
    # SPI bus B — displays J4-J6 (HSPI host, DMA)
    "MOSI_B": 17,
    "SCK_B": 18,
    "DC_B": 8,
    # Shared display lines
    "RST": 21,       # all six panels + both buses
    "BL": 13,        # backlight, LEDC PWM (ALS auto-dim)
    # I2C bus — IMU + ALS + haptic driver + Qwiic
    "SDA": 6,
    "SCL": 7,
    "IMU_INT": 9,    # LSM6DS3TR-C INT1: wake-on-pickup / tap
    # Outputs
    "LED_DATA": 48,  # SK6812 chain via 74AHCT1G125 level shifter
    "PIEZO": 43,     # LEDC tone output
    "HAPTIC_EN": 44, # DRV2605L EN
    # System
    "USB_DN": 19,
    "USB_DP": 20,
    "BOOT": 0,
}

# Per-module chip selects and key switch inputs, wiring order J1..J6.
CS = [10, 1, 2, 3, 4, 5]
KEY = [38, 39, 40, 41, 42, 47]

# Display bus split: panel index (0-based, J1..J6) -> SPI bus
PANEL_BUS = ["A", "A", "A", "B", "B", "B"]

# ── ESP32-S3-WROOM-1 module pad number for each GPIO ────────────────
# Per the Espressif ESP32-S3-WROOM-1 datasheet pin map.
WROOM_PAD = {
    0: "27", 1: "39", 2: "38", 3: "15", 4: "4", 5: "5", 6: "6", 7: "7",
    8: "12", 9: "17", 10: "18", 11: "19", 12: "20", 13: "21", 14: "22",
    15: "8", 16: "9", 17: "10", 18: "11", 19: "13", 20: "14", 21: "23",
    35: "28", 36: "29", 37: "30", 38: "31", 39: "32", 40: "33", 41: "34",
    42: "35", 43: "37", 44: "36", 45: "26", 46: "16", 47: "24", 48: "25",
}

# Net name used on schematic + PCB for each GPIO signal
SIGNAL_NET = {
    "MOSI_A": "MOSI_A", "SCK_A": "SCK_A", "MISO": "MISO", "DC_A": "DC_A",
    "MOSI_B": "MOSI_B", "SCK_B": "SCK_B", "DC_B": "DC_B",
    "RST": "RST", "BL": "BL", "SD_CS": "SD_CS",
    "SDA": "SDA", "SCL": "SCL", "IMU_INT": "IMU_INT",
    "LED_DATA": "LED_DATA_3V3", "PIEZO": "PIEZO", "HAPTIC_EN": "HAPTIC_EN",
    "USB_DN": "USB_D-", "USB_DP": "USB_D+", "BOOT": "BOOT",
}


def esp32_pad_nets() -> dict[str, str]:
    """WROOM pad number -> net name, derived from the tables above."""
    pads = {"1": "GND", "2": "+3V3", "3": "EN", "40": "GND", "41": "GND"}
    for sig, io in GPIO.items():
        pads[WROOM_PAD[io]] = SIGNAL_NET[sig]
    for i, io in enumerate(CS, start=1):
        pads[WROOM_PAD[io]] = f"CS{i}"
    for i, io in enumerate(KEY, start=1):
        pads[WROOM_PAD[io]] = f"KEY{i}"
    return pads


# ── Rev E board geometry (mm, origin = back-left corner) ────────────
BOARD_W = 59.5
BOARD_H = 108.5

COL_PITCH = 33.0   # was 28.9 — uniform 11 mm cap-to-cap gap
ROW_PITCH = 36.3   # was 38.3 — uniform 11 mm cap-to-cap gap

COL_X = [13.25, 46.25]                # (BOARD_W - COL_PITCH)/2, + COL_PITCH
ROW_Y = [17.95, 54.25, 90.55]         # (BOARD_H - 2*ROW_PITCH)/2, + n*ROW_PITCH

KEY_CENTRES = [(COL_X[c], ROW_Y[r]) for r in range(3) for c in range(2)]

# Module standoff pattern — OFFICIAL vendor drawing: 20.0 x 29.25 around
# each key centre. (22.0 x 25.3 is the KEYCAP outline from the marketing
# png — the v11/v12 misread. See docs/reference/screenkey-module/.)
STANDOFF_DX = 10.0
STANDOFF_DY = 14.625

# Corner case-screw holes = outermost standoff axes of the corner modules
CORNER_CASE_HOLES = [
    (COL_X[0] - STANDOFF_DX, ROW_Y[0] - STANDOFF_DY),
    (COL_X[1] + STANDOFF_DX, ROW_Y[0] - STANDOFF_DY),
    (COL_X[0] - STANDOFF_DX, ROW_Y[2] + STANDOFF_DY),
    (COL_X[1] + STANDOFF_DX, ROW_Y[2] + STANDOFF_DY),
]

USB_X = BOARD_W / 2  # USB-C stays centred on the rear edge

# LED chain: physical order along the data line — a clean loop with no
# crossings: rear-left → rear-right → down the right edge → up the left.
# Logical index (firmware view): 0-5 = keys J1..J6, 6 = rear link, 7 = rear SD.
LED_COUNT = 8
LED_CHAIN_REFS = ["D7", "D8", "D2", "D4", "D6", "D5", "D3", "D1"]
LED_LOGICAL = {"D1": 0, "D2": 1, "D3": 2, "D4": 3, "D5": 4, "D6": 5, "D7": 6, "D8": 7}
# firmware: chain position -> logical LED index
LED_CHAIN_TO_LOGICAL = [LED_LOGICAL[r] for r in LED_CHAIN_REFS]


# ── Firmware cross-check ─────────────────────────────────────────────
FIRMWARE_EXPECT = {
    "PIN_MOSI_A": GPIO["MOSI_A"], "PIN_SCK_A": GPIO["SCK_A"],
    "PIN_MISO": GPIO["MISO"], "PIN_DC_A": GPIO["DC_A"],
    "PIN_MOSI_B": GPIO["MOSI_B"], "PIN_SCK_B": GPIO["SCK_B"],
    "PIN_DC_B": GPIO["DC_B"],
    "PIN_RST": GPIO["RST"], "PIN_BL": GPIO["BL"], "PIN_SD_CS": GPIO["SD_CS"],
    "PIN_SDA": GPIO["SDA"], "PIN_SCL": GPIO["SCL"],
    "PIN_IMU_INT": GPIO["IMU_INT"], "PIN_LED_DATA": GPIO["LED_DATA"],
    "PIN_PIEZO": GPIO["PIEZO"], "PIN_HAPTIC_EN": GPIO["HAPTIC_EN"],
}


def check_firmware_config() -> None:
    """Hard-fail if firmware/config.h or display.cpp disagree with this file."""
    cfg = (ROOT / "firmware/config.h").read_text()
    errors: list[str] = []
    for name, want in FIRMWARE_EXPECT.items():
        m = re.search(rf"#define\s+{name}\s+(\d+)", cfg)
        if not m:
            errors.append(f"{name}: missing from firmware/config.h (want {want})")
        elif int(m.group(1)) != want:
            errors.append(f"{name}: firmware says {m.group(1)}, pinout says {want}")
    disp = (ROOT / "firmware/display.cpp").read_text()
    for arr, want in (("CS_PINS", CS), ("KEY_PINS", KEY)):
        m = re.search(rf"{arr}\[KEY_COUNT\]\s*=\s*\{{([^}}]*)\}}", disp)
        if not m:
            errors.append(f"{arr}: not found in firmware/display.cpp")
        else:
            got = [int(v) for v in m.group(1).split(",")]
            if got != want:
                errors.append(f"{arr}: firmware {got} != pinout {want}")
    if errors:
        raise SystemExit(
            "!! pinout divergence between hardware/pinout.py and firmware:\n  "
            + "\n  ".join(errors)
        )
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

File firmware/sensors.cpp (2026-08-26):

#include "sensors.h"
#include "display.h"
#include "haptics.h"
#include <Wire.h>

// ── LSM6DS3TR-C ──────────────────────────────────────────────────────
static const uint8_t IMU_ADDR        = 0x6A;   // SA0 strapped low
static const uint8_t IMU_WHO_AM_I    = 0x0F;   // reads 0x6A
static const uint8_t IMU_CTRL1_XL    = 0x10;
static const uint8_t IMU_TAP_CFG     = 0x58;
static const uint8_t IMU_WAKE_UP_THS = 0x5B;
static const uint8_t IMU_WAKE_UP_DUR = 0x5C;
static const uint8_t IMU_MD1_CFG     = 0x5E;

// ── VEML7700 ────────────────────────────────────────────────────────
static const uint8_t ALS_ADDR     = 0x10;
static const uint8_t ALS_CONF     = 0x00;
static const uint8_t ALS_DATA     = 0x04;
// gain 1, integration 100 ms → 0.0576 lux/count
static const float   ALS_LUX_PER_COUNT = 0.0576f;

static bool  imuOk = false;
static bool  alsOk = false;
static float lux   = -1.0f;
static bool  autoDim = true;

static uint32_t lastAlsMs    = 0;
static uint32_t lastPickupMs = 0;

static bool i2cWrite8(uint8_t addr, uint8_t reg, uint8_t val) {
    Wire.beginTransmission(addr);
    Wire.write(reg);
    Wire.write(val);
    return Wire.endTransmission() == 0;
}

static int i2cRead8(uint8_t addr, uint8_t reg) {
    Wire.beginTransmission(addr);
    Wire.write(reg);
    if (Wire.endTransmission(false) != 0) return -1;
    if (Wire.requestFrom(addr, (uint8_t)1) != 1) return -1;
    return Wire.read();
}

static bool i2cWrite16LE(uint8_t addr, uint8_t reg, uint16_t val) {
    Wire.beginTransmission(addr);
    Wire.write(reg);
    Wire.write((uint8_t)(val & 0xFF));
    Wire.write((uint8_t)(val >> 8));
    return Wire.endTransmission() == 0;
}

static int32_t i2cRead16LE(uint8_t addr, uint8_t reg) {
    Wire.beginTransmission(addr);
    Wire.write(reg);
    if (Wire.endTransmission(false) != 0) return -1;
    if (Wire.requestFrom(addr, (uint8_t)2) != 2) return -1;
    uint16_t lo = Wire.read(), hi = Wire.read();
    return (int32_t)((hi << 8) | lo);
}

void sensorsInit() {
    Wire.begin(PIN_SDA, PIN_SCL, 400000);

    // IMU: accel 104 Hz / ±2 g, wake-up interrupt routed to INT1
    imuOk = i2cRead8(IMU_ADDR, IMU_WHO_AM_I) == 0x6A;
    if (imuOk) {
        i2cWrite8(IMU_ADDR, IMU_CTRL1_XL, 0x40);      // 104 Hz, 2 g
        i2cWrite8(IMU_ADDR, IMU_TAP_CFG, 0x80);       // enable interrupts
        i2cWrite8(IMU_ADDR, IMU_WAKE_UP_DUR, 0x00);
        i2cWrite8(IMU_ADDR, IMU_WAKE_UP_THS, 0x02);   // ~62.5 mg threshold
        i2cWrite8(IMU_ADDR, IMU_MD1_CFG, 0x20);       // wake-up → INT1
        pinMode(PIN_IMU_INT, INPUT);
    }

    // ALS: gain 1, 100 ms integration, power on
    alsOk = i2cWrite16LE(ALS_ADDR, ALS_CONF, 0x0000);
    if (alsOk) {
        delay(3);
        alsOk = i2cRead16LE(ALS_ADDR, ALS_DATA) >= 0;
    }
}

bool imuPresent() { return imuOk; }
bool alsPresent() { return alsOk; }
float alsLux()    { return lux; }

void setAutoDim(bool on) { autoDim = on; }
bool autoDimEnabled()    { return autoDim; }

/** Map lux → backlight level: dim room ≈ 60, office ≈ 180, sunlit ≈ 255. */
static uint8_t targetLevelForLux(float lx) {
    if (lx < 5)    return 60;
    if (lx > 1000) return 255;
    // log ramp between 5 and 1000 lux
    float t = (logf(lx) - logf(5.0f)) / (logf(1000.0f) - logf(5.0f));
    return (uint8_t)(60 + t * 195);
}

void serviceSensors() {
    uint32_t now = millis();

    // IMU pickup: INT1 latches high on wake-up motion
    if (imuOk && digitalRead(PIN_IMU_INT) == HIGH &&
        (now - lastPickupMs) > 1500) {
        lastPickupMs = now;
        if (Serial) Serial.println("{\"event\":\"pickup\"}");
        hapticPlay(24);   // sharp tick — the deck acknowledges being lifted
    }

    // ALS poll @ 2 Hz with a smooth one-step-per-poll dim so brightness
    // changes glide instead of snapping
    if (alsOk && (now - lastAlsMs) >= 500) {
        lastAlsMs = now;
        int32_t raw = i2cRead16LE(ALS_ADDR, ALS_DATA);
        if (raw >= 0) {
            lux = raw * ALS_LUX_PER_COUNT;
            if (autoDim) {
                uint8_t cur = displayBrightness();
                uint8_t tgt = targetLevelForLux(lux);
                if (tgt != cur) {
                    int step = ((int)tgt - (int)cur) / 4;
                    if (step == 0) step = tgt > cur ? 1 : -1;
                    displaySetBrightness((uint8_t)((int)cur + step));
                }
            }
        }
    }
}

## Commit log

2026-07-04 Initial release: Open Screen Deck v11
    Per-key LCD macro pad: 6x Waveshare ScreenKey modules on an ESP32-S3
    carrier PCB, 3D-printed case, USB HID + CDC serial.
    - KiCad PCB (rev B): routed, DRC-clean, Gerbers + BOM + pick-and-place
    - Enclosure v11 (OpenSCAD + STLs): one-screw corner stack - four
    countersunk M2x25 run tray -> carrier -> module nut -> top-plate
    insert, hidden under the rubber feet
    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
    [assembly_steps.scad, bom.csv, bom_assembly.csv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]
2026-07-11 Companion app v0.2: dynamic pages, live tiles, plugin store, in-app firmware updater
    - Firmware v0.11: user-resizable pages (SET_PAGES 1-8, NVS-persisted), 48 key
    slots, page-switch HID codes 230-239, SET_FACE draw-only frames for tiles
    - Companion: Tauri desktop app with page tabs (+/- to add/remove), live tiles
    (clock/timer/CPU/volume/now-playing/OBS), drag-to-swap keys, copy/paste,
    undo/redo, onboarding wizard with starter profiles
    - Plugin store: registry-driven install/update/uninstall, hot reload, scaffold
    tool; reference plugins (Home Assistant webhook, Pomodoro)
    - In-app firmware updater (espflash) with bootloader recovery (download-latch
    clear + RTC watchdog reset); bootlo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
    [bom.csv, bom_jlcpcb.csv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]
2026-07-12 Docs: purge legacy design docs from the site, app-first home with downloads
    - Internal working docs (design briefs, roadmaps, Tier A/B history) are
    excluded from the published site — they stay in the repo for contributors
    - hardware/architecture.md rewritten as current system architecture: block
    diagram, canonical GPIO map, media tiers, SPI bandwidth budget
    - Stale references fixed across pages: DevKit-era PCB layout and BOM,
    F13-F18 -> F13-F24, old protocol/firmware version examples, dead
    firmware roadmap
    - Home page rethought around the app: download buttons (wired to the
    latest GitHub release via API, releases page fallback), app feature
    tour, three-pieces cards, start-here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
2026-07-12 Docs: dropdown menus on the top navigation tabs
    Section pages are now visible on hover from the main menu — a theme
    partial override renders each tab's children as a dropdown (with an
    Overview entry for section landing pages). The theme's contain: content
    on the tab list was paint-clipping the panels; overridden.
2026-07-12 Make every page's sidebar earn its place
    - Profiles: active-profile card (name, pages, media, last save), library
    count, and real actions — new from deck, import file, export all
    - Plugins: live installed/action counts, check-for-updates (opens the
    update prompt), reload, open plugin folder
    - Storage: on-deck media counts (icons / animated keys) + card layout
    - Settings: firmware version card; dropped the stale "coming soon" copy
    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
2026-07-12 Firmware: split the monolith into documented modules
    firmware/main.cpp (961 lines) becomes a proper sketch with focused,
    commented modules:
    config.h pins, constants, reserved HID codes, timing
    state.* per-key config + NVS persistence
    orientation.* deck rotation, logical<->physical key mapping
    pages.* multi-page state and slot arithmetic
    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
2026-07-12 Make e2e shortcuts and tile checks platform-robust
    Meta+z never fires on Linux CI runners — tests now use ControlOrMeta
    (the app already accepts Ctrl or Cmd). The clock-tile tick assertion
    polls instead of using a fixed wait.
2026-07-14 Hardware Rev C: microSD was flipped inward — fix connector and case slot
    Two build-verified problems from the first assembled unit:
    - PCB: J8 (Hirose DM3D-SF) was rotated so the card inserted from the
    middle of the board. Rotated 180 deg (rot -90 -> 90) so the mouth faces
    the x=55 edge, re-routed SD_CS/MOSI/SCK/MISO/+3V3 to the mirrored pads,
    detoured KEY6 around a relocated shield pad, and re-stitched GND. DRC
    back to the Rev B baseline (0 new violations, 0 unconnected). Silk and
    gerbers regenerated as REV C.
    - Enclosure v12: the SD slot was cut in the wrong side wall — KiCad's
    top view mirrors x when the board sits component-up, which v11 missed.
    Slot moved to the wall a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
    [corner_spacers_x4_v11.stl, corner_spacers_x4_v12.stl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]
2026-07-14 Rev C: reroute J8 with freerouting instead of hand-drawn edge channels
    The hand-routed approaches ran two traces 0.25 mm from the board edge.
    Ripped them out and let freerouting route SD_CS/MOSI/SCK/MISO/+3V3 to
    the rotated connector — everything now stays >= 1.3 mm from the edge
    (the closest copper is the connector's own pads). Restored the via
    drills the SES import inflated, cleaned up freerouting's one dangling
    stub, DRC back to baseline (0 new violations, 0 unconnected). Gerbers
    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
    [data_streamdeck-B_Courtyard.gbr, data_streamdeck-B_Cu.gbl, data_streamdeck-B_Fab.gbr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]
2026-07-20 Hardware Rev D + enclosure v13: real module dimensions from vendor CAD
    The marketing outline drawing labels the KEYCAP (21.89 x 25.13, which
    rounds to the 22.0/25.3 we misread as the hole pattern). Waveshare now
    publishes official CAD (STEP/DXF/PDF, 2026-07-10) with the truth:
    mounting holes 20.0 x 29.25, keycap 21.89 x 25.13 rectangular, factory
    standoffs 8.0 mm, module PCB 26.01 x 35.31, cap-to-rear-PCB 16.0.
    - PCB Rev D: all 16 mounting holes (12 standoff + 4 corner case screws)
    moved to the real pattern; skip positions re-derived (ESP32 / USB /
    microSD conflicts); one GND stitch via relocated; DRC clean.
    - Enclosure v13: rectangular keycap apertures (+0.6 clearance), hole
    pattern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
    [corner_spacers_x4_v12.stl, corner_spacers_x4_v13.stl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]
2026-08-26 Rev E hardware, firmware 0.14.5, and docs for sensors and glow
    Ship the dual-SPI carrier with IMU, ambient light, haptics, SK6812 edge
    LEDs and Qwiic, plus companion flash overlay and GitHub Pages that match
    the board.
    [bom.csv, bom_assembly.csv, bom_jlcpcb.csv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]
2026-08-26 Rewrite site copy for builders, not a product pitch
    Lead with order → print → assemble → flash. The companion stays optional
    and the homepage primary action is starting a build.
2026-08-26 Cut GitHub Releases from app-v* tags, including firmware bins
    Pushing main never created a release — only the app-v0.1.0 tag had. Attach
    firmware .bins to the same release and install Adafruit NeoPixel in CI so
    0.14.5 compiles.
2026-08-26 Point the README at Releases for the app and firmware bins
    Spell out Rev E / v14 files, 0.14.5 flashing, and that only app-v* tags
    cut a GitHub Release.
2026-08-26 Fix simulator tap-arm so multi-tap e2e (and CI) pass.
    USB-only connect-sync gating never flipped true in the simulator, and a
    setTimeout(0) was cancelled by Strict Mode remount, so h2 never reached
    the device and Test-mode clicks fired as instant singles.
